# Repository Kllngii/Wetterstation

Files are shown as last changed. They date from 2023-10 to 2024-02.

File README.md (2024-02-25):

# Wetterstation

Mit einem WiFi-fähigen Mikrocontroller sollen verschiedene Sensordaten erfasst- und aufbereitet werden. 

Für die WiFi-Anbindung wird ein Raspberry Pi Pico W verwendet, der mit zwei Kernen und einem WLAN/Bluetooth Modul genug Leistung
zur Verfügung stellen kann. 

Die erfassten Daten werden auf einem lokalen (Touch)-Display ausgegeben, durch die WLAN-Fähigkeit könnten die Daten zukünftig auch an eine lokale Datenbank übertragen werden (MySQL/Docker, graphische Aufbereitung mit Grafana o.ä.)

# Sensoren
Folgende Sensoren werden verwendet (das Projekt ist beliebig skalierbar):
## Interne Messgruppe
- BME280 (Temperatur, Luftfeuchtigkeit, Luftdruck)
- MH-Z19C (CO2)
## Externe Messgruppe
- BME280 (Tempertur, Luftfeuchtigkeit, Luftdruck)
- DCF77-Empfänger (Uhrzeit und Wettervorhersage)
    - Der DCF77-Empfänger empfängt das Signal eines Zeitzeichensenders, das neben aktuellen Zeitinformationen eine Wettervorhersage beinhaltet. Diese ist allerdings verschlüsselt. verfügbaren GPIO Pins und Rechenleistung wird die Entschlüsselung auf dem internen Modul vorgenommen. Mit der Nutzung des ESP8266 als Außenmodul ist das ganz sinnvoll, weil der nicht so viele GPIO Pins frei verfügbar hat, ein MSP430 sollte das aber ohne grö0eren Rechenaufwand schaffen. Für die Entschlüsselung der Daten wird ein HKW581 Modul benötigt. 
## Eventuelle Erweiterungen
- DHT22 (Temperatur, Luftfeuchtigkeit)
- PT100/PT1000 (Zwei- oder Vierleitermessung, dazu Konstantstromquelle + rel. hochauflösender ADC (min. 16 bit))
- CCS811 (CO2 und flüchtige organische Verbindungen (TVOC))
- Niederschlagsmessung
- Windgeschwindigkeit und Windrichtung

# Struktur des Repos
- **LaTeX** [Dokumentation des Projekts](#dokumentation)
- **wetterstation-arduinosensor** [Arduino als Sensormodul](#arduino-als-sensormodul)
- **wetterstation-ui/** [Desktop App](#desktop-app)
- **slint-pico/** [Raspberry Pico mit Touchscreen als Interface](#raspberry-pico-mit-touchscreen-als-interface)
- **pcbs/** Hier findet man Schaltpläne und PCBs der Module als [KiCad](https://www.kicad.org) Projekt

# Desktop App






*TODO* Hier müsste man erklären was die Desktop-App ist 

# Dokumentation

Das LaTeX Dokument in diesem Ordner ist die Dokumentation des Projekts.

# Arduino als Sensormodul



Ein kleiner Beispiel-Sketch, der einen Arduino (Uno) benutzt, um die I2C- und Onewire-Sensoren anzusteuern.

# Raspberry Pico mit Touchscreen als Interface 





*TODO* Hier müsste man erklären was die Raspberry-Pi-Pico-App ist

# Aktivität
Repobeats analytics image

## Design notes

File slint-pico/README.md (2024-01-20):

# Raspberry Pico Wetterstation-UI





Nutzt [Slint](https://slint-ui.com), um eine hübsche UI auf einem Touch-Display anzuzeigen.

## Usage

### Auf einem PC testen (Simulator)
```
cargo run --features simulator
```

### Auf einem [RaspberryPi Pico](https://www.raspberrypi.com/products/raspberry-pi-pico/) mit [2.8 inch Waveshare Touch Screen](https://www.waveshare.com/pico-restouch-lcd-2.8.htm) ausführen:

#### 1. Target RP2040 hinzufügen:
```
rustup self update
rustup update stable
rustup target add thumbv6m-none-eabi
```

#### 2. UF2-Images-Tool für den RP2040 installieren:
```
cargo install elf2uf2-rs --locked
``` 

#### 3. Korrekten Runner auswählen:
In der Datei `.cargo/config.toml` muss der richtige Runner ausgewählt werden,
indem alle anderen Runner auskommentiert werden.
- Wird der Pico im USB-Bootloader-Modus angeschlossen: `elf2uf2-rs` auswählen
- Der Pico wird über eine Debug Probe geflasht: `probe-run` wählen

#### 4. Auf RPico ausführen:
```
cargo run --target=thumbv6m-none-eabi --features=pico --release
```

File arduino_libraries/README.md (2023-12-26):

# arduino_libraries

Hier liegen alle Bibliotheken, die in der Arduino IDE verwendet werden und im lokalen libraries-Ordner enthalten sind. 

DCF77 und CO2 gehören nicht dazu, weil sie modifiziert werden mussten und ohnehin schon Teil von

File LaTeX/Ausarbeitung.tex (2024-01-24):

\documentclass[a4paper,11pt]{article}
\usepackage[utf8]{inputenc} % Sonderzeichen schreiben können
\usepackage[ngerman]{babel} % Deutsche Abbildungszeichen
\usepackage{graphicx}   % Graphiken einfügen
\usepackage{fancyhdr}   % Für Kopf- und Fusszeile
\usepackage{geometry}   % Seitenränder definieren
\usepackage{tikz}       % Zum Regler zeichnen
\usepackage{multirow}   % Multirow in Tabellen
\usepackage{float}      % Um Bilder genau an diesem Punkt einzufuegen [H]
\usepackage{fancyvrb}   % Box um Verbatim Code
\usepackage{microtype}  % Automatische Anpassung der Zeilenmaße, dass unschöne Umbrüche vermieden werden
\usepackage{mathtools}  % Für Text auf/unter Pfeilen
\usepackage{pgfplots}   % Plot zusammen mit tikzpicture
\usepackage{makecell}   % Umbruch in tabellen
\usepackage{enumitem}   % Einruecken bei itemize verhindern
\usepackage{titlesec}   % Elemente unter subsubsection erzeugen
\usepackage{trfsigns}   % Transformationssymbole
\usepackage{amsmath}    % Umbruch in Formeln
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
\definecolor{codepurple}{rgb}{0.58,0,0.82}
\definecolor{backcolour}{rgb}{0.95,0.95,0.92}

\lstdefinestyle{mystyle}{
    backgroundcolor=\color{backcolour},   
    commentstyle=\color{codegreen},
    keywordstyle=\color{magenta},
    numberstyle=\tiny\color{codegray},
    stringstyle=\color{codepurple},
    basicstyle=\ttfamily\footnotesize,
    breakatwhitespace=false,         
    breaklines=true,                 
    captionpos=b,                    
    keepspaces=true,                 
    numbers=left,                    
    numbersep=5pt,                  
    showspaces=false,                
    showstringspaces=false,
    showtabs=false,                  
    tabsize=2
}

\lstset{literate=
	{°}{{\textdegree}}1 {µ}{{\textmu}}1
	{á}{{\'a}}1 {é}{{\'e}}1 {í}{{\'i}}1 {ó}{{\'o}}1 {ú}{{\'u}}1
	{Á}{{\'A}}1 {É}{{\'E}}1 {Í}{{\'I}}1 {Ó}{{\'O}}1 {Ú}{{\'U}}1
	{à}{{\`a}}1 {è}{{\`e}}1 {ì}{{\`i}}1 {ò}{{\`o}}1 {ù}{{\`u}}1
	{À}{{\`A}}1 {È}{{\`E}}1 {Ì}{{\`I}}1 {Ò}{{\`O}}1 {Ù}{{\`U}}1
	{ä}{{\"a}}1 {ë}{{\"e}}1 {ï}{{\"i}}1 {ö}{{\"o}}1 {ü}{{\"u}}1
	{Ä}{{\"A}}1 {Ë}{{\"E}}1 {Ï}{{\"I}}1 {Ö}{{\"O}}1 {Ü}{{\"U}}1
	{â}{{\^a}}1 {ê}{{\^e}}1 {î}{{\^i}}1 {ô}{{\^o}}1 {û}{{\^u}}1
	{Â}{{\^A}}1 {Ê}{{\^E}}1 {Î}{{\^I}}1 {Ô}{{\^O}}1 {Û}{{\^U}}1
	{ã}{{\~a}}1 {ẽ}{{\~e}}1 {ĩ}{{\~i}}1 {õ}{{\~o}}1 {ũ}{{\~u}}1
	{Ã}{{\~A}}1 {Ẽ}{{\~E}}1 {Ĩ}{{\~I}}1 {Õ}{{\~O}}1 {Ũ}{{\~U}}1
	{œ}{{\oe}}1 {Œ}{{\OE}}1 {æ}{{\ae}}1 {Æ}{{\AE}}1 {ß}{{\ss}}1
	{ű}{{\H{u}}}1 {Ű}{{\H{U}}}1 {ő}{{\H{o}}}1 {Ő}{{\H{O}}}1
	{ç}{{\c c}}1 {Ç}{{\c C}}1 {ø}{{\o}}1 {Ø}{{\O}}1 {å}{{\r a}}1 {Å}{{\r A}}1
	{€}{{\euro}}1 {£}{{\pounds}}1 {«}{{\guillemotleft}}1
	{»}{{\guillemotright}}1 {ñ}{{\~n}}1 {Ñ}{{\~N}}1 {¿}{{?`}}1 {¡}{{!`}}1 
}

\lstdefinelanguage{slint}{
	morekeywords={export, component, global, struct, inherits},
	sensitive=true,
	morecomment=[l]{//}, % line comment
	morecomment=[s]{/*}{*/}, % start delimiter, end delimiter
	morestring=[b]", % string quotes
	morestring=[d]',
}

\lstdefinelanguage{rust}{
	morekeywords={export, global, struct, loop, for, while, do, if, else, let, match, const, continue, break, None, Some, Option},
	sensitive=false,
	morecomment=[l]{//}, % line comment
	morecomment=[n]{/*}{*/}, % start delimiter, end delimiter, nested
	morestring=[b]", % string quotes
	morestring=[d]',
}

\lstset{style=mystyle}

\titleclass{\subsubsubsection}{straight}[\subsection]

\newcounter{subsubsubsection}[subsubsection]
\renewcommand\thesubsubsubsection{\thesubsubsection.\arabic{subsubsubsection}}
\renewcommand\theparagraph{\thesubsubsubsection.\arabic{paragraph}} % optional; useful if paragraphs are to be numbered

\titleformat{\subsubsubsection}
  {\normalfont\normalsize\bfseries}{\thesubsubsubsection}{1em}{}
\titlespacing*{\subsubsubsection}
{0pt}{3.25ex plus 1ex minus .2ex}{1.5ex plus .2ex}

\makeatletter
\renewcommand\paragraph{\@startsection{paragraph}{5}{\z@}%
  {3.25ex \@plus1ex \@minus.2ex}%
  {-1em}%
  {\normalfont\normalsize\bfseries}}
\renewcommand\subparagraph{\@startsection{subparagraph}{6}{\parindent}%
  {3.25ex \@plus1ex \@minus .2ex}%
  {-1em}%
  {\normalfont\normalsize\bfseries}}
\def\toclevel@subsubsubsection{4}
\def\toclevel@paragraph{5}
\def\toclevel@paragraph{6}
\def\l@subsubsubsection{\@dottedtocline{4}{7em}{4em}}
\def\l@paragraph{\@dottedtocline{5}{10em}{5em}}
\def\l@subparagraph{\@dottedtocline{6}{14em}{6em}}
\makeatother

\setcounter{secnumdepth}{4}
\setcounter{tocdepth}{4}

\newenvironment{nospaceflalign*}
 {\setlength{\abovedisplayskip}{0pt}\setlength{\belowdisplayskip}{0pt}%
  \csname flalign*\endcsname}
 {\csname endflalign*\endcsname\ignorespacesafterend}

\pagestyle{fancy}
\fancyhf{}
\setlength{\headheight}{28.1pt} % Höhe der Kopfzeile
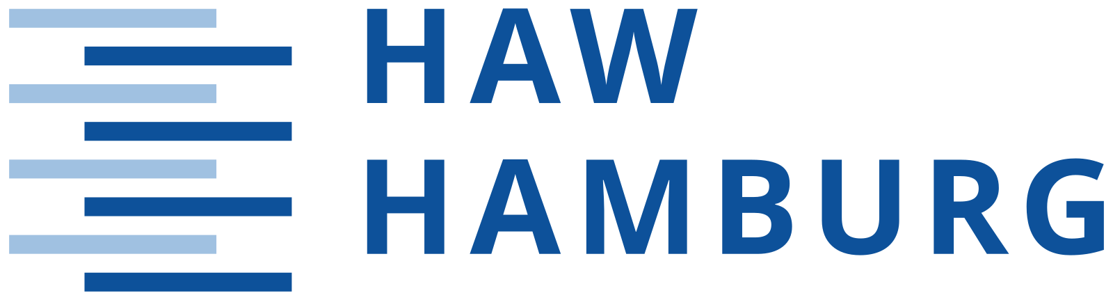
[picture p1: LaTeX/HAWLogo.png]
\rhead{}    % HAW Logo in Kopfzeile einfügen
\lhead{Bussysteme und Sensorik}  % Beschreibung in Kopfzeile

\renewcommand{\footrulewidth}{0.4pt}    % Linie in Fußzeile einfügen
\rfoot{\thepage}    % Seitenzahlen einfügen
\lfoot{Department Informations- und Elektrotechnik}   % Fusszeile linksbündig

\begin{document}
%Titelseite
\begin{titlepage}

  \begin{figure}
    \centering
    
  \end{figure}

  \vspace*{2cm}
  \centering
  {\scshape\Large Bussysteme und Sensorik \par}
  \vspace{1cm}
  {\scshape\LARGE Entwicklung eines Hubs zur Erfassung und graphischen Darstellung von Sensordaten \par}
  \vspace{0.5cm}
  {\scshape\large Wintersemester 2023/2024 \par}
  \vspace{5cm}

  \raggedright
  Ausarbeitung von:

  \vspace{0.5cm}
  Lasse Kelling \\
  2590639

  \vspace{0.2cm}
  Fabian Schmalenbach \\
  2514071

  \vspace{0.5cm}
  Abgabedatum: 24.01.2024

  \vspace{0.5cm}
  Prüfer: Prof. Dr. R. Fitz

\end{titlepage}

\newpage
\addtocontents{toc}{\protect\thispagestyle{empty}}
\tableofcontents
\thispagestyle{empty}
\newpage

\setcounter{page}{1}    % Seitenzähler sicherheitshalber zurücksetzen

\section{Projektbeschreibung}
\label{sub:projektbeschreibung}

Ziel des Projekts ist die Entwicklung eines Sensorhubs, der Sensordaten erfasst und auf einem Display darstellt.
Bei den Sensoren handelt es sich in erster Linie um Umweltdaten, die aktuelle Parameter der Umgebung erfassen.
Das Projekt kann daher grob mit einer Wetterstation verglichen werden. Zusätzlich zu den Sensordaten kann der Sensorhub
die aktuelle Zeit und eine Wettervorhersage über das DCF77-Signal empfangen. 

\subsection{Anforderungen}
\label{subsub:anforderungen}

Es wurden keine verpflichtenden Anforderungen gestellt, das Projekt soll thematisch aber zum Modul
"Bussysteme und Sensorik" passen. Daraus lassen sich für das spezifische Projekt Anforderungen stellen bzw. ableiten:

\begin{itemize}
  \item Verwendung eines oder mehrerer Bussysteme zur Kommunikation zwischen Mikrocontrollern
  \item Nutzung diverser Sensoren mit unterschiedlichen Anbindungen für Vielfältigkeit
  \item Analog zu herkömmlichen Wetterstationen, soll diese ebenfalls über einen Außensensor verfügen
  \item Die Wetterstation soll über eine Wettervorhersage verfügen
  \item Der Sensorhub soll skalier- und erweiterbar sein
\end{itemize}

\noindent
Aus diesen Anforderungen lassen sich direkt Vorgaben für das Projekt ableiten:
\begin{itemize}
  \item Nutzung mehrerer Mikrocontroller, die miteinander über ein Bussystem kommunizieren
  \item Verwendung digitaler Sensoren, die Standardprotokolle wie I2C, SPI oder UART unterstützen
  \item Entwicklung eines Außensensors, der drahtlos mit dem Sensorhub kommunizieren kann
  \item Anbindung des Sensorhubs ans Internet oder Empfang von Wettervorhersagen via Funk (DCF77)
  \item Nutzung ausreichend leistungsstarker Mikrocontroller, die genügend Leistungs- und Peripheriereserven haben, um weitere Geräte anzubinden
\end{itemize}

\subsection{Entwicklung}

Für die Entwicklung wurde ein Repository in GitHub angelegt, um die gemeinsame Arbeit am Projekt zu vereinfachen. Neben dem Quellcode sind dort auch Testprogramme
und die KiCad und Gerber Dateien für die Platinen abgelegt. 

\vspace{0.2cm}
\noindent
Das Repository ist unter folgendem Link erreichbar: \url{https://github.com/Kllngii/Wetterstation}.

\section{Systembeschreibung}
\label{sub:systembeschreibung}

\subsection{Systemaufbau}
\label{subsub:systemaufbau}

\begin{figure}[H]
  \centering
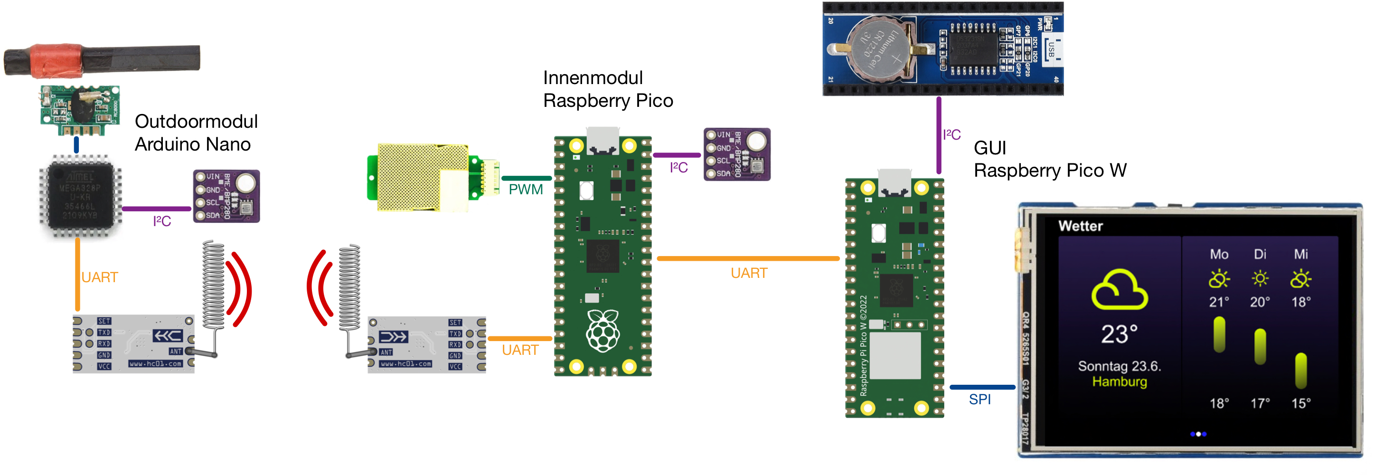
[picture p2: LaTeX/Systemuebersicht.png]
  
  \caption{Übersicht der Systemkomponenten}
  \label{fig:systemuebersicht}
\end{figure}

Die obige Abbildung \ref{fig:systemuebersicht} zeigt abstrakt alle Komponenten des Systems. Die jeweiligen Komponenten über dem Mikrocontroller Symbol
zeigen jeweils die angeschlossenen Sensoren bzw. Bildschirme. Ebenfalls ist grob die Kommunikation zwischen den Mikrocontrollern erkennbar. 

\vspace{0.2cm}
\noindent
Ganz links ist der Außensensor dargestellt, an den ein Sensor zur Messung von Temperatur, Luftfeuchtigkeit und Luftdruck angeschlossen ist. 
Außerdem verfügt dieser über eine Antenne, um das DCF77-Signal zu empfangen, welches die aktuelle Zeit und eine Wettervorhersage beinhaltet (siehe Abschnitt \ref{subsubsub:dcf77}).
Der Sensor sendet die empfangenen Daten zyklisch per 433 MHz Sender an den Sensorhub. 

\vspace{0.2cm}
\noindent
Der Sensorhub besteht aus zwei Mikrocontrollern, die über eine serielle Schnittstelle (UART) miteinander kommunizieren. Der in Abbildung \ref{fig:systemuebersicht} mittlere Mikrocontroller
empfängt die Daten des Außensensors und leitet diese weiter an den verbundenen Mikrocontroller. Da die Daten zur Wettervorhersage verschlüsselt sind und der Außensensor möglichst
wenig Energie verbrauchen soll, müssen die Daten vom Mikrocontroller entschlüsselt werden. Dazu werden die entsprechenden Datenpakete abgefangen, dekodiert und anschließend weitergesendet. 
Der Mikrocontroller verfügt außerdem wie der Außensensor über einen Sensor zur Messung von Temperatur, Luftfeuchtigkeit und Luftdruck (wobei der Luftdruck im Innenraum nicht gemessen wird). 
Zusätzlich ist ein CO2 Sensor verbaut, der die Konzentration im Raum misst. 

\vspace{0.2cm}
\noindent
In der Übersicht ganz rechts ist der Mikrocontroller, der alle Daten empfängt und auf einem Touchdisplay darstellt. Da der Sensor über ein WLAN-Modul verfügt, wäre theoretisch
zusätzlich die Übertragung der Daten per WLAN an einen Server o.ä. möglich, der alle Daten speichert und diese anderen Geräten zur Verfügung stellt. 

\subsection{Sensorik}
\label{subsub:sensorik}

Zur Erfassung der Umweltparameter werden aktuell zwei verschiedene Sensoren eingesetzt. Der BME280 erfasst Lufttemperatur, Luftfeuchtigkeit und Luftdruck. 
Der MHZ19C wird zur Erfassung der CO2 Konzentration im Raum eingesetzt. In den folgenden beiden Abschnitten werden die Sensoren beschrieben. 

\vspace{0.2cm}
\noindent
Das Außenmodul verfügt außerdem über eine 77,5 kHz Empfangsantenne, um das Zeitzeichensignal DCF77 zu empfangen. Daraus lässt sich die aktuelle Zeit ablesen,
außerdem wird eine Wettervorhersage mit übertragen, die ausgewertet wird. 

\subsubsection{BME280}
\label{subsubsub:bme280}

Beim BME280 handelt es sich um einen effizienten Sensor von Bosch, der zur Erfassung von Temperatur, Luftfeuchtigkeit und Luftdruck eingesetzt wird. 
Der Sensor verfügt über ein I2C und SPI Interface.
Beim zyklischen Auslesen aller Sensordaten mit 1 Hz liegt die Stromaufnahme laut Datenblatt bei 3,6 $\mu$A, weshalb sich der Sensor ideal für die Anwendung in Sensormodulen mit Batteriebetrieb eignet. 

\noindent
Der Sensor verfügt über die folgenden Messbereiche:
\begin{itemize}
  \item Temperatur: -40°C - +85°C ($\pm$ 0,5°C)
  \item Luftfeuchtigkeit: 0 - 100\% rel. Feuchtigkeit ($\pm$ 3\%)
  \item Druck: 250 - 1250 hPa ($\pm$ 1 hPa)
\end{itemize}

\noindent
Mit diesen Spezifikationen eignet sich der Sensor für die Anwendung im Innen- und Außenbereich. 

\noindent
Für das Projekt wird ein Sensorshield verwendet, welches nur den I2C Bus herausführt. Die Kommunikation mit dem Sensor erfolgt daher über I2C. 

\subsubsection{MHZ19C}
\label{subsubsub:mhz19c}

Der MHZ-19C ist ein Infrarot CO2-Sensor, der die CO2 Konzentration mittels nicht-dispersiver Infrarot-Spektroskopie misst. Dabei wird zyklisch mit einer Infrarotlampe
und einem Photosensor die CO2-Konzentration anhand der Reflexion des Lichts durch CO2 Partikel gemessen. 
Der Sensor verfügt über einen Messbereich von 400-5000 ppm, wobei die Genauigkeit $\pm$ 40ppm + 5\% des Messwerts beträgt. 
Da NDIR Sensoren zum Messwertdrift neigen, verfügt der Sensor über eine automatische Kalibrierung, die alle 24 Stunden erfolgt. Der Sensor ist daher für den Dauerbetrieb ausgelegt
und sollte dauerhaft aktiv sein. 
Die Aufheizzeit des Sensors beträgt eine Minute. 

\noindent
Der Sensor ist über eine UART-Schnittstelle konfigurier- und auslesbar, außerdem verfügt er über einen PWM Ausgang. 

\subsubsection{DCF77}
\label{subsubsub:dcf77}

Bei DCF77 handelt es sich um einen Zeitzeichensender in der Nähe von Frankfurt am Main, welcher mit einer Trägerfrequenz von 77,5 kHz ein Zeitsignal überträgt. 
Das Signal ist europaweit empfangbar und wird von den meisten Funkuhren als Referenzsignal verwendet.  

\noindent
Die Datenübertragung erfolgt durch einfache Amplitudenmodulation, indem die Amplitude für eine Dauer von 100 ms (Bit 0) oder 200 ms (Bit 1) auf 25\% der Ausgangsamplitude abgesenkt wird. 
Damit wird eine Bitrate von 1 Bit pro Sekunde erreicht. 

\begin{figure}[H]
  \centering
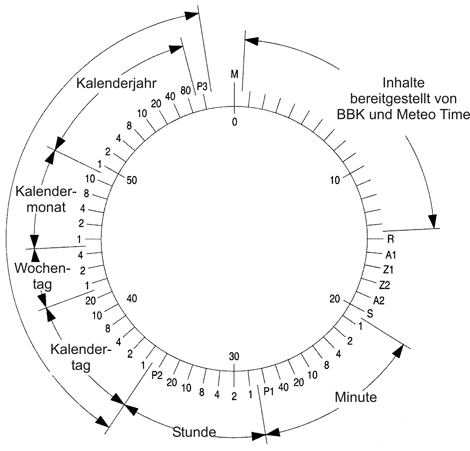
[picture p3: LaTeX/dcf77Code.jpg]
  
  \caption{Kodierungsschema der DCF77 Zeitinformationen \\
           \url{https://www.ptb.de/cms/ptb/fachabteilungen/abt4/fb-44/ag-442/verbreitung-der-gesetzlichen-zeit/dcf77/zeitcode.html}}
  \label{fig:dcf77Schema}
\end{figure}

\noindent
Abbildung \ref{fig:dcf77Schema} zeigt die Kodierung aller Datenbits innerhalb einer Minute. Daraus ist erkennbar, dass ein Datenpaket 59 Bits lang ist und
die Übertragung eine Minute dauert. Ein Paket beginnt zu jeder neuen Minute. In der letzten Sekunde einer Minute erfolgt keine Absenkung des Trägers, sodass anhand dessen
das Ende eines Pakets abgeleitet werden kann. 

\vspace{0.2cm}
\noindent
Die neue Minute beginnt mit dem nullten Bit, das immer den Wert null hat. Darauf folgen 14 Bits mit verschlüsselten Wetterinformationen der Firma MeteoTime.
Diese werden im nächsten Abschnitt weiter beschrieben. \\
Bit 15 (R) ist ein Rufbit, dass zur Alarmierung der PTB Mitarbeiter dient, wenn Unregelmäßigkeiten vorliegen. \\
Bit 16 (A1) zeigt an, dass am Ende der Stunde ein Wechsel von Sommer- zu Winterzeit stattfindet. \\
Bit 17 (Z1) ist eine Flag für die Sommerzeit. \\
Bit 18 (Z2) ist eine Flag für die Winterzeit. \\
Bit 19 (A2) zeigt an, dass am Ende der Stunde eine Schaltsekunde eingefügt wird. \\
Bit 20 (S) markiert den Beginn der Zeitinformationen und hat den Wert eins. 

\vspace{0.2cm}
\noindent
Wie schon aus der Abbildung hervorgeht, werden in den restlichen Sekunden Informationen zu Zeit und Datum übertragen, Minute, Stunde und Datum haben jeweils ein
Paritätsbit eingefügt, um Fehler erkennen zu können. Eine Fehlerkorrektur ist damit allerdings nicht möglich. 

\subsubsubsection{MeteoTime}
\label{subsubsubsub:meteotime}

MeteoTime versendet pro Minute 14 Bits mit Wetterinformationen, die von lizenzierten Geräten entschlüsselt- und verwendet werden können. 
Ein Informationspaket besteht aus 42 Bits und benötigt für die Übertragung somit drei Minuten. Ein Tag ist in fünf Abschnitte unterteilt, in denen
unterschiedliche Informationen übertragen werden. Da die Wettervorhersage 90 Regionen abdeckt, wird jede Vorhersage nur täglich einmal übertragen. \\
Es gilt folgende Aufteilung (MEZ, bei MESZ eine Stunde später): \\
23:00 Uhr - 04:59 Uhr: Aktueller Tag \\
05:00 Uhr - 10:59 Uhr: Folgender Tag \\
11:00 Uhr - 16:59 Uhr: Darauffolgender Tag \\
17:00 Uhr - 19:59 Uhr: Darauffolgender Tag \\
20:00 Uhr - 22:59 Uhr: Zusatzregionen mit 2-Tages Prognose. 

\vspace{0.2cm}
\noindent
Von den 90 Regionen erhalten 60 die viertägige Vorhersage, die restlichen 30 Regionen erhalten nur eine 2-Tages Vorhersage. \\
Innerhalb eines sechsstündigen Übertragungszeitraums werden für jede Region nacheinander die Höchst- und Tiefstwerte übertragen.

\noindent
Die Wettervorhersagen decken große Regionen ab, weshalb diese etwas ungenau sind. \\
Für Hamburg ist beispielsweise die Region Bremerhaven zugeteilt, der Bereich deckt alles vom westlichen Schleswig-Holstein bis zum Nordwesten der Niederlande ab. \\
Um im Fall eines Lesefehlers trotzdem eine Wettervorhersage anzeigen zu können, werden Ausweichzonen genutzt, dessen Wetterdaten stattdessen angezeigt wird. Schlägt
der Empfang für die Region Bremerhaven fehl, wird ausweichend die Vorhersage für Hannover übernommen. Werden auch diese Daten nicht korrekt empfangen, wird die dritte
Ausweichregion Rostock genutzt. 

\vspace{0.3cm}
\noindent
Für die Entschlüsselung der Wetterinformationen ist ein Dekodier-IC notwendig, welches vermutlich aus rückgekoppelten Schieberegistern besteht, um die Daten zu dekodieren. \\
Beim IC handelt es sich um das Modell HKW581 der Firma HKW, die auch Betreiber des MeteoTime Dienstes ist. Der IC ist nur in einem MSOP8 Format erhältlich (SMD).

\begin{figure}[H]
  \centering
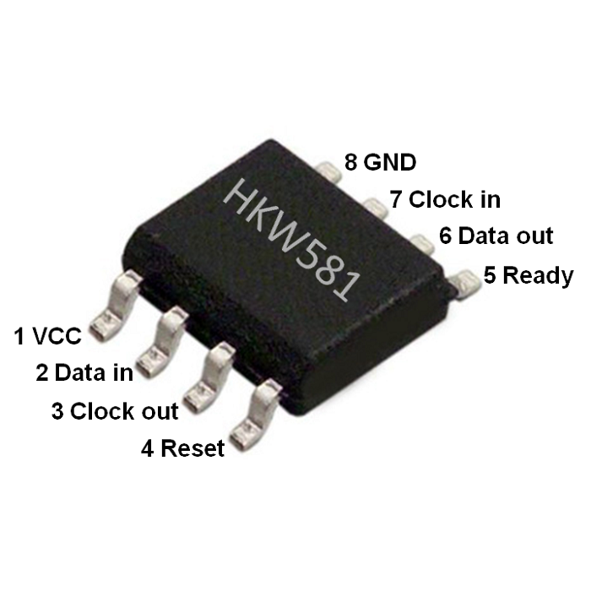
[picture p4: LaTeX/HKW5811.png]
  
  \caption{Dekodier-IC zum Entschlüsseln der Wettervorhersagen}
  \label{fig:hkw581}
\end{figure}

\noindent
Der IC verfügt über acht Pins, davon sind neben den Pins zur Spannungsversorgung und Daten Ein- und Ausgabe auch ein Clock IN und Clock OUT Pin vorhanden, damit die Bits
taktsynchron ein- bzw. ausgelesen werden. Beim Einlesen der Daten folgt das Clock OUT Signal dem Clock IN Signal, um anzuzeigen, dass die Erfassung des Bits erfolgreich war. 
Nachdem 82 Bits übertragen wurden, wird das Clock OUT Signal invertiert, bis alle Daten vom IC ausgelesen wurden. 
Neben einem Resetpin gibt es außerdem einen Ready-Pin, der anzeigt, dass der IC betriebsbereit ist. Anscheinend braucht der IC eine Aufwärmphase. 

\vspace{0.2cm}
\noindent
Als Eingabedaten benötigt der IC einen 82 Bit langen Datenstream, der sich wie folgt zusammensetzt:
\begin{itemize}
  \item Meteopaket 1 (14 Bit)
  \item Meteopaket 2 (14 Bit)
  \item Meteopaket 3 (14 Bit)
  \item Minute des ersten Pakets (aufgefüllt von 7 auf 8 Bit)
  \item Stunde des ersten Pakets (aufgefüllt von 6 auf 8 Bit)
  \item Kalendertag (aufgefüllt von 6 auf 8 Bit)
  \item Monat (5 Bit)
  \item Wochentag (3 Bit)
  \item Jahr (8 Bit)
\end{itemize}

\noindent
Als Ausgabe erhält man einen 22 Bit langen Datenstream mit den Wetterinformationen. Je nachdem, ob gerade ein Paket mit Höchst- oder Tiefstwerten gesendet wurde, 
ergeben sich unterschiedliche Informationen:

\vspace{0.2cm}
\noindent
Höchstwerte:
\begin{itemize}
  \item Wetter Tag (4 Bit)
  \item Wetter Nacht (4 Bit)
  \item Schweres Wetter (4 Bit)
  \item Niederschlagswahrscheinlichkeit(3 Bit)
  \item Wetteranomalie Tag (1 Bit)
  \item Temperatur Tag (6 Bit)
\end{itemize}

\vspace{0.2cm}
\noindent
Tiefstwerte:
\begin{itemize}
  \item Wetter Tag (4 Bit)
  \item Wetter Nacht (4 Bit)
  \item Windrichtung (4 Bit)
  \item Windstärke (3 Bit)
  \item Wetteranomalie Nacht (1 Bit)
  \item Temperatur Nacht (6 Bit)
\end{itemize}

\noindent
Die ausgegebenen Zahlenwerte sind wiederum einer Bezeichnung zugeordnet (z.B. Wetter Tag = 3 entspricht vorwiegend bewölkt).

\newpage
\subsection{Kommunikation}
\label{subsub:kommunikation}

Die Kommunikation zwischen den Mikrocontrollern erfolgt sowohl kabelgebunden, als auch drahtlos. Für die kabelgebundene Kommunikation wird UART mit einer Baudrate
von 115200 bd genutzt. Die Drahtloskommunikation erfolgt über einen 433 MHz Transmitter und Receiver, die jeweils im Halbduplexverfahren wie eine UART Schnittstelle
genutzt werden können. 

\subsubsection{Funkstrecke}
\label{subsubsub:funkstrecke}

Bei den Funkmodulen handelt es sich um "HC-12 Wireless RF communication module V2.4" Module. Diese versprechen eine Übertragungsdistanz von bis zu 1800 m
und eine einfache Ansteuerung über UART. \\
Die Module können jeweils sowohl Daten senden. 
Die Sendeleistung beträgt bis zu 100 mW und es können 100 verschiedene, einstellbare Kanäle genutzt werden (433,4 MHz bis 473 MHz). Die Baudrate ist zwischen 
1200 bps und 115200 bd wählbar. 

\vspace{0.2cm}
\noindent
Aktuell wird eine Baudrate von 9600 bd verwendet, um ein gutes Mittel zwischen Distanz und Geschwindigkeit zu erzielen. 

\vspace{0.5cm}
\noindent
Aufgrund der geltenden Bestimmungen in Deutschland darf nur mit maximal 10 mW gesendet werden, auch ist der wählbare Frequenzbereich teilweise nicht legal.
Es können nur die Kanäle 1 bis 4 genutzt werden. 

\subsubsection{Datenpakete}
\label{subsubsub:datenpakete}

Je nach übertragener Information werden unterschiedliche Datenpakete verwendet, die zur Identifikation jeweils mit einem 4-Byte langen Identifier ausgestattet sind. \\
Aktuell gibt es fünf verschiedene Identifier:
\begin{itemize}
  \item 'IBME' Internal BME
  \item 'EBME' External BME
  \item 'CO2.' Co2 Konzentration
  \item 'TIME' Aktuelle Zeit
  \item 'MTEO' Wettervorhersage
\end{itemize}

\noindent
Die Datenpakete haben unterschiedliche Längen und sind in Form von Structs in C definiert. Zum Senden der Daten werden diese dann in Char-Arrays umgewandelt. \\
Da die Structs unterschiedliche Datentypen beherbergen, fügt der Compiler normalerweise Padding Bytes ein, um gleichmäßige Adressabstände zu gewährleisten. 
Für die Verarbeitung und Übertragung der Datenpakete ist dies aber problematisch, weil beispielsweise die zu sendenden Datenpakete größer als nötig sind. 
Aus diesem Grund werden die Structs mit dem Attribut packed versehen, damit auf Padding Bytes verzichtet wird. 
Alle Datenpakete sind im folgenden dargestellt:

\newpage
\lstinputlisting[language=C, caption=Datenpakete]{dataTypes.h}

\noindent
Wie man im obigen Listing sieht, haben alle Datenpakete zusätzlich eine CRC-8 Prüfsumme, die bei der drahtlosen Datenübertragung 
zur Prüfung des Pakets verwendet wird. Bei der kabelgebundenen Datenübertragung zwischen beiden Mikrocontrollern
auf dem Innenmodul wird auf eine Prüfsumme verzichtet. 

\subsubsection{Übertragungsfehler}
\label{subsubsub:uebertragungsfehler}

Da die Meteotime Pakete jeweils nur einmal gesendet werden und ein Paketverlust bei der 433 MHz Datenübertragung problematisch wäre, wird, wie schon erwähnt, eine Prüfsumme
berechnet und übertragen und auf der Empfängerseite auf Richtigkeit überprüft. Ist die Prüfsumme fehlerhaft, sendet der Empfänger einen Retransmission-Befehl an den Sender.
Im folgenden ist die sowohl die fehlerfreie Übertragung von Paketen als auch die Übertragung mit mehrfacher Retransmission dargestellt. 

\begin{figure}[H]
  \centering
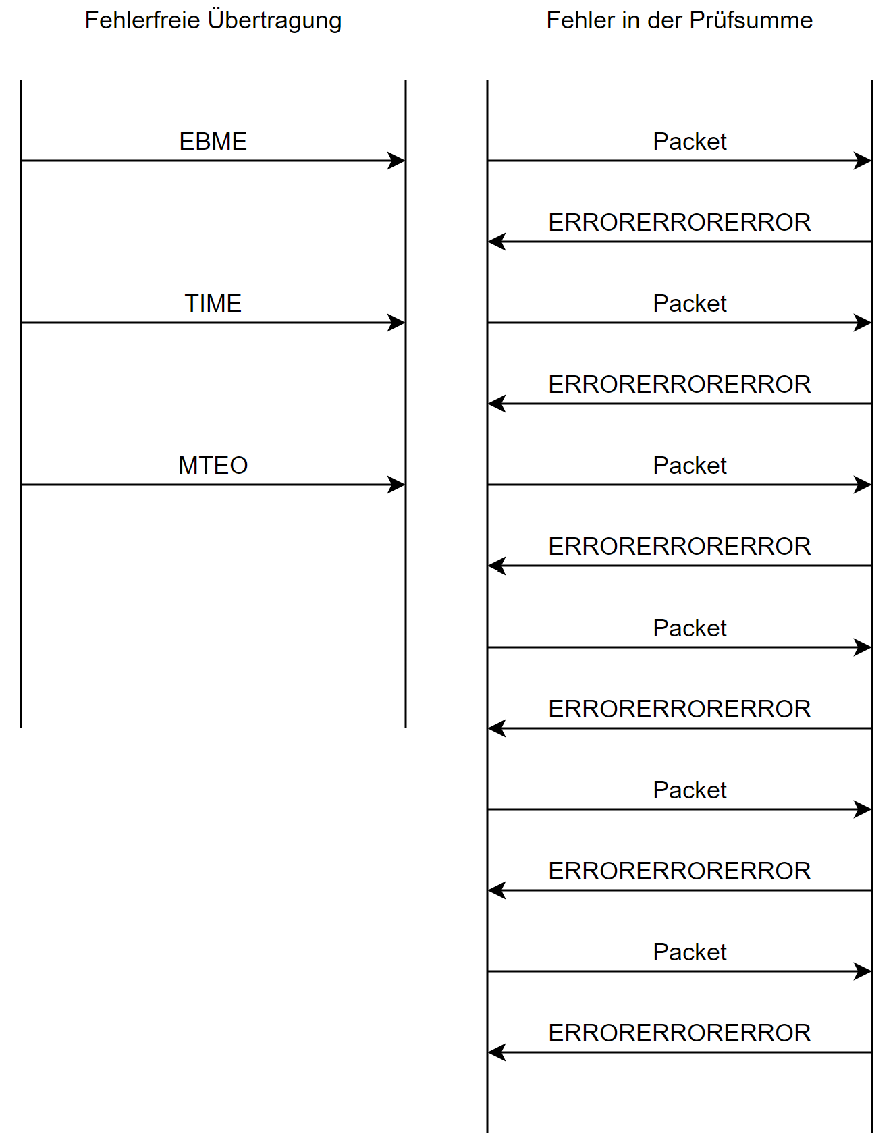
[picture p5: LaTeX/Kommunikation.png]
  
  \caption{Kommunikationsablauf zwischen Innen- und Außenmodul ohne und mit Übertragungsfehler}
  \label{fig:kommunikation}
\end{figure}

\noindent
Aus Abbildung \ref{fig:kommunikation} geht hervor, dass das Innenmodul den String ``ERRORERRORERROR'' an das Außenmodul sendet, wenn die Prüfsumme vom vorher gesendeten Paket
fehlerhaft ist. Der String wurde so gewählt, damit eventuell zufällig empfangene einzelne Bits anderer Quellen ignoriert werden und bei schlechtem Empfang zumindest ein paar Bytes
empfangen werden. Das Außenmodul reagiert mit einer Retransmission, wenn es fünf Bytes empfangen hat. \\
Die Zahl der Retransmissions ist auf fünf begrenzt, danach verwirft das Außenmodul das Paket. \\
Ein Retransmission Paket muss vom Innenmodul innerhalb von drei Sekunden an das Außenmodul gesendet werden, andernfalls nimmt das Außenmodul an, dass die Übertragung
erfolgreich war. 

\section{Modulbeschreibung}
\label{sub:modulbeschreibung}

\subsection{Sensormodul extern}
\label{subsub:sensorModul_ext}

Das externe Sensormodul soll im Außenbereich angebracht werden und möglichst effizient per Batterie betrieben werden können. \\
Wie schon aus den vorherigen Abschnitten hervorgeht, verfügt das Modul über einen BME280 für Temperatur, Luftfeuchtigkeit und Luftdruck
und eine Antenne zum Empfang des DCF77 Signals. Die empfangenen Daten werden dann zyklisch via 433 MHz an den Sensorhub gesendet. Die DCF77 Antenne
ist im Außenmodul untergebracht, weil das Signal sehr anfällig für Störungen durch elektrische Geräte oder Abschirmung durch Metalle ist, 
die vor allem im Innenbereich vorkommen. Im Außenbereich ist der Empfang besser. 

\vspace{0.2cm}
\noindent
Für den DCF77 Empfang wird ein Shield verwendet, das eine auf 77,5 kHz abgestimmte Antenne hat und das Signal filtert und in saubere TTL Pegel umwandelt.
Im Mikrocontroller wird eine Bibliothek verwendet, die einen Interrupt mit Trigger auf steigende- und fallende Taktflanke verwendet, um die Dauer der Absenkung
des Trägersignals zu messen. In der letzten Sekunde einer Minute findet keine Absenkung statt, anhand dessen wird das Ende eines Datenpakets ermittelt.
Da in der letzten Sekunde einer Minute keine Absenkung stattfindet, kann anhand dessen das Ende eines Datenpakets ermittelt werden. 
Zum Ende jeder Minute wird das Paket auf Gültigkeit überprüft. Dazu werden zum einen die Paritätsbits auf den richtigen Wert überprüft, außerdem
wird geprüft, ob die Flag für die Sommerzeit den gegenteiligen Wert der Flag für die Winterzeit hat. 
Ist die Überprüfung in Ordnung, wird das Datenpaket für die Zeit aus dem erhaltenen Zeitstempel zusammengesetzt und versendet. \\
Alle drei Minuten ist außerdem ein Meteotime Paket fertig und kann durch den Dechiffrier-IC entschlüsselt werden. 

\vspace{0.2cm}
\noindent
Ein Ablaufdiagramm zur Beschreibung der Software ist im Anhang in \hyperref[pdf:ablaufExtern]{Abbildung \ref{pdf:ablaufExtern}} zu finden. Es wird zyklisch geprüft, ob ein Zeit, Meteo oder Sensorpaket
versendet werden kann und ob die Übertragung fehlerfrei abgelaufen ist. Die Dekodierung der Wetterdaten erfolgt in der Klasse Meteo, im Dekodierprozess nacheinander
jedes Bit des Pakets in den Decoder geschrieben und anschließend der Bitstream aus dem IC gelesen. War die Entschlüsselung der Daten fehlerhaft, gibt der Decoder den String
``100000000000000000000100'' aus. 

\vspace{0.2cm}
\noindent
Als Mikrocontroller wurde in ersten Tests zunächst ein ESP8266 verwendet. Da dieser einen relativ hohen Energieverbrauch von ca. 20 mA hat und zudem für
den Anwendungszweck leistungstechnisch überdimensioniert ist, wurde als Alternative ein energiesparender MSP430G2553 gewählt, der bei 1 MHz Takt nur
230 $\mu$A verbrauchen soll und sowohl einen UART, als auch I2C Bus hat. Damit wäre ein langfristiger Betrieb mit Batterie möglich gewesen. 
Aus Zeitgründen und wegen der fehlenden Portierungsmöglichkeit des ESP8266 Codes auf den MSP430 wurde stattdessen ein Arduino Nano gewählt, der einen ATmega328p
Mikrocontroller als Basis verwendet. Modifiziert man einige Teile am Board, lässt sich der Stromverbrauch laut einiger Quellen auf ca. 5 mA drosseln. 

\subsubsection{Platinenentwurf}
\label{subsubsub:platinenentwurfExtern}

Für beide Module wird eine Platine angefertigt, um das Projekt auch in der Realität anwendbar zu machen. Das Außenmodul ist für den Batteriebetrieb konzipiert
und daher mit einigen Aktivbauteilen ausgestattet. Die Bauteile wurden zusammen mit der Platine bei JLCPCB bestellt und dort bestückt. 

\subsubsubsection{Schaltplan}
\label{subsubsubsub:schaltplanExtern}

Der Schaltplan ist im Anhang in \hyperref[pdf:schaltplanExtern]{Abbildung \ref{pdf:schaltplanExtern}} dargestellt. Zentraler Bestandteil ist dabei der Mikrocontroller. 
Für die Spannungsregulierung werden zwei Schaltregler verwendet, die 5 V und 3,3 V aus der Batteriespannung generieren. Beide Schaltregler arbeiten bis zu einer Minimalspannung
von ca. 0,7 V, die angeschlossene Batterie kann also fast vollständig genutzt werden. Beide Schaltregler vertragen maximal 5,5 V am Eingang, weshalb als Spannungsquelle
drei Alkaline Batterien in Serie dienen sollen, die eine Spannung von ca. 4,5 V bereitstellen. 
Die Anschlusskabel des Batteriefachs werden an die Platine gelötet, dafür wurden je 4x4 mm große Pads gewählt. 
Als Batterien werden aktuell Mono D Zellen verwendet, die das Modul aufgrund ihrer Größe und des Gewichts klobig erscheinen lassen, durch die hohe Ladungsmenge von bis zu
21 Ah eine lange Laufzeit versprechen. Geht man von einem Stromfluss von 10 mA aus, kann das Modul damit über drei Monate betrieben werden. Im Vergleich zu kommerziellen
Wetterstationen liegt die Laufzeit damit trotzdem weit unterhalb des Durchschnitts.  

\vspace{0.2cm}
\noindent
An den Mikrocontroller sind wie vorher beschrieben der HKW581 IC, ein BME280, die 433 MHz- und die DCF77-Antenne angeschlossen. Zu Entwicklungszwecken sind einige 
Zusatzanschlüsse vorhanden, um Modifikationen möglich zu machen. \\
Der HKW581 ist im MSOP8 Format und damit relativ klein. Um den IC schon bei vorherigen Testaufbauten auf dem Steckbrett nutzen zu können, wurde dieser auf einen Adapter
gelötet, der die Anschlusspins auf einfache THT Pins adaptiert. Um den IC zu schonen, wird der Adapter auf der Platine verbaut. Zusätzlich besteht aber die Möglichkeit, 
später darauf zu verzichten und das Bauteil direkt auf der Platine fest zulöten. Diese Lösung findet sich ebenso auf dem später beschriebenen Innenmodul wieder, falls
auf das Außenmodul verzichtet werden soll. \\
Als BME280 soll in erster Linie ein fertiges Shield zum Aufstecken verwendet werden, da der private Bestand davon wesentlich höher ist. Zusätzlich kann manuell aber auch
direkt ein BME280 auf die Platine gelötet werden. Die entsprechenden Bauteile sind nicht platziert. \\
Es können zwei verschiedene Arten von DCF77 Antennen an den Mikrocontroller angeschlossen werden. Dabei wird unterschieden zwischen Shields mit drei- und vier Anschlüssen. 
Die Shields mit vier Anschlüssen verfügen zusätzlich über einen PON (Power On) Pin, über den das Modul an- und ausgeschaltet werden kann. Der Pin ist normalerweise Low-aktiv und wird daher auf Masse gelegt. 

\subsubsubsection{Platine}
\label{subsubsubsub:platineExtern}

Die Platine ist im Anhang in \hyperref[pdf:platineExtern]{Abbildung \ref{pdf:platineExtern}} und \hyperref[fig:platineExtern3D]{Abbildung \ref{fig:platineExtern3D}} dargestellt. Es handelt sich um eine einfache 2-Layer Platine mit Ground Plane
auf der Unterseite. An der Oberseite sind Befestigungsmöglichkeiten für die DCF77 Antenne vorgesehen (dort ist auch keine Ground Plane mehr, um Abschirmungen zu vermeiden). 
Im Test hat sich allerdings herausgestellt, dass die Antenne nichts empfängt, wenn sie auf der Platine angebracht ist. 

\newpage
\subsection{Modul intern}
\label{subsub:modulInt}

\subsubsection{Sensormodul}
\label{subsubsub:sensormodulInt}

Das interne Sensormodul darf im Gegensatz zum externen Modul mehr Energie verbrauchen, da es mehr Daten verarbeiten muss und über einen Netzanschluss verfügt. 
Das Modul empfängt die über 433 MHz gesendeten Daten und liest zusätzlich zyklisch den BME280 und CO2 Sensor aus.

\vspace{0.3cm}
\noindent
Als Mikrocontroller wird ein Raspberry Pi Pico verwendet, der mit zwei Kernen Multiprocessing erlaubt und damit die Reaktionszeiten beschleunigt. Der Mikrocontroller
verfügt über zwei UART Busse und zwei I2C Busse. Die beiden UART Busse werden für die Kommunikation mit dem Grafikmodul und dem 433 MHz Modul verwendet.

\noindent
Der verwendete CO2 Sensor verfügt zwar auch über eine UART-Schnittstelle, die zur Verfügung stehenden UART Emulatoren für den Mikrocontroller lieferten allerdings
falsche Daten. Aus diesem Grund wird der Duty Cycle des zur Verfügung stehenden PWM Pins genutzt. 
Eine Bibliothek für den Sensor liest den PWM Pins automatisch aus und konvertiert den Duty Cycle in eine CO2 Konzentration. Da das Auslesen des PWM Signals insbesondere bei hohen
Konzentrationen recht lang dauern kann, erfolgt dies ausschließlich über den zweiten Kern, der neue Werte global zur Verfügung stellt und dies über eine Flag signalisiert. 

\subsubsection{Grafikmodul}
\label{subsubsub:grafikmodulInt}

Das Grafikmodul wird beim Endprodukt zusammen mit dem \hyperref[subsubsub:sensormodulInt]{internen Sensormodul} als eine Baugruppe ausgeführt sein.
Hauptziel ist die grafische Aufarbeitung der über UART vom \hyperref[subsubsub:sensormodulInt]{internen Sensormodul} empfangenen Daten.
Hierfür wird ebenfalls ein Raspberry Pi Pico in der W-Variante eingesetzt.
Diese ist zusätzlich zu den Schnittstellen des Picos W-LAN (IEEE 802.11 b/g/n) und Bluetooth (5.2 LE) fähig, somit kann das Grafikmodul zukünftig ebenfalls die Rolle eines mqtt-Brokers übernehmen und die aufbereiteten Daten online abrufbar machen.
Für diese Aufgaben verfügt das Modul über einen externen RTC-Chip und ein 2,8 Zoll Touchdisplay.

\vspace{0.3cm}
\noindent
Anders als bei den Sensoren wird beim Grafikmodul kein C-Code verwendet sondern ausschließlich in Rust programmiert.
Embedded-Rust folgt dem Motto \textquoteleft safe, fast, concurrent – pick three\textquoteright.
Rust etabliert viele Konzepte, um die typischen Probleme, die mit vergessenen Sonderfällen einhergehen (dangling pointer, use after free, dead-locks, integer-overflow, uvm.) durch ein gutes Typsystem und einen modernen Compiler bereits zur Kompilierzeit auszuschließen.
Ein Embedded-Rust-Projekt, welches erfolgreich kompiliert, wird in der Praxis auf dem Mikrocontroller nie unerwartetes Verhalten aufweisen.
Trotzdem wird noch eine von C-Programmen gewohnte Performance erreicht.

\vspace{0.3cm}
\noindent
Durch die Verwendung von Rust kann ebenfalls die sehr moderne Bibliothek Slint für die graphische Darstellung verwendet werden. Diese kompiliert Slint-Strukturen zu Rust-Quelltext und stellt Schnittstellen bereit, um fertige Pixelbuffer zu erhalten.

\vspace{0.3cm}
\noindent
Slint-Strukturen gliedern sich in components, globals und structs.
Ein Component ist ein auf dem Display anzeigbarer Baustein.
Globals stellen einen Adapter zum Rust-Quelltext dar, da man die Daten dieser sowohl aus dem Slint-Skript, als auch aus dem Rust-Programm verändern kann.
Structs in Slint definieren wie Structs in C oder Rust eigene zusammengesetzte Datentypen.

\lstinputlisting[language=slint, caption=Beispiel eines components globals und structs]{gui.slint}

\vspace{0.3cm}
\noindent
Während Slint das Zeichnen der Grafikbausteine übernimmt, muss sich der selbstgeschriebene Code um folgende Funktionen kümmern:
\begin{itemize}
	\item Initialisierung der Peripherie und Anbindung von Slint
	\item Ansteuerung des RTC Moduls (per I2C)
	\item Übertragung der Pixel an das Display (per DMA SPI)
	\item Übertragung des Touchinputs an den Pico (per DMA SPI)
	\item Übertragung der Sensordaten (per UART)
\end{itemize}

\vspace{0.3cm}
\noindent
Um Rechenleistung einzusparen, ist der Großteil des Programms mithilfe der wfe und sev Anweisungen des Picos (\textbf{W}ait\textbf{F}or\textbf{E}vent und \textbf{S}et/\textbf{S}ignal\textbf{EV}ent) Event-basiert implementiert.
Ein entsprechendes Interrupt wird ausgelöst, wenn
\begin{enumerate}
	\item ein UART-Package vom \hyperref[subsubsub:sensormodulInt]{internen Sensormodul} empfangen wurde
	\item Bildinhalte sich verändert haben (beispielsweise die Uhrzeit jede volle Sekunde)
	\item der Touchscreen berührt wird
\end{enumerate}

\lstinputlisting[language=rust, caption=Eventloop mit wfe]{eventloop.rs}

\begin{figure}[H]
	\centering
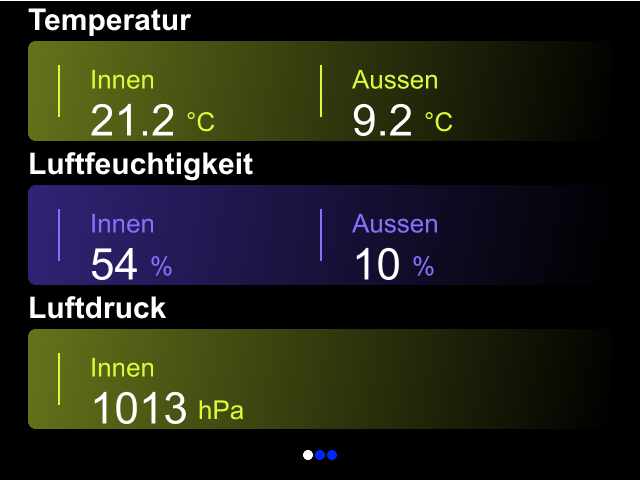
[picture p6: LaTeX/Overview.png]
	
	\caption{Übersichts-Seite des GUI}
	\label{fig:gui-overview}
\end{figure}

\begin{figure}[H]
	\centering
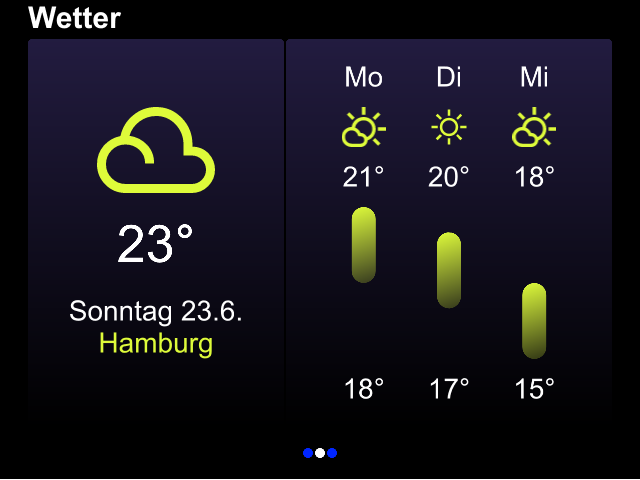
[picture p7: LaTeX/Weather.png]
	
	\caption{Wetter-Seite des GUI}
	\label{fig:gui-overview}
\end{figure}

\subsubsection{Platinenentwurf}
\label{subsubsub:platinenentwurfExtern} 

\subsubsubsection{Schaltplan}
\label{subsubsubsub:schaltplanExtern}

Der Schaltplan ist im Anhang in \hyperref[pdf:schaltplanIntern]{Abbildung \ref{pdf:schaltplanIntern}} dargestellt. Zentraler Bestandteil sind die beiden Mikrocontroller, 
die über eine UART Verbindung miteinander kommunizieren. Der Raspberry Pi Pico W, der das Grafikmodul beherbergt, steuert das aufsteckbare Touchdisplay. Zusätzlich wird
ein RTC Shield auf den Mikrocontroller gesteckt, um die aktuelle Zeit speichern zu können und Jitter zu minimieren. 
An den Raspberry Pi Pico, der die Sensoren ausliest, sind ein BME280, der CO2 Sensor und die 433 MHz Antenne angebunden. Zusätzlich kann hier ein HKW581 Modul integriert werden, 
dieses befindet sich im aktuellen Aufbau aber auf dem Außenmodul. Wie schon im externen Modul sind Möglichkeiten für das Shield und den Adapter vorbehalten. 
Der HKW581 auf dem internen Modul ist nur sinnvoll, falls auf das Außenmodul verzichtet werden soll (nicht geplant).

\subsubsubsection{Platine}
\label{subsubsubsub:platineExtern}

Die Platine ist im Anhang in \hyperref[pdf:platineIntern]{Abbildung \ref{pdf:platineIntern}} und \hyperref[fig:platineIntern3D]{Abbildung \ref{fig:platineIntern3D}} dargestellt. Es handelt sich um eine einfache 2-Layer Platine mit Ground Plane
auf der Unterseite. Hervorzuheben sind die Befestigungsmöglichkeiten des Displays sowie Bohrlöcher an den Außenseiten zur Befestigung im Gehäuse, o.ä..
Auf der Platine sind zwei Anschlüsse zur Spannungsversorgung der Platine eingeplant, einer führt das Kabel seitlich nach links, der andere nach unten. 
Der Anschluss nach unten kann praktisch sein, wenn die Platine aufgehängt werden sollte. Wird diese hingegen aufgestellt, ist eine seitlich Führung des Kabels nötig. 

\section{Funktionstest}
\label{sub:funktionstest}

Der Funktionstest ist wegen der graphischen Oberfläche auf dem Display nicht ganz einfach zu dokumentieren. 

\subsection{Test der Sensorik}
\label{subsub:test-sensorik}
Da der Raspberry Pi Pico im Gegensatz zu herkömmlichen Arduinos zusätzlich zu den UART Bussen serielle Daten über die USB Schnittstelle übertragen kann, 
sind einfache Print Ausgaben der empfangenen und weitergeleiteten Daten die einfachste Möglichkeit. 

\begin{figure}[H]
  \centering
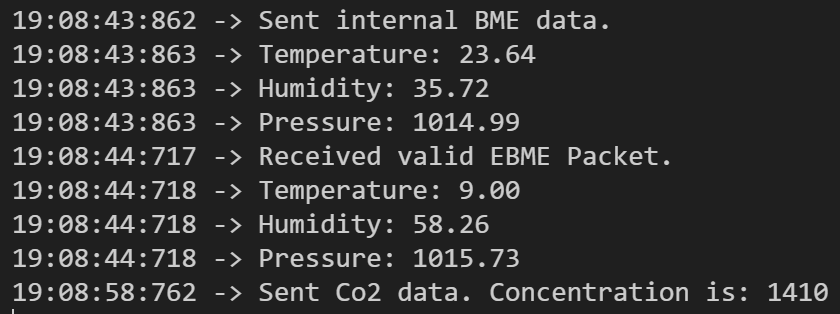
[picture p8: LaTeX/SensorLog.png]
  
  \caption{Logausgabe von internen und externen Sensordaten und CO2 Konzentration}
  \label{fig:sensorlog}
\end{figure}

\noindent
Abbildung \ref{fig:sensorlog} zeigt die Logausgabe von BME Daten des externen und internen Sensors und die aktuell gemessene CO2 Konzentration. 
``Received valid EBME Packet'' zeigt an, dass die übertragene Prüfsumme korrekt ist und keine Übertragungsfehler detektiert wurden. 
Die drei Pakete werden anschließend über die UART-Schnittstelle an das Grafikmodul weitergeleitet. 

\vspace{0.2cm}
\noindent
Ebenso werden die übertragenen Zeit- und Meteotimepakete in der Konsole ausgegeben:

\begin{figure}[H]
  \centering
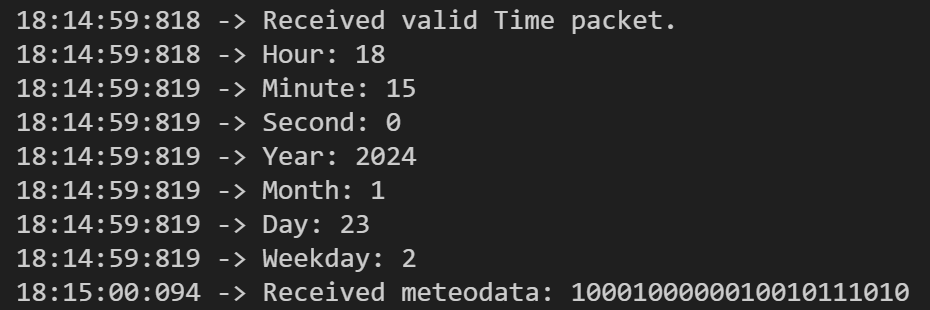
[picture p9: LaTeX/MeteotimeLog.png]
  
  \caption{Logausgabe eines Zeit- und Meteotimepakets}
  \label{fig:meteolog}
\end{figure}

\noindent
Ein Meteotime Paket wird nur übertragen, wenn es relevant für die Wetterstation ist (relevante Zone) und, wenn die Ausgabe des Dekodier-ICs fehlerfrei ist. 
Beim hier angezeigten Meteotime Paket handelt es sich um die Höchstwerte für den Tag + 3 für die Region Rostock. Das Paket ist 24 bit lang (die beiden führenden Nullen
werden hier nicht mit angezeigt). 

\vspace{0.2cm}
\noindent
Aus dem Paket lassen sich folgende Informationen ermitteln:

\begin{table}[H]
  \centering
  \begin{tabular}{|l|l|l|l|}
  \hline
  \textbf{Binärwert} & \textbf{Lage}                   & \textbf{Dezimalwert} & \textbf{Beschreibung} \\ \hline
  0010               & Tag                             & 4                    & bedeckt               \\ \hline
  0010               & Nacht                           & 4                    & bedeckt               \\ \hline
  0000               & Wetterextrema                   & 0                    & keine                 \\ \hline
  010                & Niederschlagswahrscheinlichkeit & 2                    & 30\%                  \\ \hline
  0                  & Wetteranomalie                  & 0                    & Nein                  \\ \hline
  101110             & Temperatur                      & 29                   & 7°C                   \\ \hline
  10                 & Dekoderstatus                   & -                    & OK                    \\ \hline
  \end{tabular}
  \caption{Informationen aus dem Meteotime Paket}
  \label{tab:meteopacket}
  \end{table}

\subsection{Test des Grafikmoduls}
Das Grafikmodul muss auf zweierlei Arten betrachtet werden, einerseits muss das Userinterface einfach bedienbar und übersichtlich sein, andererseits müssen auch die Rohdaten der Sensoren korrekt empfangen und verarbeitet werden. Das Erste lässt sich durch simples "durchklicken" der Menüs erledigen.

\vspace{0.2cm}
\noindent
Um die ankommenden Daten zu verifizieren müssen die Debugausgaben des versendenden Raspberry Picos (siehe \ref{subsub:test-sensorik}) als auch die des empfangenen und anzeigenden Raspberry Picos überwacht und abgeglichen werden.
Da der UI-Pico durch das Anzeigen der GUI ziemlich stark ausgelastet ist, kommt die Raspberry Pi Debug Probe zum Einsatz, welche einen seriellen Port (SerialWireDebug) über das CMSIS-DAP Protokoll öffnen kann, und die CPU des Picos nicht zusätzlich belastet.

\begin{figure}[H]
	\centering
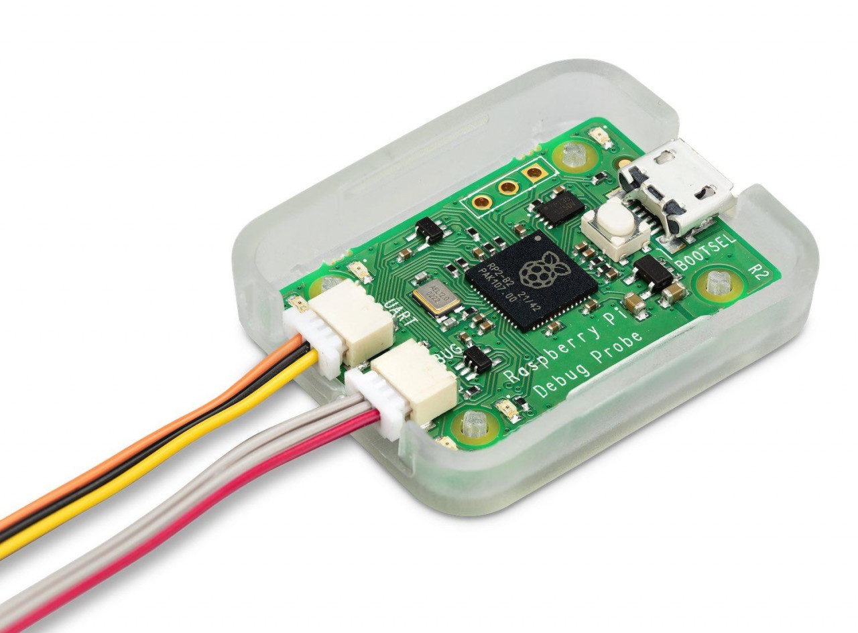
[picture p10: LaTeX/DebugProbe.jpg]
	
	\caption{Raspberry Pico Debug Probe Bildquelle: \href{https://www.berrybase.de/media/image/c2/87/07/ID_207742_orig_1280x1280.jpg}{berrybase.de}}
	\label{fig:debugprobe}
\end{figure}

\noindent
Nun kann im laufenden Betrieb oder mit einem Testprogramm validiert werden, dass die Daten korrekt übertragen und verarbeitet werden.

\begin{figure}[H]
	\centering
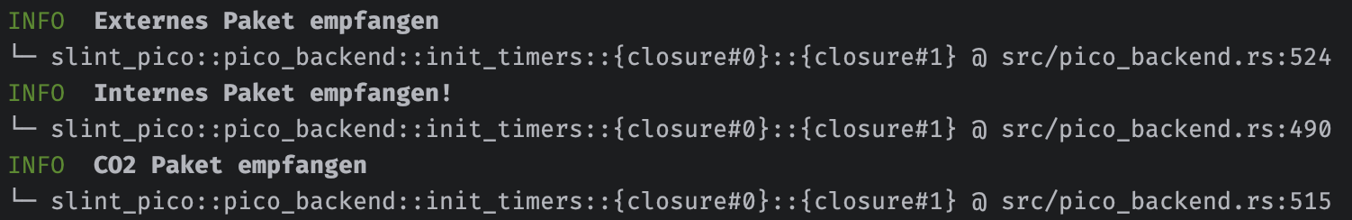
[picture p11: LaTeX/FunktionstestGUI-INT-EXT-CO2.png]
	
	\caption{Funktionstest für BME280-Sensoren und CO2-Sensor}
	\label{fig:funktionstest-dcf-meteo}
\end{figure}

\section{Fazit}
\label{sub:fazit}

Zum Ende des Projekts ist eine vollständige Wetterstation mit funktionierendem Außenmodul entwickelt und funktionstüchtig. Mit geeigneten Gehäusen sind beide
Module theoretisch für den Langzeitgebrauch geeignet und in einer realen Umgebung einsetzbar. Das Projekt kann damit als Erfolg gewertet werden, 
weil die zu Beginn aufgestellten Anforderungen erfüllt wurden. 
Im Entwicklungsprozess hat sich insbesondere gezeigt, dass das DCF Signal sehr anfällig für Störungen ist und auf die korrekte Ausrichtung der Antenne und einen
geeigneten Aufstellort geachtet werden muss (Antenne sollte in waagerechter Position sein und quer in Richtung Frankfurt a.M. ausgerichtet werden). Damit
erklärt sich auch, warum herkömmliche Funkuhren häufig kein Signal in Innenräumen empfangen. 

\vspace{0.2cm}
\noindent
Sollte das Projekt weiterverfolgt werden, kann im nächsten Iterationsschritt ein effizienterer Mikrocontroller in das Außenmodul eingesetzt werden (MSP430 o.ä.)
und weitestgehend auf Shields verzichtet werden, um die Abmessungen der Platinen zu reduzieren. Damit ließe sich die Professionalität weiter steigern. 

\clearpage
\appendix

\section{Ablaufdiagramm externes Modul}
\label{subapp:ablaufExt}

\begin{figure}[H]
  \centering
  
\end{figure}

\begin{figure}[H]
  \centering
  
\end{figure}

\begin{figure}[H]
  \centering
  
  \caption{Abstraktes Ablaufdiagramm zur Beschreibung des Codes auf dem externen Sensormodul}
  \label{pdf:ablaufExtern}
\end{figure}

\clearpage
\section{Schaltplan externes Modul}

\begin{figure}[H]
  \centering
  
  \caption{Schaltplan des externen Moduls}
  \label{pdf:schaltplanExtern}
\end{figure}

\clearpage
\section{Platine externes Modul}
\subsection{2D Ansicht}

\begin{figure}[H]
  \centering
  
  \caption{2D Ansicht des Platinenentwurfs}
  \label{pdf:platineExtern}
\end{figure}

\clearpage
\subsection{3D Ansicht}

\begin{figure}[H]
  \centering
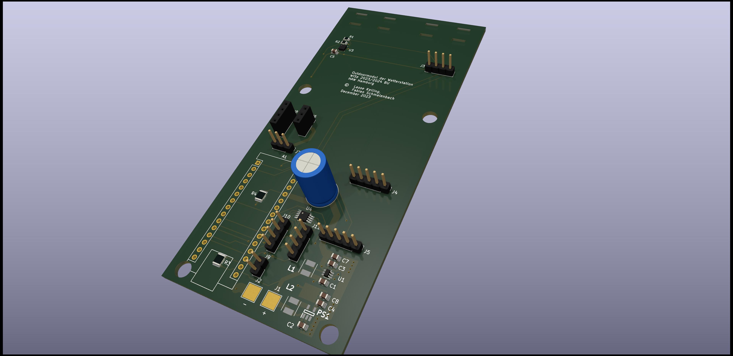
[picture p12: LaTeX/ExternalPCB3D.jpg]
  
  \caption{3D Ansicht des Platinenentwurfs}
  \label{fig:platineExtern3D}
\end{figure}

\clearpage
\section{Ablaufdiagramm internes Sensormodul}

\begin{figure}[H]
  \centering
  
\end{figure}

\begin{figure}[H]
  \centering
  
  \caption{Abstraktes Ablaufdiagramm zur Beschreibung des Codes auf dem internen Sensormodul (Core 0)}
  \label{pdf:ablaufIntern}
\end{figure}

\clearpage
\begin{figure}[H]
  \centering
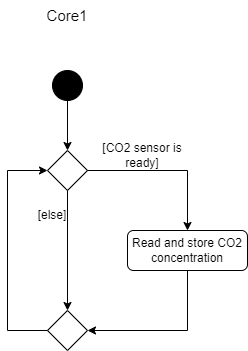
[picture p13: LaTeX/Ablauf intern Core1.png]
  
  \caption{Abstraktes Ablaufdiagramm zur Beschreibung des Codes auf dem internen Sensormodul (Core 1)}
  \label{pdf:ablaufInternCore1}
\end{figure}

\clearpage
\section{Schaltplan internes Modul}

\begin{figure}[H]
  \centering
  
  \caption{Schaltplan des internen Moduls}
  \label{pdf:schaltplanIntern}
\end{figure}

\clearpage
\section{Platine internes Modul}

\subsection{2D Ansicht}

\begin{figure}[H]
  \centering
  
  \caption{2D Ansicht des Platinenentwurfs}
  \label{pdf:platineIntern}
\end{figure}

\clearpage
\subsection{3D Ansicht}

\begin{figure}[H]
  \centering
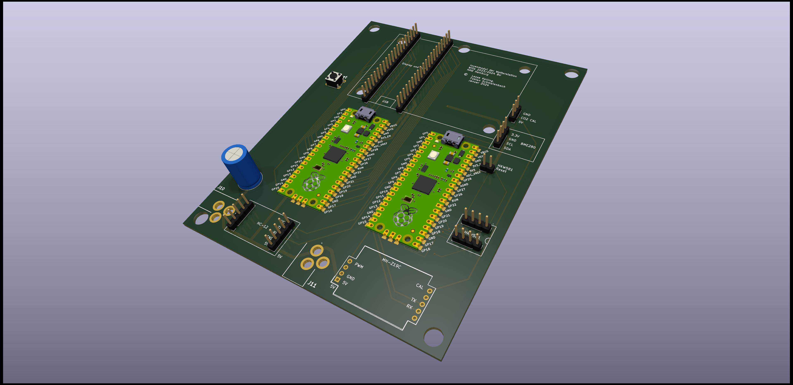
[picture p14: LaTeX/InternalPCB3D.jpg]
  
  \caption{3D Ansicht des Platinenentwurfs}
  \label{fig:platineIntern3D}
\end{figure}

\end{document}

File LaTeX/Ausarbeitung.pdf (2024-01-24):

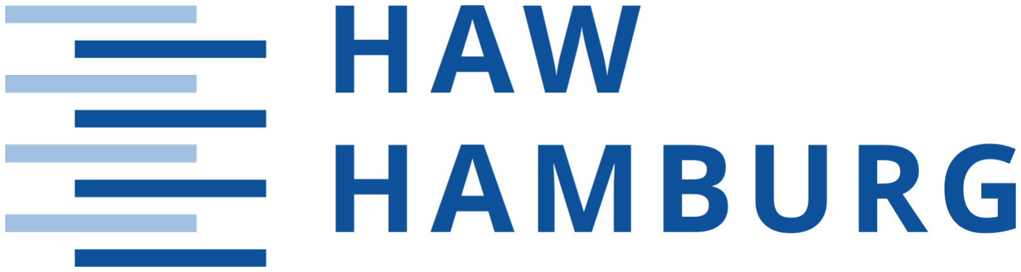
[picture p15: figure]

Bussysteme und Sensorik

Entwicklung eines Hubs zur Erfassung und

graphischen Darstellung von Sensordaten

Wintersemester 2023/2024

Ausarbeitung von:

Lasse Kelling
2590639

Fabian Schmalenbach
2514071

Abgabedatum: 24.01.2024

Prufer: Prof. Dr. R. Fitz ¨

## Inhaltsverzeichnis

1 Projektbeschreibung | 1
2 Systembeschreibung | 2
3 Modulbeschreibung | 10
4 Funktionstest | 17
5 Fazit | 19
A Ablaufdiagramm externes Modul | 21
B Schaltplan externes Modul | 24
C Platine externes Modul | 25
D Ablaufdiagramm internes Sensormodul | 28
E Schaltplan internes Modul | 31

Bussysteme und Sensorik

F Platine internes Modul | 32
Department Informations- und Elektrotechnik | 2

## 1 Projektbeschreibung

Ziel des Projekts ist die Entwicklung eines Sensorhubs, der Sensordaten erfasst und auf einem Display darstellt. Bei den Sensoren handelt es sich in erster Linie um Umweltdaten, die aktuelle Parameter der Umgebung erfassen. Das Projekt kann daher grob mit einer Wetterstation verglichen werden. Zusätzlich zu den Sensordaten kann der Sensorhub die aktuelle Zeit und eine Wettervorhersage uber das DCF77-Signal empfangen. ¨

### 1.1 Anforderungen

Es wurden keine verpflichtenden Anforderungen gestellt, das Projekt soll thematisch aber zum Modul ”Bussysteme und Sensorik”passen. Daraus lassen sich fur das spezifische Projekt ¨ Anforderungen stellen bzw. ableiten:

Verwendung eines oder mehrerer Bussysteme zur Kommunikation zwischen Mikrocontrollern

Nutzung diverser Sensoren mit unterschiedlichen Anbindungen fur Vielf ¨ | ältigkeit

Analog zu herkömmlichen Wetterstationen, soll diese ebenfalls uber einen Außensensor ¨ verfugen ¨

Die Wetterstation soll uber eine Wettervorhersage verf ¨ | ugen ¨

Der Sensorhub soll skalier- und erweiterbar sein

Aus diesen Anforderungen lassen sich direkt Vorgaben fur das Projekt ableiten: ¨

Nutzung mehrerer Mikrocontroller, die miteinander uber ein Bussystem kommunizieren ¨

Verwendung digitaler Sensoren, die Standardprotokolle wie I2C, SPI oder UART un-terstutzen ¨

Entwicklung eines Außensensors, der drahtlos mit dem Sensorhub kommunizieren kann

Anbindung des Sensorhubs ans Internet oder Empfang von Wettervorhersagen via Funk (DCF77)

Nutzung ausreichend leistungsstarker Mikrocontroller, die genugend Leistungs- und Peri- ¨ pheriereserven haben, um weitere Geräte anzubinden

### 1.2 Entwicklung

Fur die Entwicklung wurde ein Repository in GitHub angelegt, um die gemeinsame Arbeit am ¨ Projekt zu vereinfachen. Neben dem Quellcode sind dort auch Testprogramme und die KiCad und Gerber Dateien fur die Platinen abgelegt. ¨

Das Repository ist unter folgendem Link erreichbar: https://github.com/Kllngii/Wetterstation.

## 2 Systembeschreibung

### 2.1 Systemaufbau


Abbildung 1: Ubersicht der Systemkomponenten ¨

Die obige Abbildung 1 zeigt abstrakt alle Komponenten des Systems. Die jeweiligen Komponenten uber dem Mikrocontroller Symbol zeigen jeweils die angeschlossenen Sensoren bzw. Bildschirme. ¨ Ebenfalls ist grob die Kommunikation zwischen den Mikrocontrollern erkennbar.

Ganz links ist der Außensensor dargestellt, an den ein Sensor zur Messung von Temperatur,
Luftfeuchtigkeit und Luftdruck angeschlossen ist. Außerdem verfugt dieser ¨ | | uber eine Antenne, um ¨
das DCF77-Signal zu empfangen, welches die aktuelle Zeit und eine Wettervorhersage beinhaltet (siehe Abschnitt 2.2.3). Der Sensor sendet die empfangenen Daten zyklisch per 433 MHz Sender an den Sensorhub.

Der Sensorhub besteht aus zwei Mikrocontrollern, die uber eine serielle Schnittstelle (UART) ¨ miteinander kommunizieren. Der in Abbildung 1 mittlere Mikrocontroller empfängt die Daten des Außensensors und leitet diese weiter an den verbundenen Mikrocontroller. Da die Daten zur
Wettervorhersage verschlusselt sind und der Außensensor m ¨ | öglichst wenig Energie verbrauchen
soll, mussen die Daten vom Mikrocontroller entschl ¨ | usselt werden. Dazu werden die entsprechenden ¨
Datenpakete abgefangen, dekodiert und anschließend weitergesendet. Der Mikrocontroller verfugt ¨ außerdem wie der Außensensor uber einen Sensor zur Messung von Temperatur, Luftfeuchtigkeit ¨ und Luftdruck (wobei der Luftdruck im Innenraum nicht gemessen wird). Zusätzlich ist ein CO2 Sensor verbaut, der die Konzentration im Raum misst.
In der Ubersicht ganz rechts ist der Mikrocontroller, der alle Daten empf ¨ | | ängt und auf einem
Touchdisplay darstellt. Da der Sensor uber ein WLAN-Modul verf ¨ | ugt, w ¨ | äre theoretisch zusätzlich
die Ubertragung der Daten per WLAN an einen Server o. ¨ | ä. möglich, der alle Daten speichert
und diese anderen Geräten zur Verfugung stellt. ¨

### 2.2 Sensorik

Zur Erfassung der Umweltparameter werden aktuell zwei verschiedene Sensoren eingesetzt. Der BME280 erfasst Lufttemperatur, Luftfeuchtigkeit und Luftdruck. Der MHZ19C wird zur Erfassung der CO2 Konzentration im Raum eingesetzt. In den folgenden beiden Abschnitten werden die Sensoren beschrieben.

Das Außenmodul verfugt außerdem ¨ | uber eine 77,5 kHz Empfangsantenne, um das Zeitzeichen- ¨
signal DCF77 zu empfangen. Daraus lässt sich die aktuelle Zeit ablesen, außerdem wird eine

Wettervorhersage mit ubertragen, die ausgewertet wird. ¨

### 2.2.1 BME280

Beim BME280 handelt es sich um einen effizienten Sensor von Bosch, der zur Erfassung von Temperatur, Luftfeuchtigkeit und Luftdruck eingesetzt wird. Der Sensor verfugt ¨ uber ein I2C ¨ und SPI Interface. Beim zyklischen Auslesen aller Sensordaten mit 1 Hz liegt die Stromaufnahme laut Datenblatt bei 3,6 µA, weshalb sich der Sensor ideal fur die Anwendung in Sensormodulen ¨ mit Batteriebetrieb eignet.
Der Sensor verfugt ¨ uber die folgenden Messbereiche: ¨

Temperatur: -40°C - +85°C (± 0,5°C)

Luftfeuchtigkeit: 0 - 100% rel. Feuchtigkeit (± 3%)

Druck: 250 - 1250 hPa (± 1 hPa)

Mit diesen Spezifikationen eignet sich der Sensor fur die Anwendung im Innen- und Außenbereich. ¨
Fur das Projekt wird ein Sensorshield verwendet, welches nur den I2C Bus herausf ¨ | | uhrt. Die ¨
Kommunikation mit dem Sensor erfolgt daher uber I2C. ¨

### 2.2.2 MHZ19C

Der MHZ-19C ist ein Infrarot CO2-Sensor, der die CO2 Konzentration mittels nicht-dispersiver Infrarot-Spektroskopie misst. Dabei wird zyklisch mit einer Infrarotlampe und einem Photosensor die CO2-Konzentration anhand der Reflexion des Lichts durch CO2 Partikel gemessen. Der
Sensor verfugt ¨ | uber einen Messbereich von 400-5000 ppm, wobei die Genauigkeit ¨ | ± 40ppm +
5% des Messwerts beträgt. Da NDIR Sensoren zum Messwertdrift neigen, verfugt der Sensor ¨
uber eine automatische Kalibrierung, die alle 24 Stunden erfolgt. Der Sensor ist daher f ¨ | | ur den ¨
Dauerbetrieb ausgelegt und sollte dauerhaft aktiv sein. Die Aufheizzeit des Sensors beträgt eine Minute.
Der Sensor ist uber eine UART-Schnittstelle konfigurier- und auslesbar, außerdem verf ¨ | ugt er ¨
uber einen PWM Ausgang. ¨

### 2.2.3 DCF77

Bei DCF77 handelt es sich um einen Zeitzeichensender in der Nähe von Frankfurt am Main, welcher mit einer Trägerfrequenz von 77,5 kHz ein Zeitsignal ubertr ¨ ägt. Das Signal ist europaweit empfangbar und wird von den meisten Funkuhren als Referenzsignal verwendet.
Die Datenubertragung erfolgt durch einfache Amplitudenmodulation, indem die Amplitude f ¨ | | ur ¨
eine Dauer von 100 ms (Bit 0) oder 200 ms (Bit 1) auf 25% der Ausgangsamplitude abgesenkt wird. Damit wird eine Bitrate von 1 Bit pro Sekunde erreicht.


Abbildung 2: Kodierungsschema der DCF77 Zeitinformationen https://www.ptb.de/cms/ptb/fachabteilungen/abt4/fb-44/ag-442/verbreitung-der-gesetzlichen-zeit/dcf77/zeitcode.html (https://www.ptb.de/cms/ptb/fachabteilungen/abt4/fb-44/ag-442/verbreitung-der-gesetzlichen-zeit/dcf77/zeitcode.html)

Abbildung 2 zeigt die Kodierung aller Datenbits innerhalb einer Minute. Daraus ist erkennbar, dass ein Datenpaket 59 Bits lang ist und die Ubertragung eine Minute dauert. Ein Paket beginnt ¨ zu jeder neuen Minute. In der letzten Sekunde einer Minute erfolgt keine Absenkung des Trägers, sodass anhand dessen das Ende eines Pakets abgeleitet werden kann.

Die neue Minute beginnt mit dem nullten Bit, das immer den Wert null hat. Darauf folgen 14
Bits mit verschlusselten Wetterinformationen der Firma MeteoTime. Diese werden im n ¨ | ächsten
Abschnitt weiter beschrieben.
Bit 15 (R) ist ein Rufbit, dass zur Alarmierung der PTB Mitarbeiter dient, wenn Unre-gelmäßigkeiten vorliegen.
Bit 16 (A1) zeigt an, dass am Ende der Stunde ein Wechsel von Sommer- zu Winterzeit stattfindet. Bit 17 (Z1) ist eine Flag fur die Sommerzeit. ¨
Bit 18 (Z2) ist eine Flag fur die Winterzeit. ¨
Bit 19 (A2) zeigt an, dass am Ende der Stunde eine Schaltsekunde eingefugt wird. ¨
Bit 20 (S) markiert den Beginn der Zeitinformationen und hat den Wert eins.

Wie schon aus der Abbildung hervorgeht, werden in den restlichen Sekunden Informationen zu
Zeit und Datum ubertragen, Minute, Stunde und Datum haben jeweils ein Parit ¨ | ätsbit eingefugt, ¨
um Fehler erkennen zu können. Eine Fehlerkorrektur ist damit allerdings nicht möglich.

### 2.2.3.1 MeteoTime

MeteoTime versendet pro Minute 14 Bits mit Wetterinformationen, die von lizenzierten Geräten
entschlusselt- und verwendet werden k ¨ | önnen. Ein Informationspaket besteht aus 42 Bits und

benötigt fur die ¨ | Ubertragung somit drei Minuten. Ein Tag ist in f ¨ | unf Abschnitte unterteilt, in ¨
denen unterschiedliche Informationen ubertragen werden. Da die Wettervorhersage 90 Regionen ¨ abdeckt, wird jede Vorhersage nur täglich einmal ubertragen. ¨
Es gilt folgende Aufteilung (MEZ, bei MESZ eine Stunde später):
23:00 Uhr - 04:59 Uhr: Aktueller Tag
05:00 Uhr - 10:59 Uhr: Folgender Tag
11:00 Uhr - 16:59 Uhr: Darauffolgender Tag
17:00 Uhr - 19:59 Uhr: Darauffolgender Tag
20:00 Uhr - 22:59 Uhr: Zusatzregionen mit 2-Tages Prognose.

Von den 90 Regionen erhalten 60 die viertägige Vorhersage, die restlichen 30 Regionen erhalten nur eine 2-Tages Vorhersage.
Innerhalb eines sechsstundigen ¨ | Ubertragungszeitraums werden f ¨ | ur jede Region nacheinander die ¨
Höchst- und Tiefstwerte ubertragen. ¨
Die Wettervorhersagen decken große Regionen ab, weshalb diese etwas ungenau sind.
Fur Hamburg ist beispielsweise die Region Bremerhaven zugeteilt, der Bereich deckt alles vom ¨ westlichen Schleswig-Holstein bis zum Nordwesten der Niederlande ab.
Um im Fall eines Lesefehlers trotzdem eine Wettervorhersage anzeigen zu können, werden Ausweichzonen genutzt, dessen Wetterdaten stattdessen angezeigt wird. Schlägt der Empfang
fur die Region Bremerhaven fehl, wird ausweichend die Vorhersage f ¨ | ur Hannover ¨ | ubernommen. ¨
Werden auch diese Daten nicht korrekt empfangen, wird die dritte Ausweichregion Rostock genutzt.
Fur die Entschl ¨ | usselung der Wetterinformationen ist ein Dekodier-IC notwendig, welches vermut- ¨
lich aus ruckgekoppelten Schieberegistern besteht, um die Daten zu dekodieren. ¨
Beim IC handelt es sich um das Modell HKW581 der Firma HKW, die auch Betreiber des MeteoTime Dienstes ist. Der IC ist nur in einem MSOP8 Format erhältlich (SMD).


Abbildung 3: Dekodier-IC zum Entschlusseln der Wettervorhersagen ¨

Der IC verfugt ¨ uber acht Pins, davon sind neben den Pins zur Spannungsversorgung und Daten ¨ Ein- und Ausgabe auch ein Clock IN und Clock OUT Pin vorhanden, damit die Bits taktsynchron ein- bzw. ausgelesen werden. Beim Einlesen der Daten folgt das Clock OUT Signal dem Clock IN Signal, um anzuzeigen, dass die Erfassung des Bits erfolgreich war. Nachdem 82 Bits ubertragen ¨ wurden, wird das Clock OUT Signal invertiert, bis alle Daten vom IC ausgelesen wurden. Neben einem Resetpin gibt es außerdem einen Ready-Pin, der anzeigt, dass der IC betriebsbereit ist. Anscheinend braucht der IC eine Aufwärmphase.

Als Eingabedaten benötigt der IC einen 82 Bit langen Datenstream, der sich wie folgt zusam-mensetzt:

Meteopaket 1 (14 Bit)

Meteopaket 2 (14 Bit)

Meteopaket 3 (14 Bit)

Minute des ersten Pakets (aufgefullt von 7 auf 8 Bit) ¨

Stunde des ersten Pakets (aufgefullt von 6 auf 8 Bit) ¨

Kalendertag (aufgefullt von 6 auf 8 Bit) ¨

Monat (5 Bit)

Wochentag (3 Bit)

Jahr (8 Bit)

Als Ausgabe erhält man einen 22 Bit langen Datenstream mit den Wetterinformationen. Je nachdem, ob gerade ein Paket mit Höchst- oder Tiefstwerten gesendet wurde, ergeben sich unterschiedliche Informationen:

Höchstwerte:

Wetter Tag (4 Bit)

Wetter Nacht (4 Bit)

Schweres Wetter (4 Bit)

Niederschlagswahrscheinlichkeit(3 Bit)

Wetteranomalie Tag (1 Bit)

Temperatur Tag (6 Bit)

Tiefstwerte:

Wetter Tag (4 Bit)

Wetter Nacht (4 Bit)

Windrichtung (4 Bit)

Windstärke (3 Bit)

Wetteranomalie Nacht (1 Bit)

Temperatur Nacht (6 Bit)

Die ausgegebenen Zahlenwerte sind wiederum einer Bezeichnung zugeordnet (z.B. Wetter Tag = 3 entspricht vorwiegend bewölkt).

### 2.3 Kommunikation

Die Kommunikation zwischen den Mikrocontrollern erfolgt sowohl kabelgebunden, als auch drahtlos. Fur die kabelgebundene Kommunikation wird UART mit einer Baudrate von 115200 ¨ bd genutzt. Die Drahtloskommunikation erfolgt uber einen 433 MHz Transmitter und Receiver, ¨ die jeweils im Halbduplexverfahren wie eine UART Schnittstelle genutzt werden können.

### 2.3.1 Funkstrecke

Bei den Funkmodulen handelt es sich um ”HC-12 Wireless RF communication module V2.4”Module. Diese versprechen eine Ubertragungsdistanz von bis zu 1800 m und eine einfache Ansteuerung ¨ uber UART. ¨
Die Module können jeweils sowohl Daten senden. Die Sendeleistung beträgt bis zu 100 mW und es können 100 verschiedene, einstellbare Kanäle genutzt werden (433,4 MHz bis 473 MHz). Die Baudrate ist zwischen 1200 bps und 115200 bd wählbar.

Aktuell wird eine Baudrate von 9600 bd verwendet, um ein gutes Mittel zwischen Distanz und Geschwindigkeit zu erzielen.

Aufgrund der geltenden Bestimmungen in Deutschland darf nur mit maximal 10 mW gesendet werden, auch ist der wählbare Frequenzbereich teilweise nicht legal. Es können nur die Kanäle 1 bis 4 genutzt werden.

### 2.3.2 Datenpakete

Je nach ubertragener Information werden unterschiedliche Datenpakete verwendet, die zur ¨ Identifikation jeweils mit einem 4-Byte langen Identifier ausgestattet sind.
Aktuell gibt es funf verschiedene Identifier: ¨

’IBME’ Internal BME

’EBME’ External BME

’CO2.’ Co2 Konzentration

’TIME’ Aktuelle Zeit

’MTEO’ Wettervorhersage

Die Datenpakete haben unterschiedliche Längen und sind in Form von Structs in C definiert. Zum Senden der Daten werden diese dann in Char-Arrays umgewandelt.
Da die Structs unterschiedliche Datentypen beherbergen, fugt der Compiler normalerweise ¨ Padding Bytes ein, um gleichmäßige Adressabstände zu gewährleisten. Fur die Verarbeitung und ¨ Ubertragung der Datenpakete ist dies aber problematisch, weil beispielsweise die zu sendenden ¨ Datenpakete größer als nötig sind. Aus diesem Grund werden die Structs mit dem Attribut packed versehen, damit auf Padding Bytes verzichtet wird. Alle Datenpakete sind im folgenden dargestellt:

1 | // Aktuelle Zeit
2 | typedef struct __attribute__ (( __packed__ ) ) {
3 | const char dataType [4];
4 | uint8_t hour ;
5 | uint8_t minute ;
6 | uint8_t second ;
7 | uint8_t year ;
8 | uint8_t month ;
9 | uint8_t day ;
10 | uint8_t weekDay ;
11 | uint8_t checksum ;
12 | } TimeStruct ;

13
14 | typedef union {
15 | char buf [ sizeof ( TimeStruct ) ];
16 | TimeStruct data ;
17 | } TimeSendBuf ;

18
19 | // Dekodierte Wetterdaten
20 | typedef struct __attribute__ (( __packed__ ) ) {
21 | const char dataType [4];
22 | uint32_t meteoData ;
23 | uint8_t checksum ;
24 | } MeteoDecodedStruct ;

25
26 | typedef union {
27 | char buf [ sizeof ( MeteoDecodedStruct ) ];
28 | MeteoDecodedStruct data ;
29 | } MeteoDecodedSendBuf ;

30
31 | // Sensordaten vom BME280
32 | typedef struct __attribute__ (( __packed__ ) ) {
33 | const char dataType [4];
34 | float temperature ;
35 | float humidity ;
36 | float pressure ;
37 | uint8_t checksum ;
38 | } BMEStruct ;

39
40 | typedef union {
41 | char buf [ sizeof ( BMEStruct ) ];
42 | BMEStruct data ;
43 | } BMESendBuf ;

44
45 | // CO2 Konzentration
46 | typedef struct __attribute__ (( __packed__ ) ) {
47 | const char dataType [4];
48 | int concentration ;
49 | } CO2Struct ;

50
51 | typedef union {
52 | char buf [ sizeof ( CO2Struct ) ];
53 | CO2Struct data ;
54 | } CO2SendBuf ;

Listing 1: Datenpakete

Wie man im obigen Listing sieht, haben alle Datenpakete zusätzlich eine CRC-8 Prufsumme, ¨
die bei der drahtlosen Datenubertragung zur Pr ¨ | ufung des Pakets verwendet wird. Bei der ¨
kabelgebundenen Datenubertragung zwischen beiden Mikrocontrollern auf dem Innenmodul wird ¨ auf eine Prufsumme verzichtet. ¨

### 2.3.3 Ubertragungsfehler ¨

Da die Meteotime Pakete jeweils nur einmal gesendet werden und ein Paketverlust bei der 433 MHz
Datenubertragung problematisch w ¨ | äre, wird, wie schon erwähnt, eine Prufsumme berechnet und ¨
ubertragen und auf der Empf ¨ | ängerseite auf Richtigkeit uberpr ¨ | uft. Ist die Pr ¨ | ufsumme fehlerhaft, ¨
sendet der Empfänger einen Retransmission-Befehl an den Sender. Im folgenden ist die sowohl die
fehlerfreie Ubertragung von Paketen als auch die ¨ | Ubertragung mit mehrfacher Retransmission ¨
dargestellt.

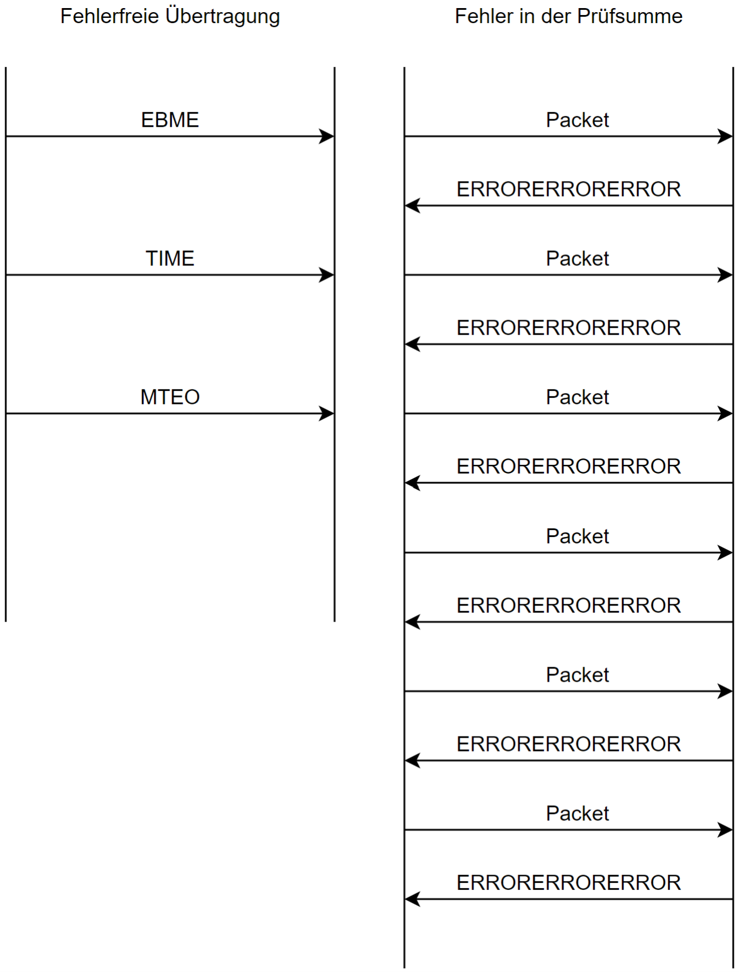
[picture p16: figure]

Abbildung 4: Kommunikationsablauf zwischen Innen- und Außenmodul ohne und mit Ubertragungsfehler ¨

Aus Abbildung 4 geht hervor, dass das Innenmodul den String “ERRORERRORERROR” an das Außenmodul sendet, wenn die Prufsumme vom vorher gesendeten Paket fehlerhaft ist. Der ¨ String wurde so gewählt, damit eventuell zufällig empfangene einzelne Bits anderer Quellen ignoriert werden und bei schlechtem Empfang zumindest ein paar Bytes empfangen werden. Das Außenmodul reagiert mit einer Retransmission, wenn es funf Bytes empfangen hat. ¨
Die Zahl der Retransmissions ist auf funf begrenzt, danach verwirft das Außenmodul das Paket. ¨ Ein Retransmission Paket muss vom Innenmodul innerhalb von drei Sekunden an das Außenmodul gesendet werden, andernfalls nimmt das Außenmodul an, dass die Ubertragung erfolgreich war. ¨

## 3 Modulbeschreibung

### 3.1 Sensormodul extern

Das externe Sensormodul soll im Außenbereich angebracht werden und möglichst effizient per Batterie betrieben werden können.
Wie schon aus den vorherigen Abschnitten hervorgeht, verfugt das Modul ¨ | uber einen BME280 f ¨ | ur ¨
Temperatur, Luftfeuchtigkeit und Luftdruck und eine Antenne zum Empfang des DCF77 Signals. Die empfangenen Daten werden dann zyklisch via 433 MHz an den Sensorhub gesendet. Die DCF77 Antenne ist im Außenmodul untergebracht, weil das Signal sehr anfällig fur St ¨ örungen durch elektrische Geräte oder Abschirmung durch Metalle ist, die vor allem im Innenbereich vorkommen. Im Außenbereich ist der Empfang besser.

Fur den DCF77 Empfang wird ein Shield verwendet, das eine auf 77,5 kHz abgestimmte Antenne ¨ hat und das Signal filtert und in saubere TTL Pegel umwandelt. Im Mikrocontroller wird eine Bibliothek verwendet, die einen Interrupt mit Trigger auf steigende- und fallende Taktflanke verwendet, um die Dauer der Absenkung des Trägersignals zu messen. In der letzten Sekunde einer Minute findet keine Absenkung statt, anhand dessen wird das Ende eines Datenpakets ermittelt. Da in der letzten Sekunde einer Minute keine Absenkung stattfindet, kann anhand dessen das Ende eines Datenpakets ermittelt werden. Zum Ende jeder Minute wird das Paket auf
Gultigkeit ¨ | uberpr ¨ | uft. Dazu werden zum einen die Parit ¨ | ätsbits auf den richtigen Wert uberpr ¨ | uft, ¨
außerdem wird gepruft, ob die Flag f ¨ | ur die Sommerzeit den gegenteiligen Wert der Flag f ¨ | ur ¨
die Winterzeit hat. Ist die Uberpr ¨ | ufung in Ordnung, wird das Datenpaket f ¨ | ur die Zeit aus dem ¨
erhaltenen Zeitstempel zusammengesetzt und versendet.
Alle drei Minuten ist außerdem ein Meteotime Paket fertig und kann durch den Dechiffrier-IC entschlusselt werden. ¨

Ein Ablaufdiagramm zur Beschreibung der Software ist im Anhang in Abbildung 11 zu finden. Es wird zyklisch gepruft, ob ein Zeit, Meteo oder Sensorpaket versendet werden kann und ob die ¨ Ubertragung fehlerfrei abgelaufen ist. Die Dekodierung der Wetterdaten erfolgt in der Klasse ¨ Meteo, im Dekodierprozess nacheinander jedes Bit des Pakets in den Decoder geschrieben und anschließend der Bitstream aus dem IC gelesen. War die Entschlusselung der Daten fehlerhaft, ¨ gibt der Decoder den String “100000000000000000000100” aus.

Als Mikrocontroller wurde in ersten Tests zunächst ein ESP8266 verwendet. Da dieser einen relativ hohen Energieverbrauch von ca. 20 mA hat und zudem fur den Anwendungszweck leistungstech- ¨
nisch uberdimensioniert ist, wurde als Alternative ein energiesparender MSP430G2553 gew ¨ | | | | ählt,
der bei 1 MHz Takt nur 230 µA verbrauchen soll und sowohl einen UART, als auch I2C Bus hat. Damit wäre ein langfristiger Betrieb mit Batterie möglich gewesen. Aus Zeitgrunden und wegen ¨ der fehlenden Portierungsmöglichkeit des ESP8266 Codes auf den MSP430 wurde stattdessen ein Arduino Nano gewählt, der einen ATmega328p Mikrocontroller als Basis verwendet. Modifiziert man einige Teile am Board, lässt sich der Stromverbrauch laut einiger Quellen auf ca. 5 mA drosseln.

### 3.1.1 Platinenentwurf

Fur beide Module wird eine Platine angefertigt, um das Projekt auch in der Realit ¨ | ät anwendbar
zu machen. Das Außenmodul ist fur den Batteriebetrieb konzipiert und daher mit einigen ¨ Aktivbauteilen ausgestattet. Die Bauteile wurden zusammen mit der Platine bei JLCPCB bestellt und dort bestuckt. ¨

### 3.1.1.1 Schaltplan

Der Schaltplan ist im Anhang in Abbildung 12 dargestellt. Zentraler Bestandteil ist dabei der Mikrocontroller. Fur die Spannungsregulierung werden zwei Schaltregler verwendet, die ¨ 5 V und 3,3 V aus der Batteriespannung generieren. Beide Schaltregler arbeiten bis zu einer Minimalspannung von ca. 0,7 V, die angeschlossene Batterie kann also fast vollständig genutzt werden. Beide Schaltregler vertragen maximal 5,5 V am Eingang, weshalb als Spannungsquelle drei Alkaline Batterien in Serie dienen sollen, die eine Spannung von ca. 4,5 V bereitstellen. Die Anschlusskabel des Batteriefachs werden an die Platine gelötet, dafur wurden je 4x4 mm ¨ große Pads gewählt. Als Batterien werden aktuell Mono D Zellen verwendet, die das Modul aufgrund ihrer Größe und des Gewichts klobig erscheinen lassen, durch die hohe Ladungsmenge von bis zu 21 Ah eine lange Laufzeit versprechen. Geht man von einem Stromfluss von 10 mA aus, kann das Modul damit uber drei Monate betrieben werden. Im Vergleich zu kommerziellen ¨ Wetterstationen liegt die Laufzeit damit trotzdem weit unterhalb des Durchschnitts.

An den Mikrocontroller sind wie vorher beschrieben der HKW581 IC, ein BME280, die 433 MHz-und die DCF77-Antenne angeschlossen. Zu Entwicklungszwecken sind einige Zusatzanschlusse ¨ vorhanden, um Modifikationen möglich zu machen.
Der HKW581 ist im MSOP8 Format und damit relativ klein. Um den IC schon bei vorherigen Testaufbauten auf dem Steckbrett nutzen zu können, wurde dieser auf einen Adapter gelötet, der die Anschlusspins auf einfache THT Pins adaptiert. Um den IC zu schonen, wird der Adapter auf der Platine verbaut. Zusätzlich besteht aber die Möglichkeit, später darauf zu verzichten und das Bauteil direkt auf der Platine fest zulöten. Diese Lösung findet sich ebenso auf dem später beschriebenen Innenmodul wieder, falls auf das Außenmodul verzichtet werden soll.
Als BME280 soll in erster Linie ein fertiges Shield zum Aufstecken verwendet werden, da der private Bestand davon wesentlich höher ist. Zusätzlich kann manuell aber auch direkt ein BME280 auf die Platine gelötet werden. Die entsprechenden Bauteile sind nicht platziert.
Es können zwei verschiedene Arten von DCF77 Antennen an den Mikrocontroller angeschlossen werden. Dabei wird unterschieden zwischen Shields mit drei- und vier Anschlussen. Die Shields ¨
mit vier Anschlussen verf ¨ | ugen zus ¨ | ätzlich uber einen PON (Power On) Pin, ¨ | uber den das Modul ¨
an- und ausgeschaltet werden kann. Der Pin ist normalerweise Low-aktiv und wird daher auf Masse gelegt.

### 3.1.1.2 Platine

Die Platine ist im Anhang in Abbildung 13 und Abbildung 14 dargestellt. Es handelt sich um eine einfache 2-Layer Platine mit Ground Plane auf der Unterseite. An der Oberseite sind Befestigungsmöglichkeiten fur die DCF77 Antenne vorgesehen (dort ist auch keine Ground Plane ¨ mehr, um Abschirmungen zu vermeiden). Im Test hat sich allerdings herausgestellt, dass die Antenne nichts empfängt, wenn sie auf der Platine angebracht ist.

### 3.2 Modul intern

### 3.2.1 Sensormodul

Das interne Sensormodul darf im Gegensatz zum externen Modul mehr Energie verbrauchen, da
es mehr Daten verarbeiten muss und uber einen Netzanschluss verf ¨ | ugt. Das Modul empf ¨ | ängt die
uber 433 MHz gesendeten Daten und liest zus ¨ | ätzlich zyklisch den BME280 und CO2 Sensor aus.

Als Mikrocontroller wird ein Raspberry Pi Pico verwendet, der mit zwei Kernen Multiprocessing erlaubt und damit die Reaktionszeiten beschleunigt. Der Mikrocontroller verfugt ¨ uber zwei UART ¨ Busse und zwei I2C Busse. Die beiden UART Busse werden fur die Kommunikation mit dem ¨ Grafikmodul und dem 433 MHz Modul verwendet.
Der verwendete CO2 Sensor verfugt zwar auch ¨ | uber eine UART-Schnittstelle, die zur Verf ¨ | ugung ¨
stehenden UART Emulatoren fur den Mikrocontroller lieferten allerdings falsche Daten. Aus ¨ diesem Grund wird der Duty Cycle des zur Verfugung stehenden PWM Pins genutzt. Eine ¨ Bibliothek fur den Sensor liest den PWM Pins automatisch aus und konvertiert den Duty ¨ Cycle in eine CO2 Konzentration. Da das Auslesen des PWM Signals insbesondere bei hohen Konzentrationen recht lang dauern kann, erfolgt dies ausschließlich uber den zweiten Kern, der ¨
neue Werte global zur Verfugung stellt und dies ¨ | uber eine Flag signalisiert. ¨

### 3.2.2 Grafikmodul

Das Grafikmodul wird beim Endprodukt zusammen mit dem internen Sensormodul als eine
Baugruppe ausgefuhrt sein. Hauptziel ist die grafische Aufarbeitung der ¨ | uber UART vom ¨ | internen
Sensormodul empfangenen Daten. Hierfur wird ebenfalls ein Raspberry Pi Pico in der W-Variante ¨ eingesetzt. Diese ist zusätzlich zu den Schnittstellen des Picos W-LAN (IEEE 802.11 b/g/n) und Bluetooth (5.2 LE) fähig, somit kann das Grafikmodul zukunftig ebenfalls die Rolle eines mqtt- ¨
Brokers ubernehmen und die aufbereiteten Daten online abrufbar machen. F ¨ | ur diese Aufgaben ¨
verfugt das Modul ¨ | uber einen externen RTC-Chip und ein 2,8 Zoll Touchdisplay. ¨

Anders als bei den Sensoren wird beim Grafikmodul kein C-Code verwendet sondern ausschließlich in Rust programmiert. Embedded-Rust folgt dem Motto ‘safe, fast, concurrent – pick three’. Rust etabliert viele Konzepte, um die typischen Probleme, die mit vergessenen Sonderfällen einhergehen (dangling pointer, use after free, dead-locks, integer-overflow, uvm.) durch ein gutes Typsystem und einen modernen Compiler bereits zur Kompilierzeit auszuschließen. Ein Embedded-Rust-Projekt, welches erfolgreich kompiliert, wird in der Praxis auf dem Mikrocontroller nie unerwartetes Verhalten aufweisen. Trotzdem wird noch eine von C-Programmen gewohnte Performance erreicht.

Durch die Verwendung von Rust kann ebenfalls die sehr moderne Bibliothek Slint fur die ¨ graphische Darstellung verwendet werden. Diese kompiliert Slint-Strukturen zu Rust-Quelltext und stellt Schnittstellen bereit, um fertige Pixelbuffer zu erhalten.

Slint-Strukturen gliedern sich in components, globals und structs. Ein Component ist ein auf dem Display anzeigbarer Baustein. Globals stellen einen Adapter zum Rust-Quelltext dar, da man die Daten dieser sowohl aus dem Slint-Skript, als auch aus dem Rust-Programm verändern kann. Structs in Slint definieren wie Structs in C oder Rust eigene zusammengesetzte Datentypen.

1 | export component AppWindow inherits Window {
2 | title : " Wetterstation ";
3 | min - width : 320 px ;
4 | min - height : 240 px ;
5 | background : Theme . palette . pure - black ;

6

7 | SmallMain {
8 | preferred - width : 100%;
9 | preferred - height : 100%;
10 | }
11 | }

12
13 | export global WeatherAdapter {
14 | in property < string > title : " Wetter ";
15 | in property < string > current - day : " Sonntag 23.6. ";
16 | in property <[ BarTileModel ] > week - model : [
17 | {
18 | title : "Mo",
19 | icon : Images . cloudy ,
20 | max : 21 ,
21 | min : 18 ,
22 | absolute - max : 21 ,
23 | absolute - min : 15 ,
24 | unit : "°C"
25 | } ,
26 | {
27 | title : "Di",
28 | icon : Images . sunny ,
29 | max : 20 ,
30 | min : 17 ,
31 | absolute - max : 21 ,
32 | absolute - min : 15 ,
33 | unit : "°C"
34 | } ,
35 | {
36 | title : "Mi",
37 | icon : Images . cloudy ,
38 | max : 18 ,
39 | min : 15 ,
40 | absolute - max : 21 ,
41 | absolute - min : 15 ,
42 | unit : "°C"
43 | }
44 | ];
45 | }

46
47 | export struct BarTileModel {
48 | title : string ,
49 | icon : image ,
50 | max : int ,
51 | min : int ,
52 | absolute - min : int ,
53 | absolute - max : int ,
54 | unit : string ,
55 | }
| Listing 2: Beispiel eines components globals und structs

Während Slint das Zeichnen der Grafikbausteine ubernimmt, muss sich der selbstgeschriebene ¨ Code um folgende Funktionen kummern: ¨

Initialisierung der Peripherie und Anbindung von Slint

Ansteuerung des RTC Moduls (per I2C)

Ubertragung der Pixel an das Display (per DMA SPI) ¨

Ubertragung des Touchinputs an den Pico (per DMA SPI) ¨

Ubertragung der Sensordaten (per UART) ¨

Um Rechenleistung einzusparen, ist der Großteil des Programms mithilfe der wfe und sev Anweisungen des Picos (WaitForEvent und Set/SignalEVent) Event-basiert implementiert. Ein entsprechendes Interrupt wird ausgelöst, wenn

1. ein UART-Package vom internen Sensormodul empfangen wurde
2. Bildinhalte sich verändert haben (beispielsweise die Uhrzeit jede volle Sekunde)
3. der Touchscreen beruhrt wird ¨
1 | loop {
2 | slint :: platform :: update_timers_and_animations () ;

3
4 | if let Some ( window ) = self . window . borrow () . clone () {
5 | window . draw_if_needed (| renderer | {
6 | let mut buffer_provider = self . buffer_provider . borrow_mut () ;
7 | renderer . render_by_line (& mut * buffer_provider ) ;
8 | buffer_provider . flush_frame () ;
9 | }) ;

10
11 | // handle touch event
12 | let button = PointerEventButton :: Left ;
13 | if let Some ( event ) = self
14 | . touch
15 | . borrow_mut ()
16 | . read ()
17 | . map_err (| _ | () )
18 | . unwrap ()
19 | . map (| point | {
20 | let position = slint :: PhysicalPosition :: new (
21 | ( point . x * DISPLAY_SIZE . width as f32 ) as _ ,
22 | ( point . y * DISPLAY_SIZE . height as f32 ) as _ ,
23 | )
24 | . to_logical ( window . scale_factor () ) ;
25 | match last_touch . replace ( position ) {
26 | Some ( _ ) = > WindowEvent :: PointerMoved { position } ,
27 | None = > WindowEvent :: PointerPressed { position , button } ,
28 | }
29 | })
30 | . or_else (|| {
31 | last_touch
32 | . take ()
33 | . map (| position | WindowEvent :: PointerReleased { position ,
| button })
34 | })
35 | {
36 | let is_pointer_release_event =
37 | matches !( event , WindowEvent :: PointerReleased { .. }) ;

38
39 | window . dispatch_event ( event ) ;

40
41 | // Eventuellen Hover - State ü ber Widgets zurü cknehmen
42 | if is_pointer_release_event {
43 | window . dispatch_event ( WindowEvent :: PointerExited ) ;
44 | }

45 | // Nach Touch - Input keinen Sleep ausl ö sen
46 | continue ;
47 | }

48
49 | if window . has_active_animations () {
50 | // Bei laufenden Animationen keinen Sleep ausl ö sen
51 | continue ;
52 | }
53 | }

54
55 | // voraussichtliche wfe - Zeit berechnen
56 | let sleep_duration = match slint :: platform :: duration_until_next_timer_update
| () {
57 | None = > None ,
58 | Some ( d ) = > {
59 | let micros = d . as_micros () as u32 ;
60 | if micros < 10 {
61 | // Wenn man weniger als 10µs schlafen will , merk es dir mit einem
| REIM , NEIN !
62 | continue ;
63 | } else {
64 | Some ( fugit :: MicrosDurationU32 :: micros ( micros ) )
65 | }
66 | }
67 | };

68
69 | // Sleep bis zum nä chsten Event ausl ö sen
70 | cortex_m :: interrupt :: free (| cs | {
71 | if let Some ( duration ) = sleep_duration {
72 | ALARM0 . borrow ( cs ) . borrow_mut () . as_mut () . unwrap () . schedule ( duration ) .
| unwrap () ;
73 | }

74
75 | IRQ_PIN
76 | . borrow ( cs )
77 | . borrow ()
78 | . as_ref ()
79 | . unwrap ()
80 | . set_interrupt_enabled ( GpioInterrupt :: LevelLow , true ) ;
81 | }) ;
82 | cortex_m :: asm :: wfe () ;
83 | }
| Listing 3: Eventloop mit wfe

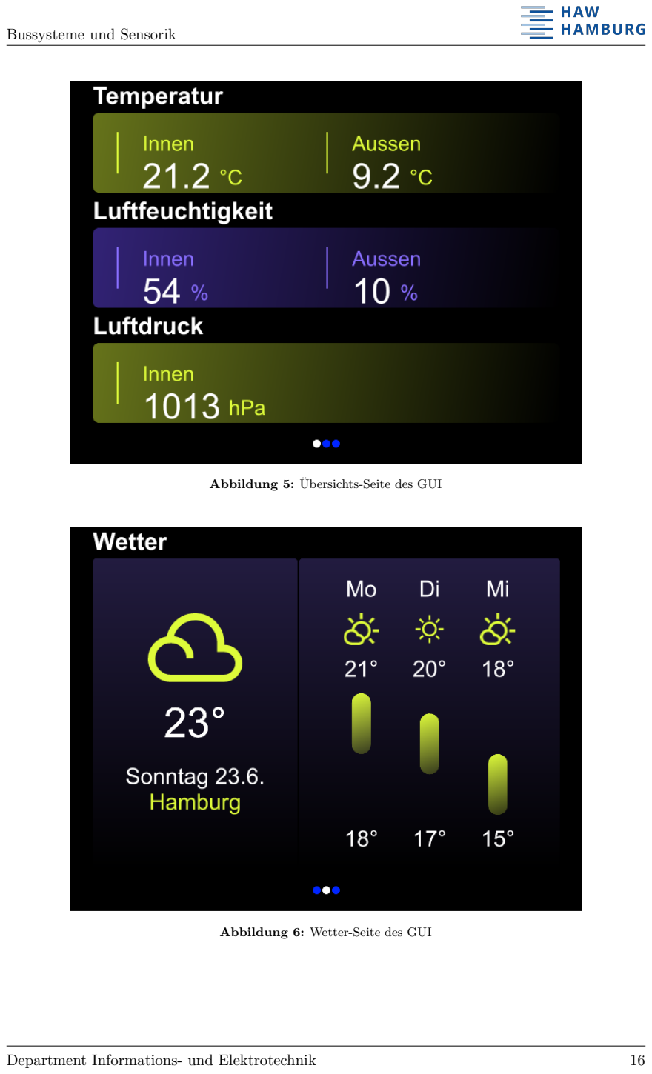
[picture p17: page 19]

Abbildung 5: Ubersichts-Seite des GUI ¨

Abbildung 6: Wetter-Seite des GUI

### 3.2.3 Platinenentwurf

### 3.2.3.1 Schaltplan

Der Schaltplan ist im Anhang in Abbildung 17 dargestellt. Zentraler Bestandteil sind die beiden Mikrocontroller, die uber eine UART Verbindung miteinander kommunizieren. Der Raspberry Pi ¨ Pico W, der das Grafikmodul beherbergt, steuert das aufsteckbare Touchdisplay. Zusätzlich wird ein RTC Shield auf den Mikrocontroller gesteckt, um die aktuelle Zeit speichern zu können und Jitter zu minimieren. An den Raspberry Pi Pico, der die Sensoren ausliest, sind ein BME280, der CO2 Sensor und die 433 MHz Antenne angebunden. Zusätzlich kann hier ein HKW581 Modul integriert werden, dieses befindet sich im aktuellen Aufbau aber auf dem Außenmodul. Wie schon im externen Modul sind Möglichkeiten fur das Shield und den Adapter vorbehalten. Der ¨ HKW581 auf dem internen Modul ist nur sinnvoll, falls auf das Außenmodul verzichtet werden soll (nicht geplant).

### 3.2.3.2 Platine

Die Platine ist im Anhang in Abbildung 18 und Abbildung 19 dargestellt. Es handelt sich um eine einfache 2-Layer Platine mit Ground Plane auf der Unterseite. Hervorzuheben sind die Befestigungsmöglichkeiten des Displays sowie Bohrlöcher an den Außenseiten zur Befestigung im Gehäuse, o.ä.. Auf der Platine sind zwei Anschlusse zur Spannungsversorgung der Platine ¨ eingeplant, einer fuhrt das Kabel seitlich nach links, der andere nach unten. Der Anschluss ¨ nach unten kann praktisch sein, wenn die Platine aufgehängt werden sollte. Wird diese hingegen
aufgestellt, ist eine seitlich Fuhrung des Kabels n ¨ | ötig.

## 4 Funktionstest

Der Funktionstest ist wegen der graphischen Oberfläche auf dem Display nicht ganz einfach zu dokumentieren.

### 4.1 Test der Sensorik

Da der Raspberry Pi Pico im Gegensatz zu herkömmlichen Arduinos zusätzlich zu den UART
Bussen serielle Daten uber die USB Schnittstelle ¨ | ubertragen kann, sind einfache Print Ausgaben ¨
der empfangenen und weitergeleiteten Daten die einfachste Möglichkeit.

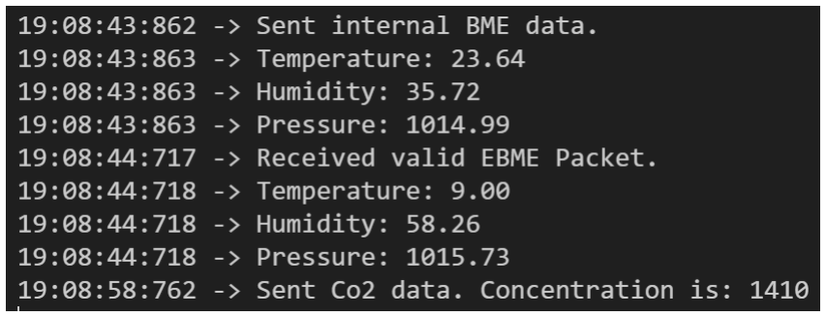
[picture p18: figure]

Abbildung 7: Logausgabe von internen und externen Sensordaten und CO2 Konzentration

Abbildung 7 zeigt die Logausgabe von BME Daten des externen und internen Sensors und die aktuell gemessene CO2 Konzentration. “Received valid EBME Packet” zeigt an, dass die

ubertragene Pr ¨ | ufsumme korrekt ist und keine ¨ | Ubertragungsfehler detektiert wurden. Die drei ¨
Pakete werden anschließend uber die UART-Schnittstelle an das Grafikmodul weitergeleitet. ¨

Ebenso werden die ubertragenen Zeit- und Meteotimepakete in der Konsole ausgegeben: ¨

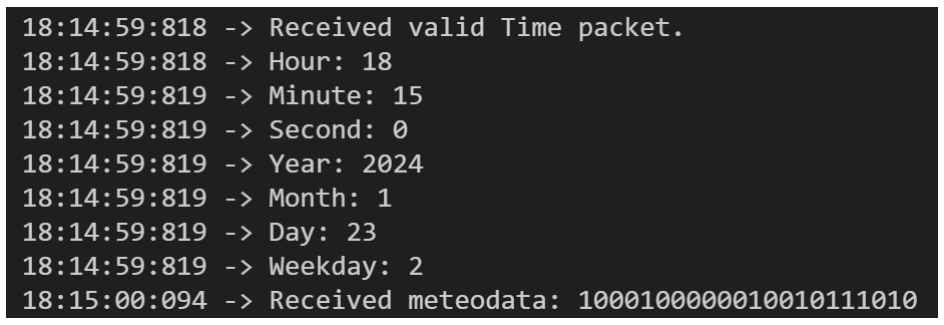
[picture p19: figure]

Abbildung 8: Logausgabe eines Zeit- und Meteotimepakets

Ein Meteotime Paket wird nur ubertragen, wenn es relevant f ¨ | ur die Wetterstation ist (relevante ¨
Zone) und, wenn die Ausgabe des Dekodier-ICs fehlerfrei ist. Beim hier angezeigten Meteotime
Paket handelt es sich um die Höchstwerte fur den Tag + 3 f ¨ | ur die Region Rostock. Das Paket ist ¨
24 bit lang (die beiden fuhrenden Nullen werden hier nicht mit angezeigt). ¨

Aus dem Paket lassen sich folgende Informationen ermitteln:

Binärwert | Lage | Dezimalwert | Beschreibung
0010 | Tag | 4 | bedeckt
0010 | Nacht | 4 | bedeckt
0000 | Wetterextrema | 0 | keine
010 | Niederschlagswahrscheinlichkeit | 2 | 30%
0 | Wetteranomalie | 0 | Nein
101110 | Temperatur | 29 | 7°C
10 | Dekoderstatus | - | OK

Tabelle 1: Informationen aus dem Meteotime Paket

### 4.2 Test des Grafikmoduls

Das Grafikmodul muss auf zweierlei Arten betrachtet werden, einerseits muss das Userinterface
einfach bedienbar und ubersichtlich sein, andererseits m ¨ | ussen auch die Rohdaten der Sensoren ¨
korrekt empfangen und verarbeitet werden. Das Erste lässt sich durch simples ”durchklicken”der Menus erledigen. ¨

Um die ankommenden Daten zu verifizieren mussen die Debugausgaben des versendenden ¨ Raspberry Picos (siehe 4.1) als auch die des empfangenen und anzeigenden Raspberry Picos uberwacht und abgeglichen werden. Da der UI-Pico durch das Anzeigen der GUI ziemlich stark ¨ ausgelastet ist, kommt die Raspberry Pi Debug Probe zum Einsatz, welche einen seriellen Port
(SerialWireDebug) uber das CMSIS-DAP Protokoll ¨ | öffnen kann, und die CPU des Picos nicht
zusätzlich belastet.


Abbildung 9: Raspberry Pico Debug Probe Bildquelle: berrybase.de (https://www.berrybase.de/media/image/c2/87/07/ID_207742_orig_1280x1280.jpg)

Nun kann im laufenden Betrieb oder mit einem Testprogramm validiert werden, dass die Daten korrekt ubertragen und verarbeitet werden. ¨

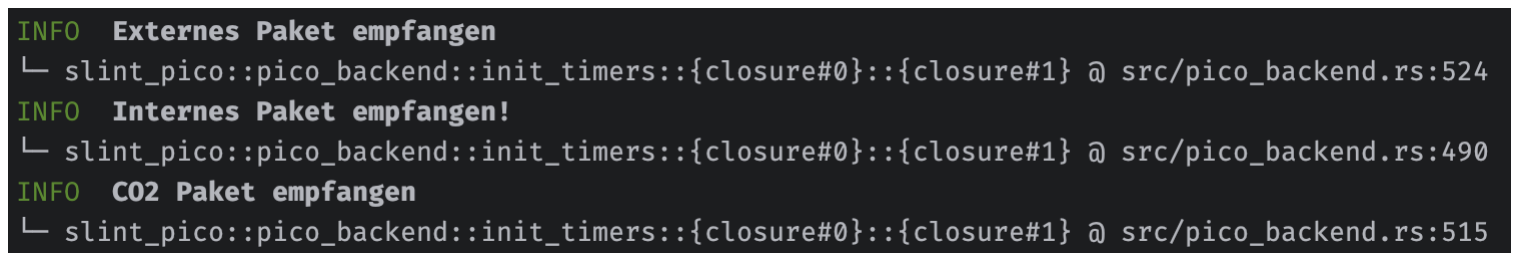
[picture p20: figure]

Abbildung 10: Funktionstest fur BME280-Sensoren und CO2-Sensor ¨

## 5 Fazit

Zum Ende des Projekts ist eine vollständige Wetterstation mit funktionierendem Außenmodul
entwickelt und funktionstuchtig. Mit geeigneten Geh ¨ | äusen sind beide Module theoretisch fur ¨
den Langzeitgebrauch geeignet und in einer realen Umgebung einsetzbar. Das Projekt kann damit als Erfolg gewertet werden, weil die zu Beginn aufgestellten Anforderungen erfullt wurden. ¨ Im Entwicklungsprozess hat sich insbesondere gezeigt, dass das DCF Signal sehr anfällig fur ¨ Störungen ist und auf die korrekte Ausrichtung der Antenne und einen geeigneten Aufstellort geachtet werden muss (Antenne sollte in waagerechter Position sein und quer in Richtung Frankfurt a.M. ausgerichtet werden). Damit erklärt sich auch, warum herkömmliche Funkuhren häufig kein Signal in Innenräumen empfangen.

Sollte das Projekt weiterverfolgt werden, kann im nächsten Iterationsschritt ein effizienterer Mikrocontroller in das Außenmodul eingesetzt werden (MSP430 o.ä.) und weitestgehend auf Shields verzichtet werden, um die Abmessungen der Platinen zu reduzieren. Damit ließe sich die Professionalität weiter steigern.

## A Ablaufdiagramm externes Modul

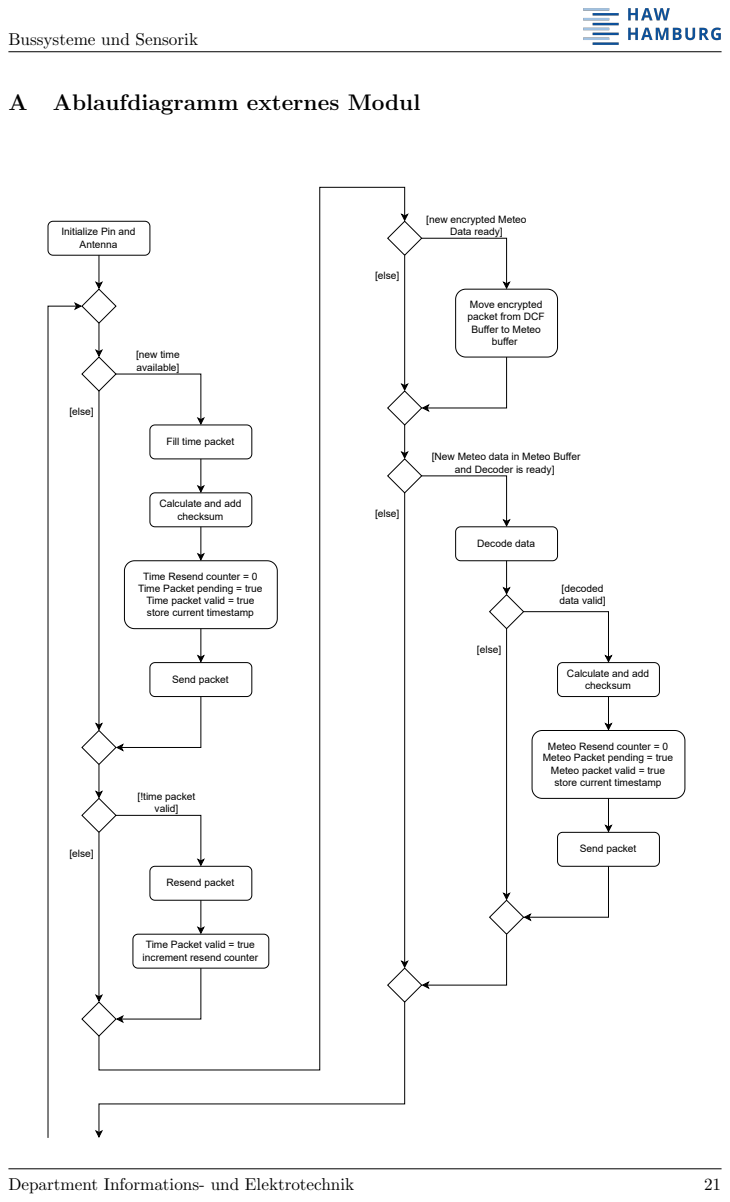
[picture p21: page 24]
[new time available]; [else]; Send packet; Resend packet; [!time packet valid]; Decode data; [decoded data valid]

[new encrypted Meteo
Data ready]

Initialize Pin and
Antenna

Move encrypted
packet from DCF
Buffer to Meteo
buffer

Fill time packet

[New Meteo data in Meteo Buffer
and Decoder is ready]

Calculate and add
checksum

Time Resend counter = 0
Time Packet pending = true
Time packet valid = true
store current timestamp

Meteo Resend counter = 0
Meteo Packet pending = true
Meteo packet valid = true

Time Packet valid = true
increment resend counter

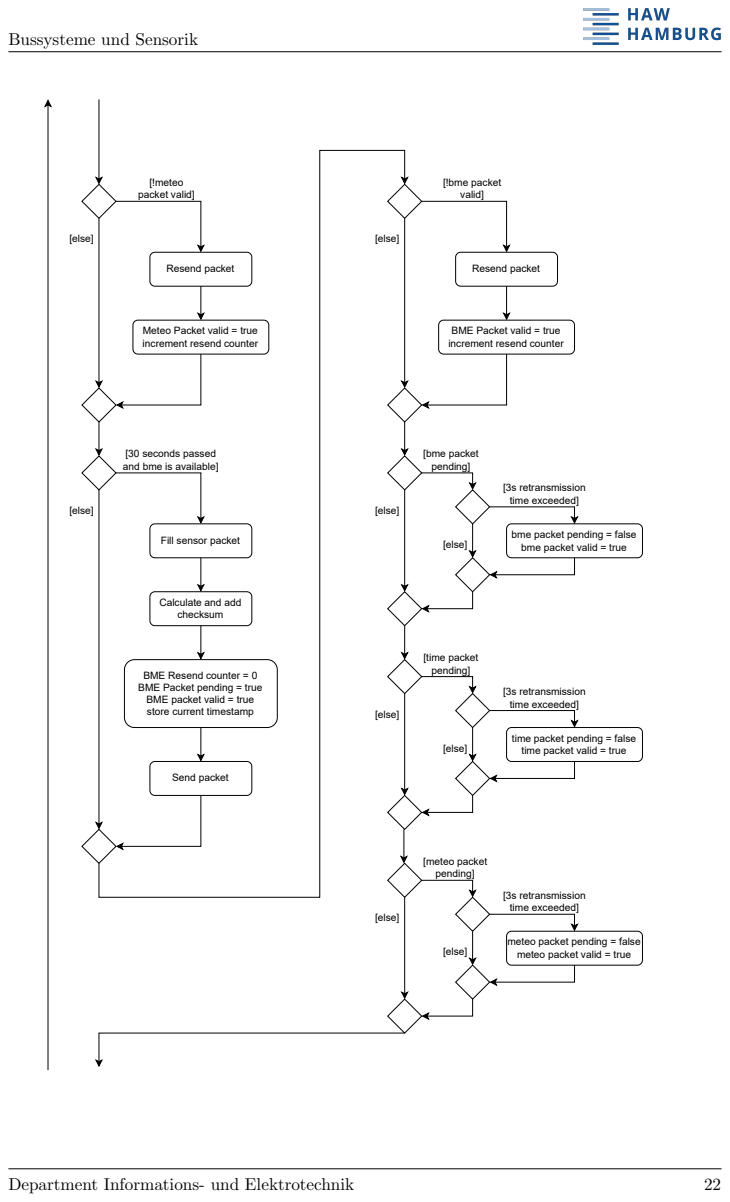
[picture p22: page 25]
Resend packet; [!meteo packet valid]; [else]; Send packet; [!bme packet valid]; [bme packet pending]; [3s retransmission time exceeded]; [time packet pending]; [meteo packet pending]

Meteo Packet valid = true
increment resend counter

BME Packet valid = true

[30 seconds passed
and bme is available]

Fill sensor packet

bme packet pending = false
bme packet valid = true

Calculate and add
checksum

BME Resend counter = 0
BME Packet pending = true
BME packet valid = true
store current timestamp

time packet pending = false
time packet valid = true

meteo packet pending = false
meteo packet valid = true

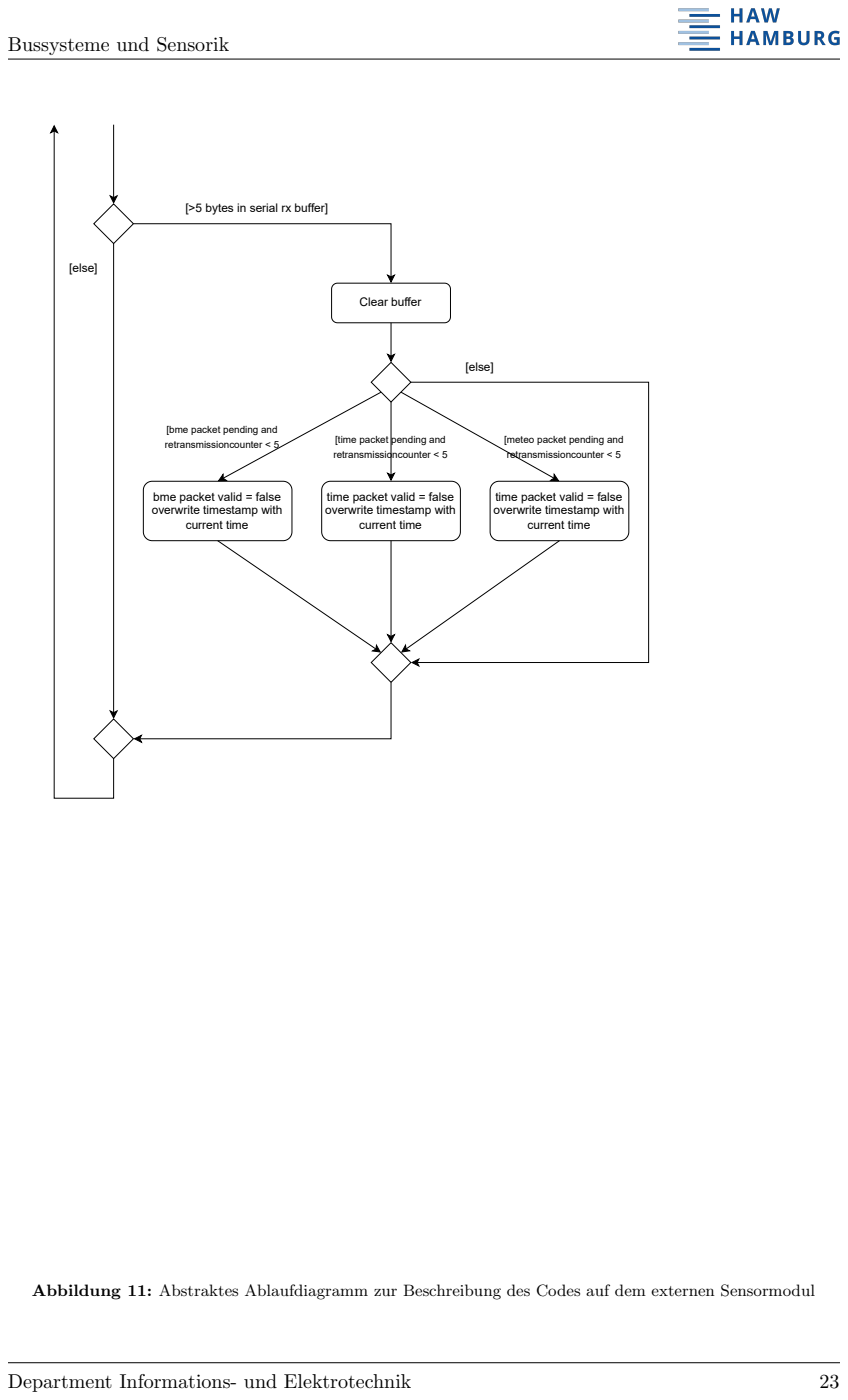
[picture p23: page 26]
Clear buffer; retransmissioncounter < 5; [time packet pending and; [else]

[>5 bytes in serial rx buffer]

[bme packet pending and

[meteo packet pending and
retransmissioncounter < 5

bme packet valid = false
overwrite timestamp with
current time

time packet valid = false

Abbildung 11: Abstraktes Ablaufdiagramm zur Beschreibung des Codes auf dem externen Sensormodul

## B Schaltplan externes Modul

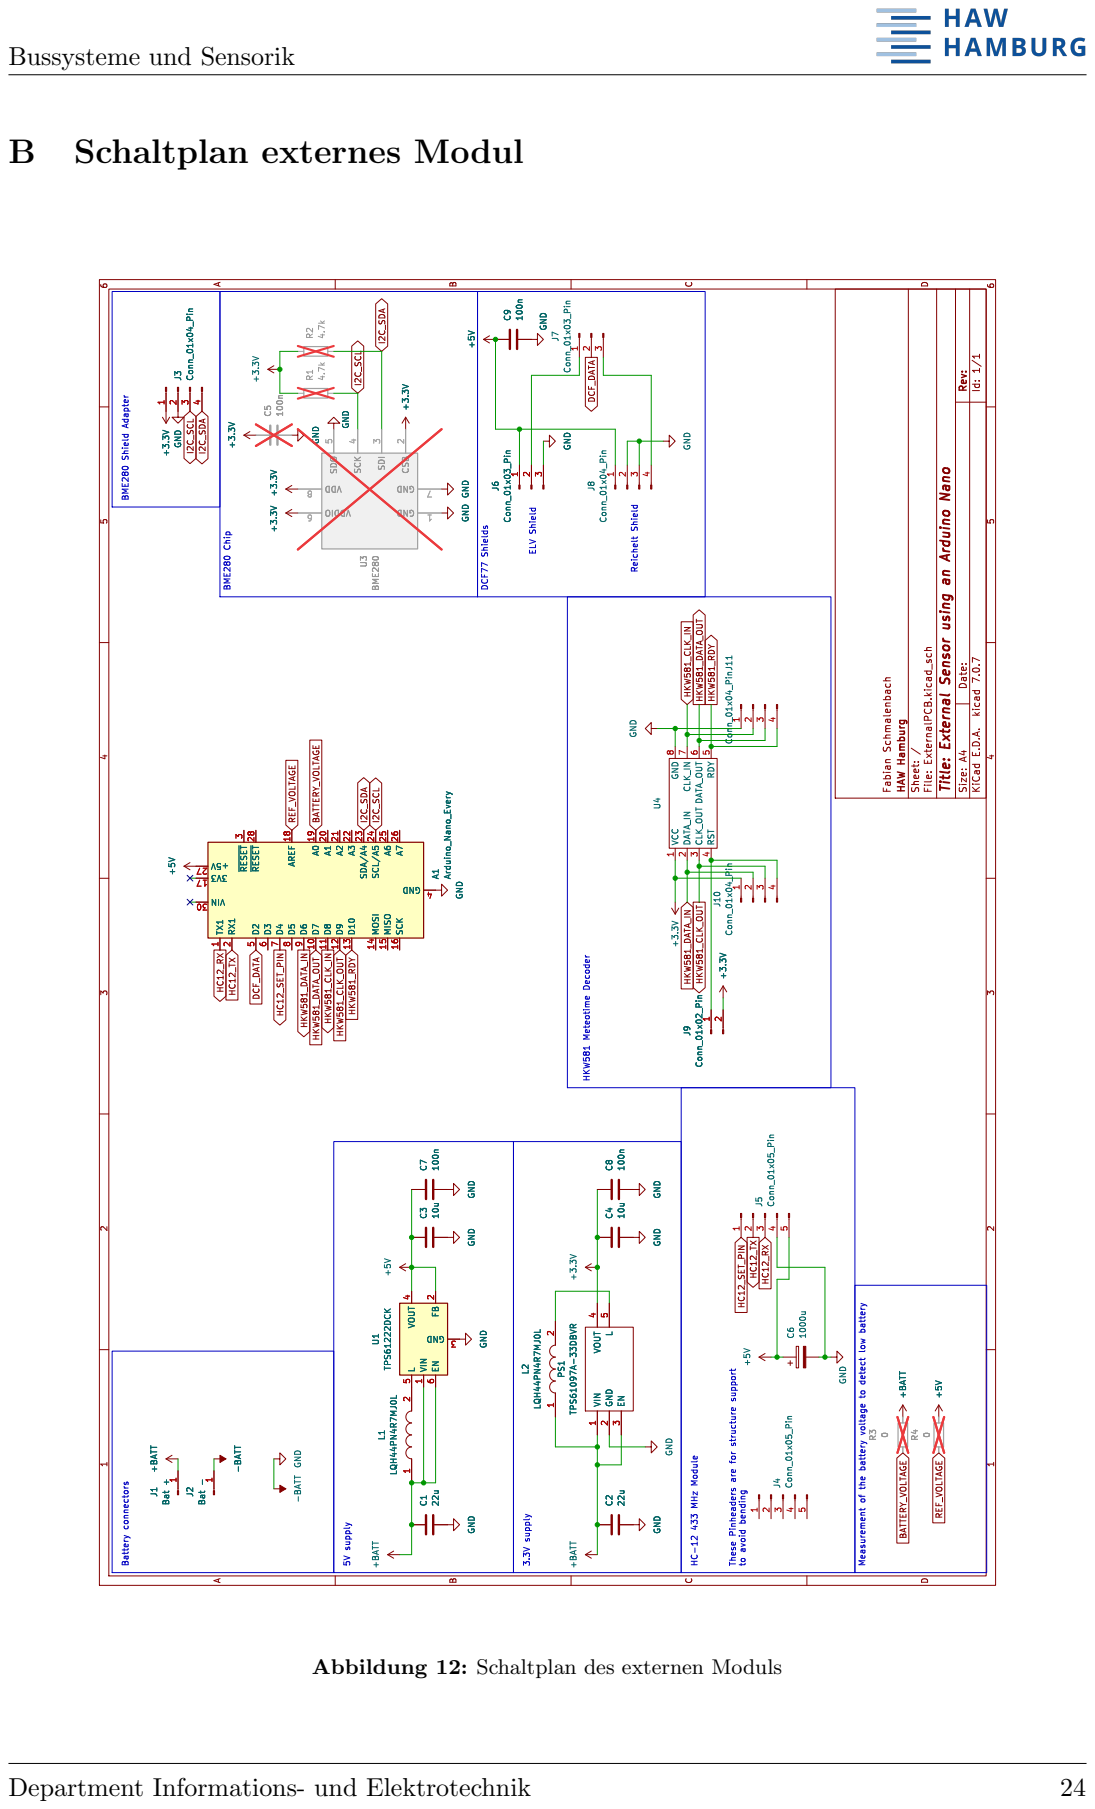
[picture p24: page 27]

D Date: KiCad E.D.A. kicad 7.0.7 Rev: Size: A4

Id: 1/1 Title: External Sensor using an Arduino Nano

5V supply ELV Shield Reichelt Shield DCF77 Shields BME280 Shield Adapter BME280 Chip

File: ExternalPCB.kicad_sch Sheet: / HAW Hamburg

VCC 1 DATA_IN 2 CLK_OUT 3 RST 4 RDY 5 DATA_OUT 6 CLK_IN 7 GND 8 U4 GND

A1Arduino_Nano_Every TX1 1 D7 10 D8 11 D9 12 D10 13 MOSI 14 MISO 15 SCK 16 3V3 17 AREF 18 A0 19 RX1 2 A1 20 A2 21 A3 22 SDA/A4 23 SCL/A5 24 A6 25 A7 26 +5V 27

TX1 1 D7 10 D8 11 D9 12 D10 13 MOSI 14 MISO 15 SCK 16 3V3 17 AREF 18 A0 19 RX1 2 A1 20 A2 21 A3 22 SDA/A4 23 SCL/A5 24 A6 25 A7 26 +5V 27

~{RESET} 28 ~{RESET}3 VIN 30 GND

3.3V supply Measurement of the battery voltage to detect low battery HKW581 Meteotime Decoder HC-12 433 MHz Module These Pinheaders are for structure support

-BATT VIN 1 GND 2 EN 3 VOUT 4

VIN 1 GND 2 EN 3 VOUT 4

Abbildung 12: Schaltplan des externen Moduls

## C Platine externes Modul

2D Ansicht

Abbildung 13: 2D Ansicht des Platinenentwurfs

C.2 3D Ansicht


Abbildung 14: 3D Ansicht des Platinenentwurfs

## D Ablaufdiagramm internes Sensormodul

Core 0; packet; Invalid message. Dump data.; [else]; [Packetheader is EBME]; [Packetheader is TIME]; [Packetheader is MTEO]

Initialize Pins and
Antenna

[data available in
UART rx buffer]

Read four bytes from
buffer that identify the

Set number of bytes
to be read to size of
bme packet

time packet

meteo packet

Read until packet is
full or timeout
occured

Add checksum; Send packet to graphic module; Initiate retransmission; [checksum == 0] [else]; [Packetheader is EBME]; [Packetheader is MTEO]; [Packetheader is TIME]; Send BME Data; Send CO2 data; [else]

Copy data to send
buffer

[30s elapsed and
bme is available]

[30s elapsed and CO2
sensor is ready]

Abbildung 15: Abstraktes Ablaufdiagramm zur Beschreibung des Codes auf dem internen Sensormodul (Core 0)


Abbildung 16: Abstraktes Ablaufdiagramm zur Beschreibung des Codes auf dem internen Sensormodul (Core 1)

## E Schaltplan internes Modul


F Date: 2024-01-05 KiCad E.D.A. kicad 7.0.7 Rev: Size: A3

Id: 1/1 Title: Schaltplan internes Sensormodul File: InternalPCB.kicad_sch Sheet: / HAW Hamburg

J2Conn_01x20 VCC 1 DATA_IN 2 CLK_OUT 3 RST 4 RDY 5 DATA_OUT 6 CLK_IN 7 GND 8 U4

3V3_EN 37 GND 38 VSYS 39 GPIO2 4 VBUS 40 SWCLK 41 GND 42 SWDIO 43 GPIO3 5 GPIO4 6 GPIO5 7 GND 8 GPIO6 9 U2 Pico +5V GND G+

PICO_RESET HKW581_DOUT Power connector These Pinheaders are for structure support

HKW581 Meteotime Decoder Display control MH-Z19C CO2 Sensor

+5V Raspberry Pi Pico GPIO0 1 GPIO7 10 GPIO8 11 GPIO9 12 GND 13 GPIO10 14 GPIO11 15 GPIO12 16 GPIO13 17 GND 18 GPIO14 19 GPIO1 2 GPIO15 20 GPIO16 21 GPIO17 22 GND 23 GPIO18 24 GPIO19 25 GPIO20 26 GPIO21 27 GND 28 GPIO22 29 GND 3 RUN 30 GPIO26_ADC0 31 GPIO27_ADC1 32 AGND 33 GPIO28_ADC2 34 ADC_VREF 35

Sensor control BME280 Shield Adapter HC-12 433 MHz Module Reset button for both Pis

Raspberry Pi Pico GPIO0 1 GPIO7 10 GPIO8 11 GPIO9 12 GND 13 GPIO10 14 GPIO11 15 GPIO12 16 GPIO13 17 GND 18 GPIO14 19 GPIO1 2 GPIO15 20 GPIO16 21 GPIO17 22 GND 23 GPIO18 24 GPIO19 25 GPIO20 26 GPIO21 27 GND 28 GPIO22 29 GND 3 RUN 30 GPIO26_ADC0 31 GPIO27_ADC1 32 AGND 33 GPIO28_ADC2 34 ADC_VREF 35

3V3_EN 37 GND 38 VSYS 39 GPIO2 4 VBUS 40 SWCLK 41 GND 42 SWDIO 43 GPIO3 5 GPIO4 6 GPIO5 7 GND 8 GPIO6 9 U1 Pico W

Abbildung 17: Schaltplan des internen Moduls

## F Platine internes Modul

2D Ansicht

Abbildung 18: 2D Ansicht des Platinenentwurfs

F.2 3D Ansicht


Abbildung 19: 3D Ansicht des Platinenentwurfs

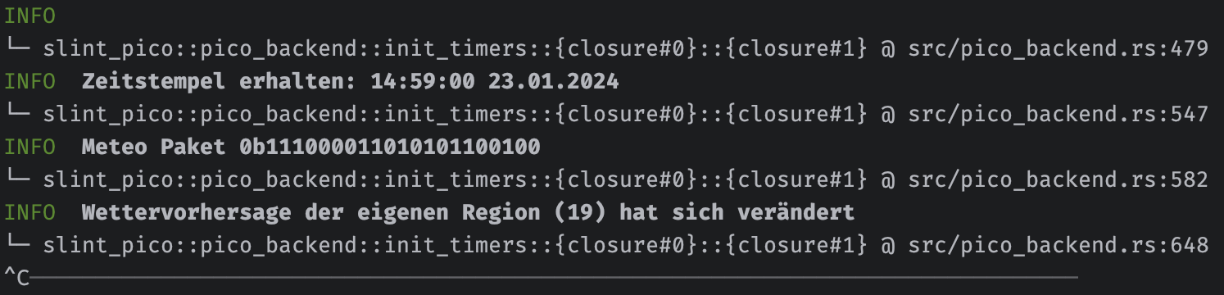
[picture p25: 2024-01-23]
LaTeX/FunktionstestGUI-DCF-METEO.png

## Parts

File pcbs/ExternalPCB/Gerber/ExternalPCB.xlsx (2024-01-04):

Comment | Designator | Footprint
22u | C1, C2 | Capacitor_SMD:C_0805_2012Metric
10u | C3, C4 | Capacitor_SMD:C_0805_2012Metric
100n | C7, C8, C9 | Capacitor_SMD:C_0805_2012Metric
LQH44PN4R7MJ0L | L1, L2 | LQH44PN4R7MJ0L:LQH44PN100MJ0L
TPS61097A-33DBVR | PS1 | TPS61097A:SOT95P280X145-5N
TPS61222DCK | U1 | Package_TO_SOT_SMD:Texas_R-PDSO-G6

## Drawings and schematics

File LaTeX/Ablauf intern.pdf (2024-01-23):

### Core 0

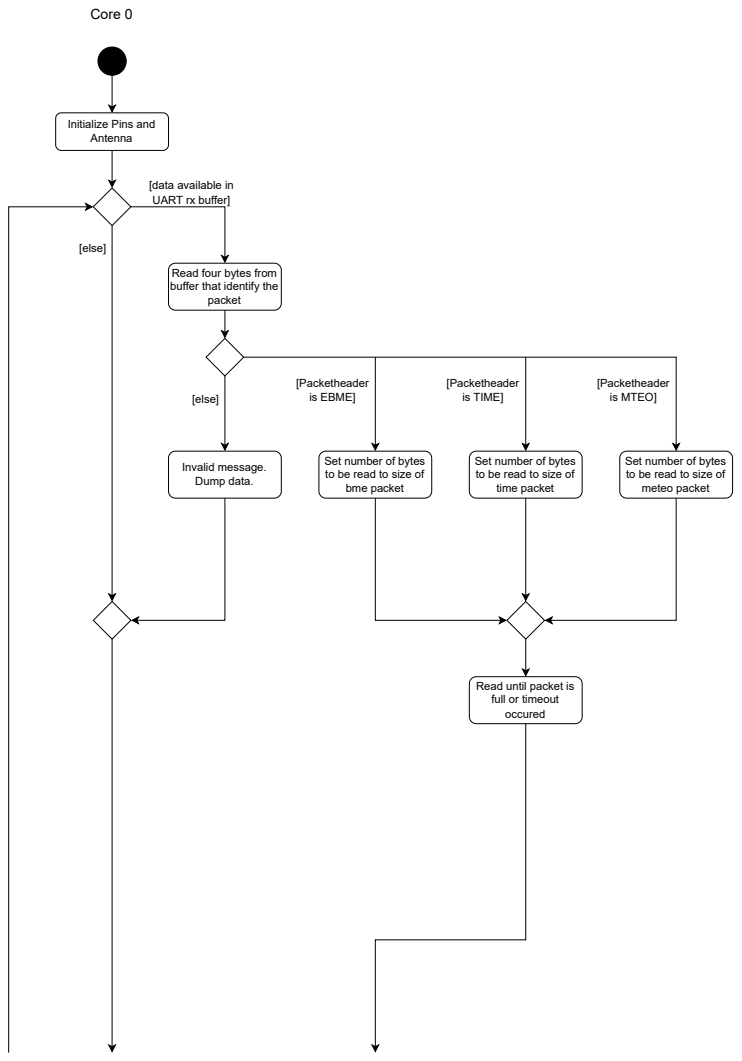
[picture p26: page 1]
packet; Invalid message. Dump data.; [else]; [Packetheader is EBME]; [Packetheader is TIME]; [Packetheader is MTEO]

Initialize Pins and
Antenna

[data available in
UART rx buffer]

Read four bytes from
buffer that identify the

Set number of bytes
to be read to size of
bme packet

time packet

meteo packet

Read until packet is
full or timeout
occured

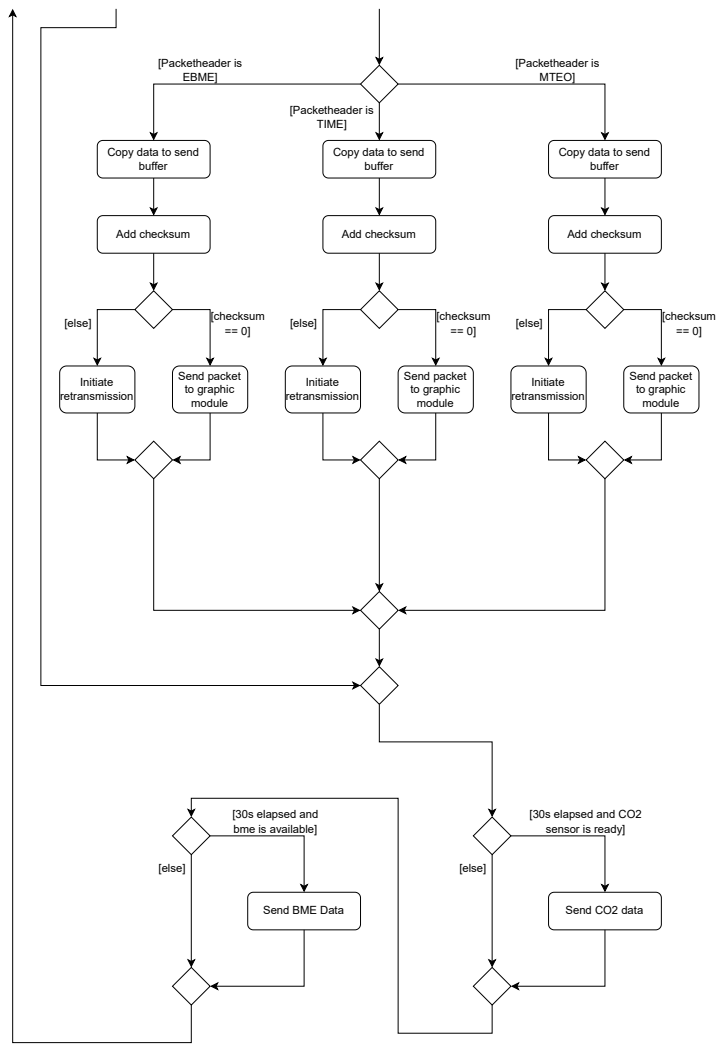
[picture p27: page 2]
Add checksum; Send packet to graphic module; Initiate retransmission; [checksum == 0] [else]; [Packetheader is MTEO]; [Packetheader is; Send BME Data; Send CO2 data; [else]

[Packetheader is EBME]

TIME]

Copy data to send
buffer

[30s elapsed and
bme is available]

[30s elapsed and CO2
sensor is ready]

### Core1

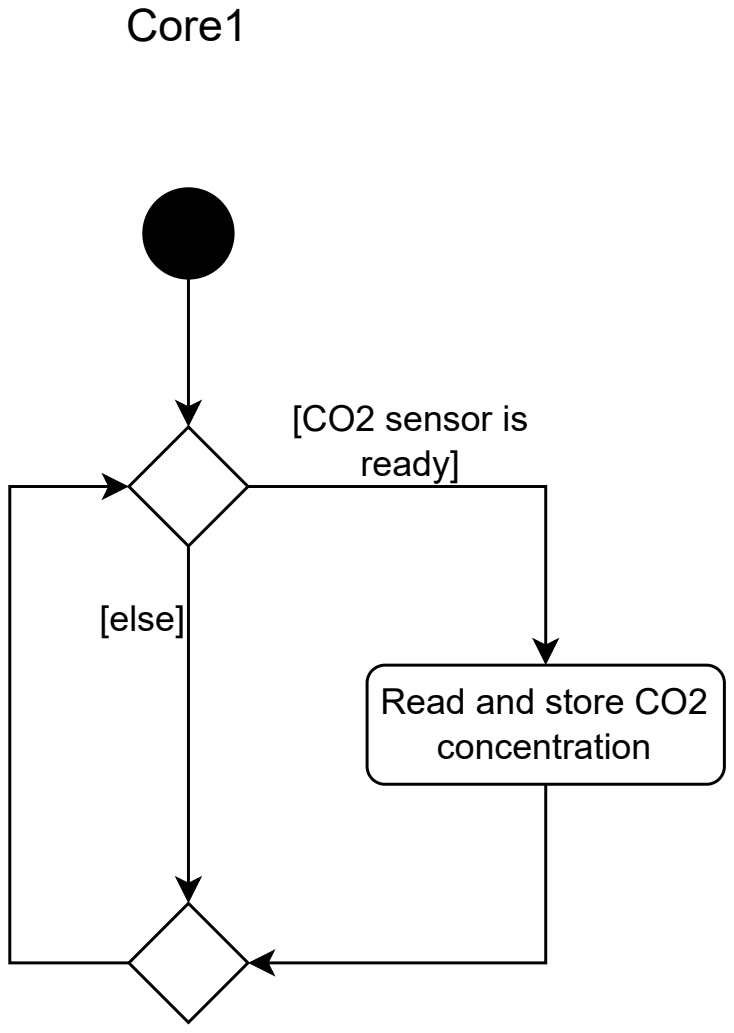
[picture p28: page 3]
[CO2 sensor is ready]; [else]

Read and store CO2
concentration

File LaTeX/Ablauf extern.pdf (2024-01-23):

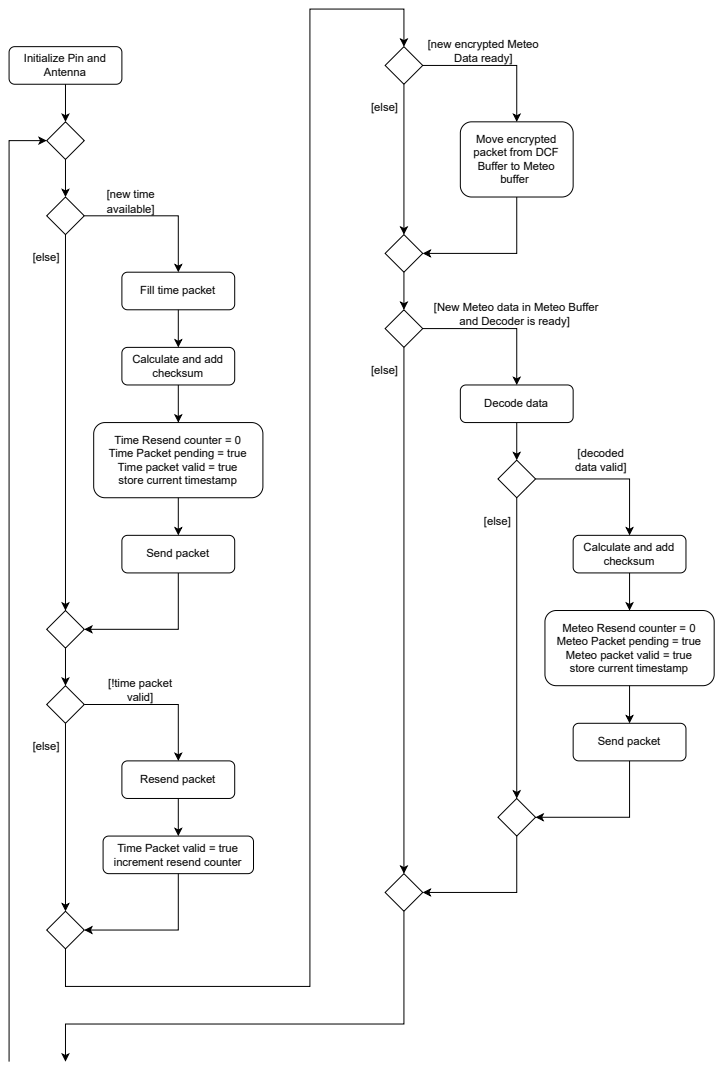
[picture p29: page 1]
[new time available]; [else]; Send packet; Resend packet; [!time packet valid]; Decode data; [decoded data valid]

[new encrypted Meteo
Data ready]

Initialize Pin and
Antenna

Move encrypted
packet from DCF
Buffer to Meteo
buffer

Fill time packet

[New Meteo data in Meteo Buffer
and Decoder is ready]

Calculate and add
checksum

Time Resend counter = 0
Time Packet pending = true
Time packet valid = true
store current timestamp

Meteo Resend counter = 0
Meteo Packet pending = true
Meteo packet valid = true

Time Packet valid = true
increment resend counter

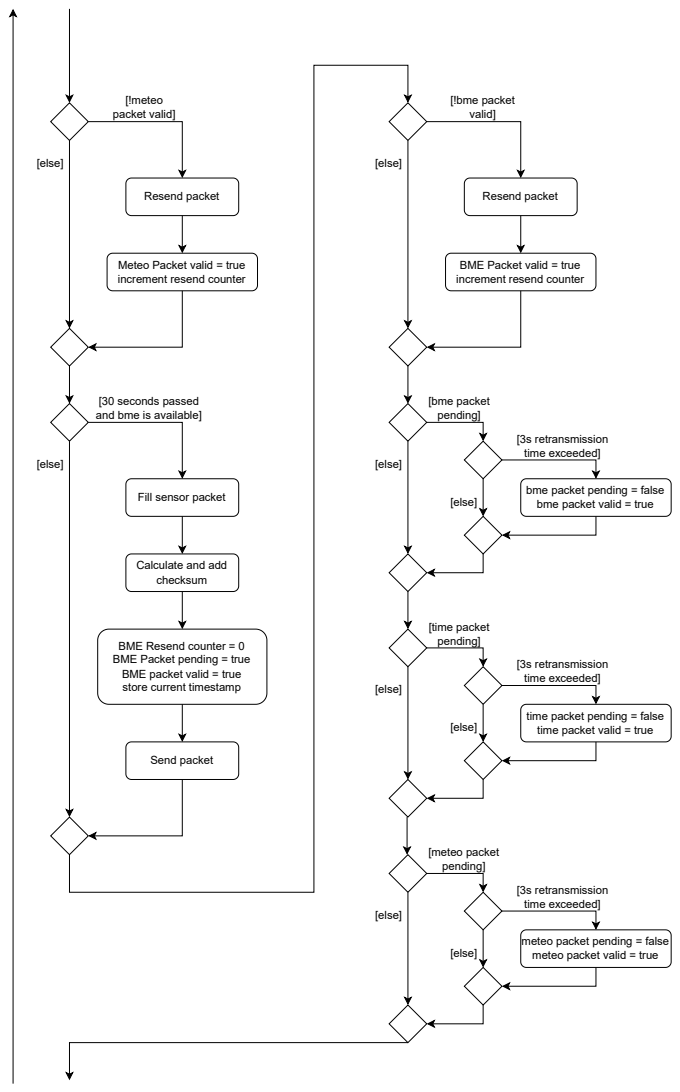
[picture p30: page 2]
Resend packet; [!meteo packet valid]; [else]; Send packet; [!bme packet valid]; [bme packet pending]; [3s retransmission time exceeded]; [time packet pending]; [meteo packet pending]

Meteo Packet valid = true
increment resend counter

BME Packet valid = true

[30 seconds passed
and bme is available]

bme packet pending = false
bme packet valid = true

Fill sensor packet

Calculate and add
checksum

BME Resend counter = 0
BME Packet pending = true
BME packet valid = true
store current timestamp

time packet pending = false
time packet valid = true

meteo packet pending = false
meteo packet valid = true

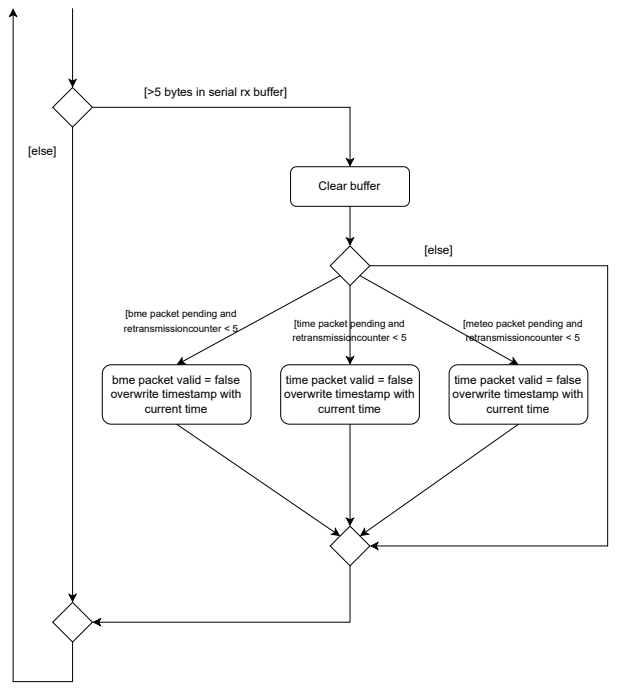
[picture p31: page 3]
Clear buffer; retransmissioncounter < 5; [time packet pending and; [else]

[>5 bytes in serial rx buffer]

[bme packet pending and

[meteo packet pending and
retransmissioncounter < 5

bme packet valid = false
overwrite timestamp with
current time

time packet valid = false

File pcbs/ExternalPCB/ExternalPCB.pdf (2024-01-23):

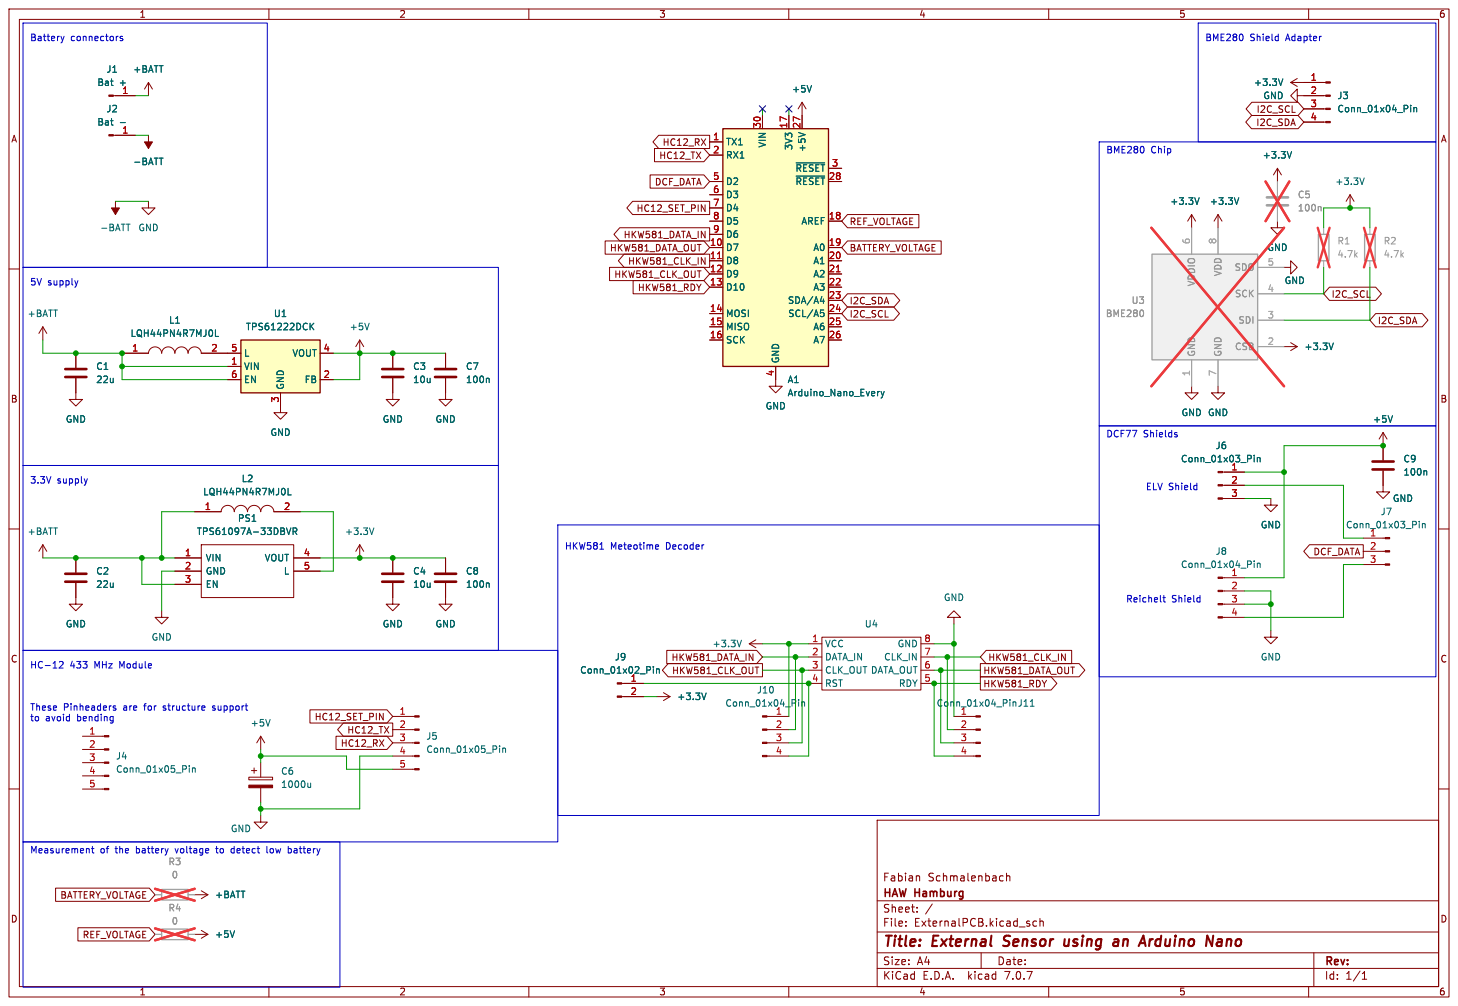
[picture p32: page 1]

1 CSB 2 SDI 3 SCK 4 SDO 5 VDDIO

Id: 1/1 Title: External Sensor using an Arduino Nano

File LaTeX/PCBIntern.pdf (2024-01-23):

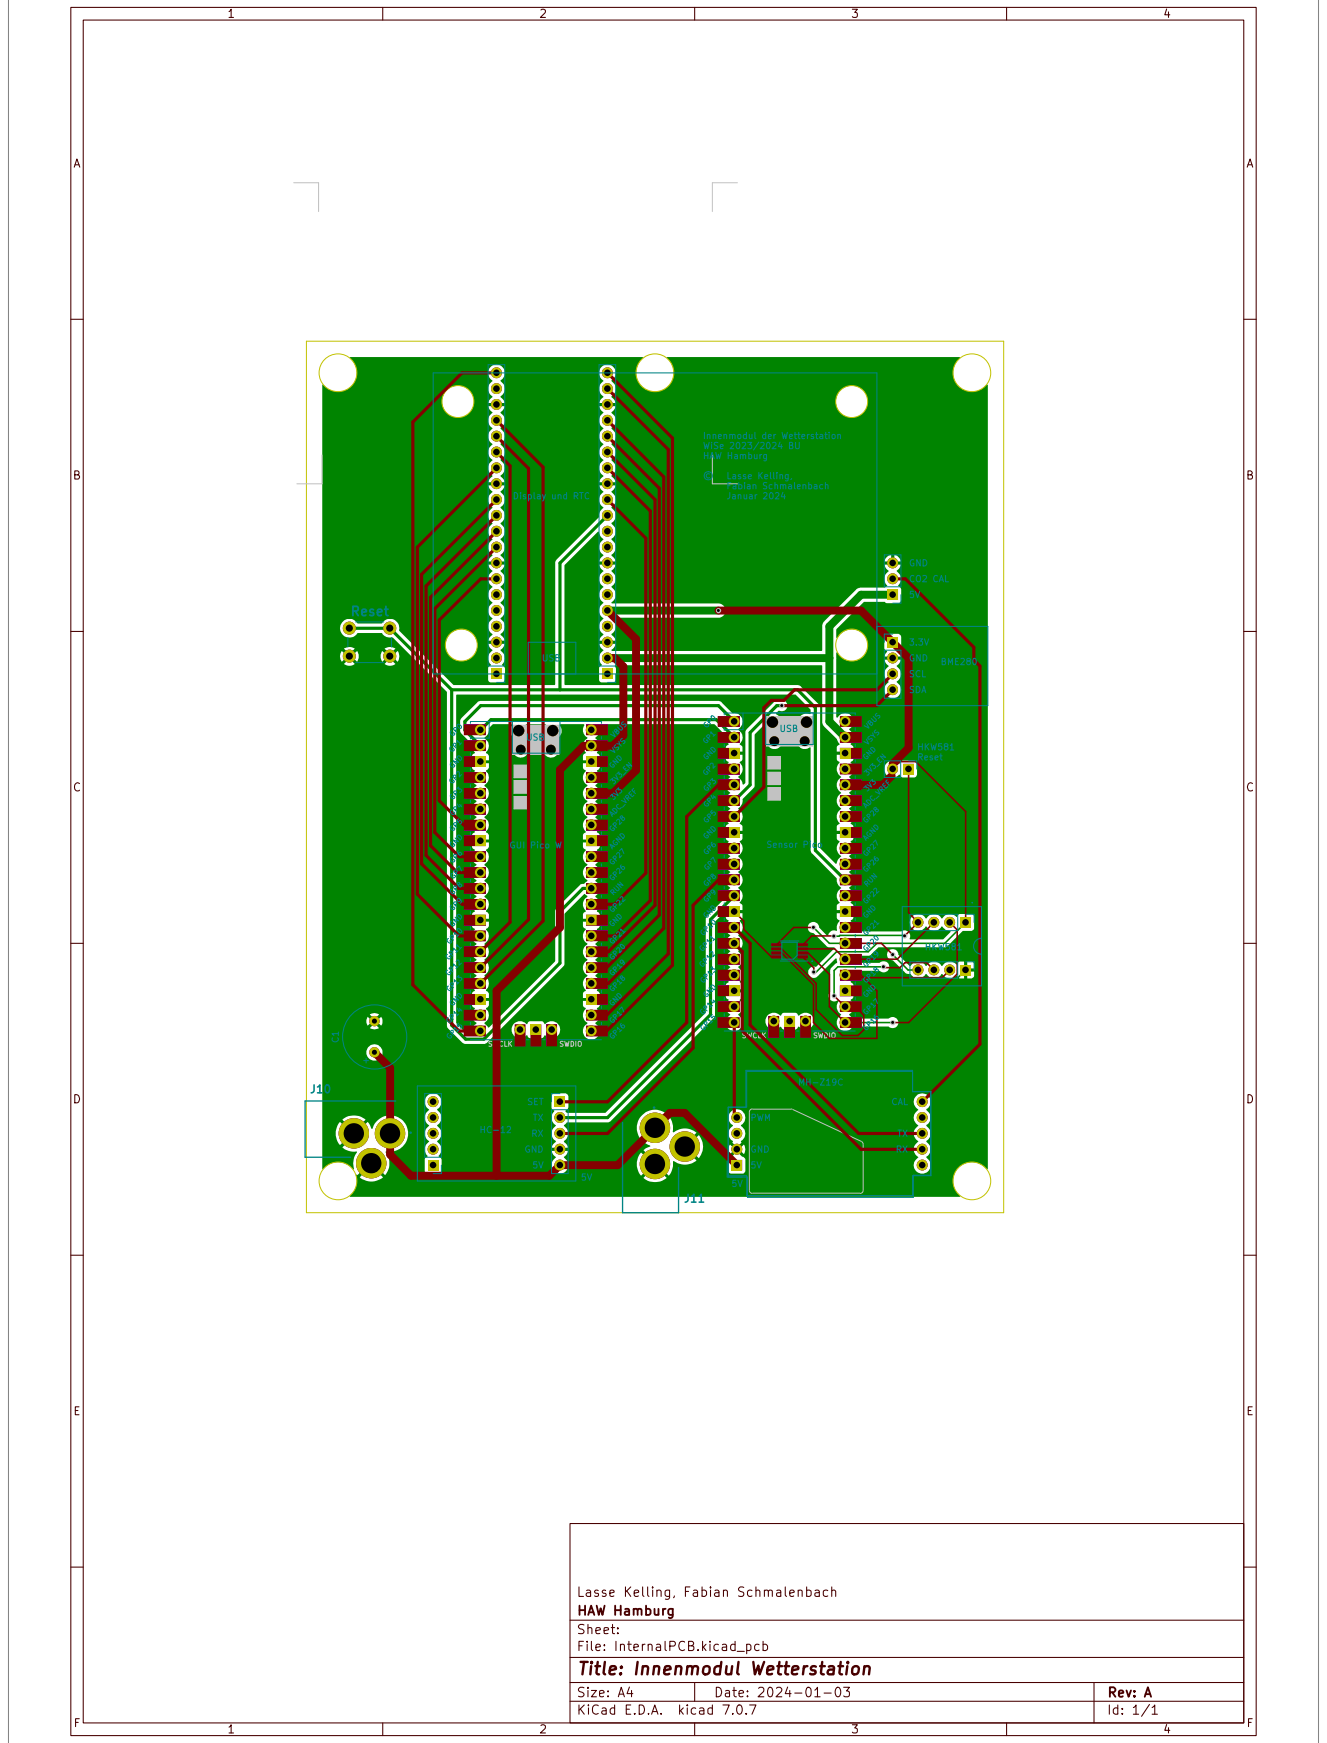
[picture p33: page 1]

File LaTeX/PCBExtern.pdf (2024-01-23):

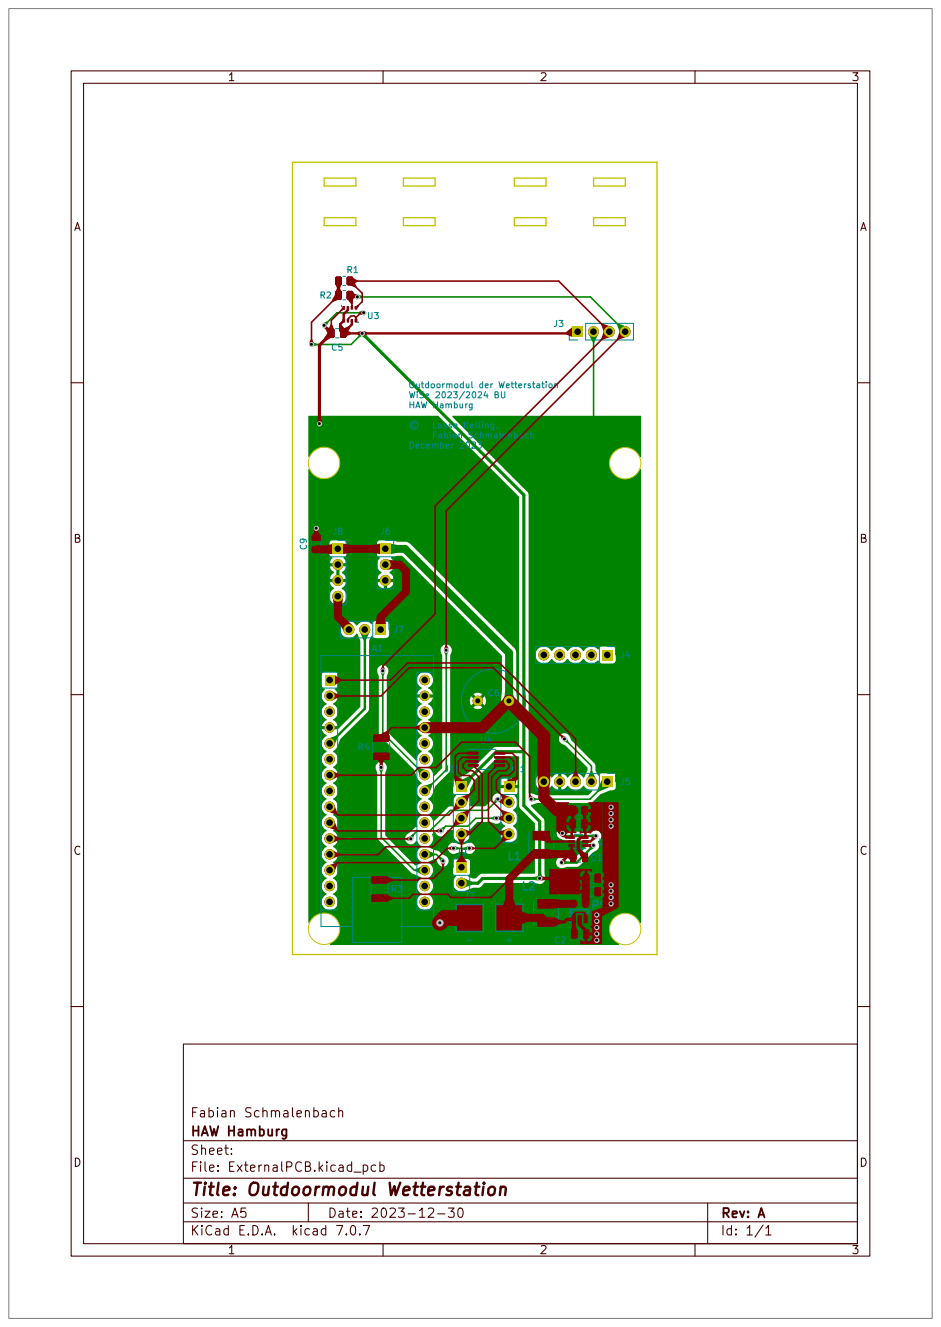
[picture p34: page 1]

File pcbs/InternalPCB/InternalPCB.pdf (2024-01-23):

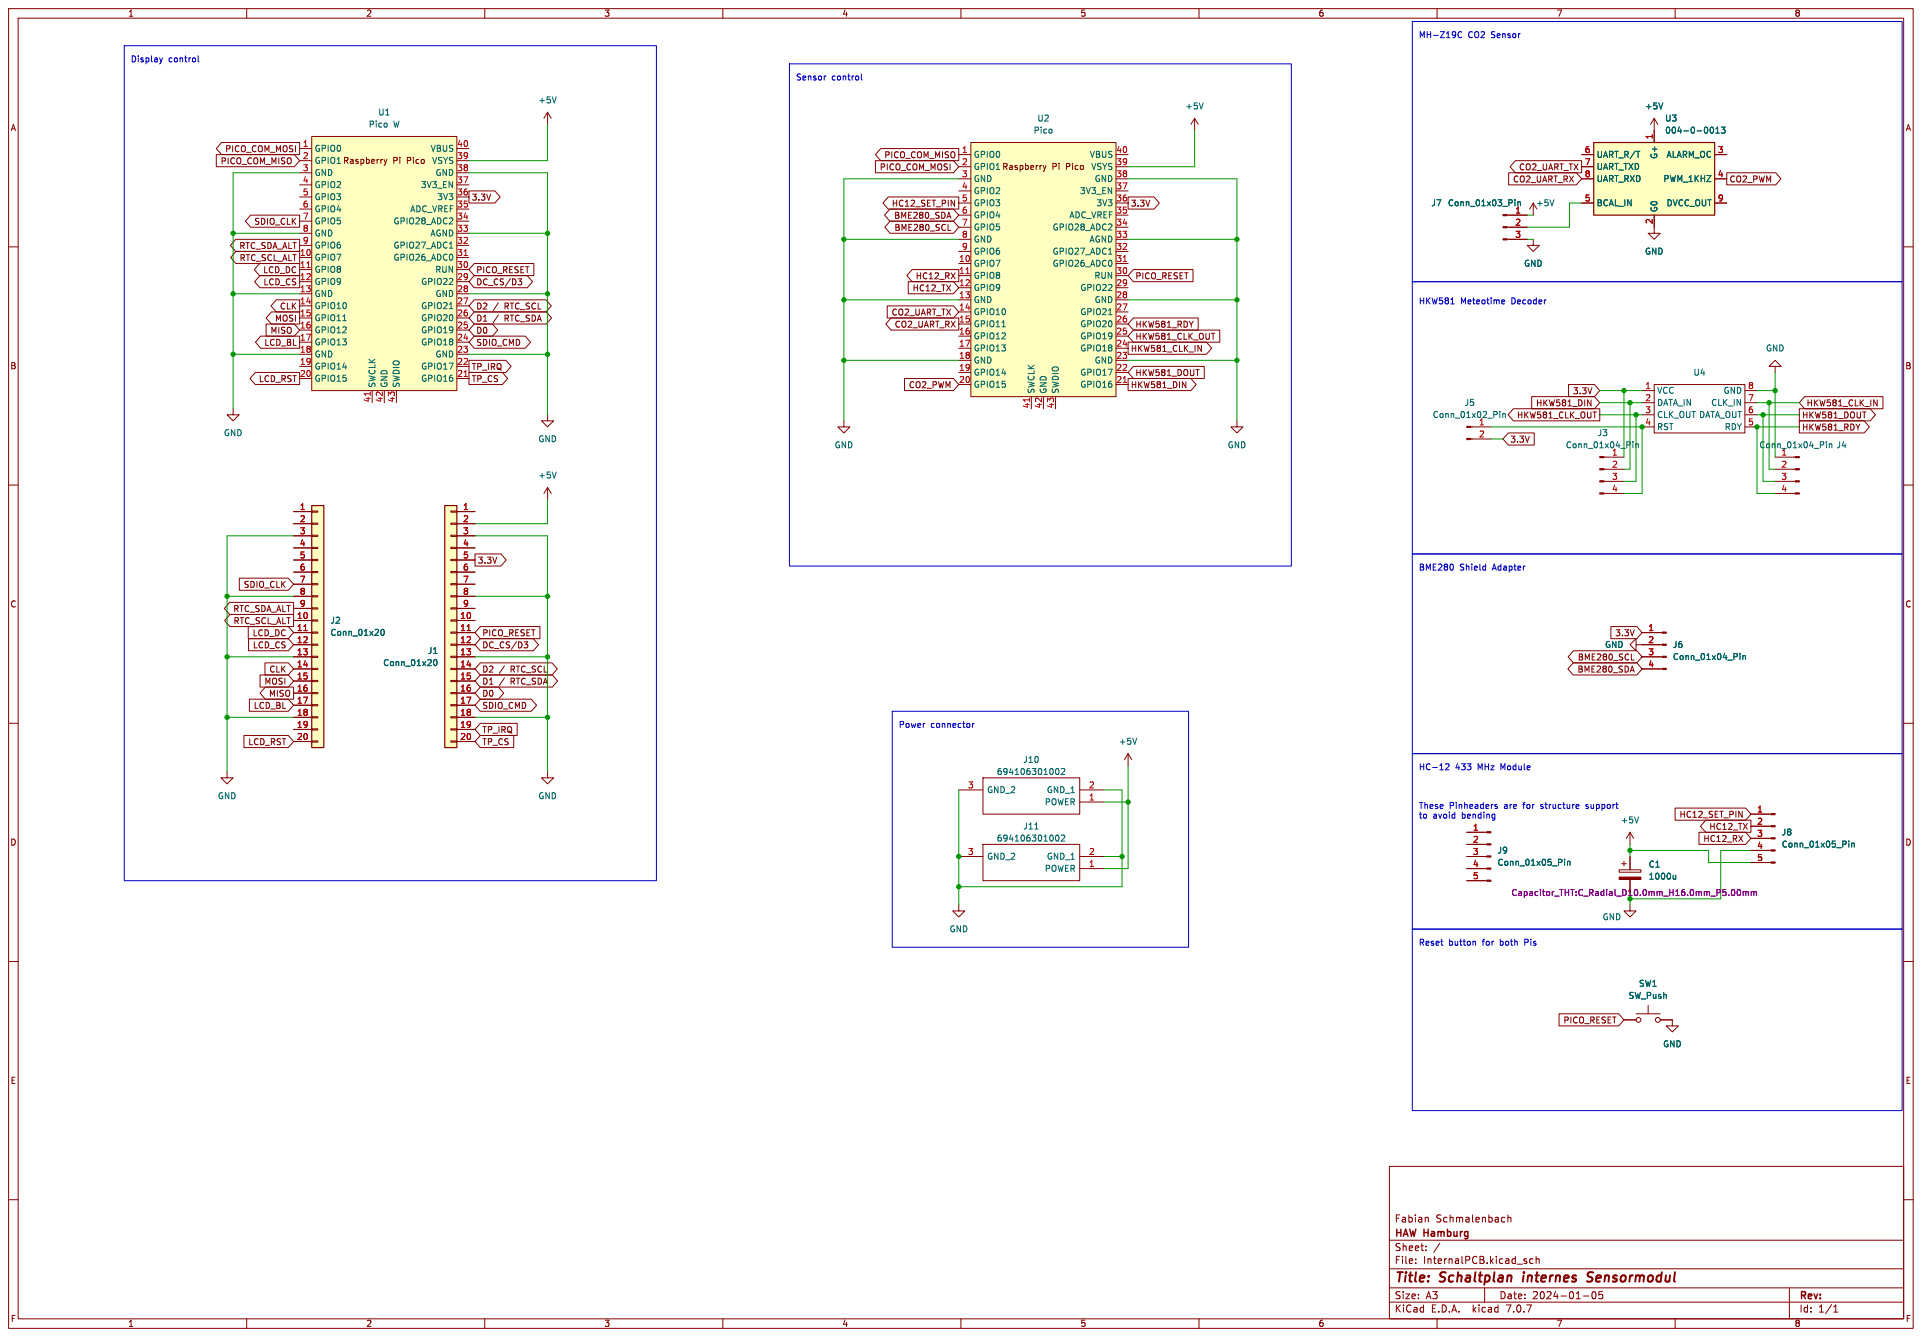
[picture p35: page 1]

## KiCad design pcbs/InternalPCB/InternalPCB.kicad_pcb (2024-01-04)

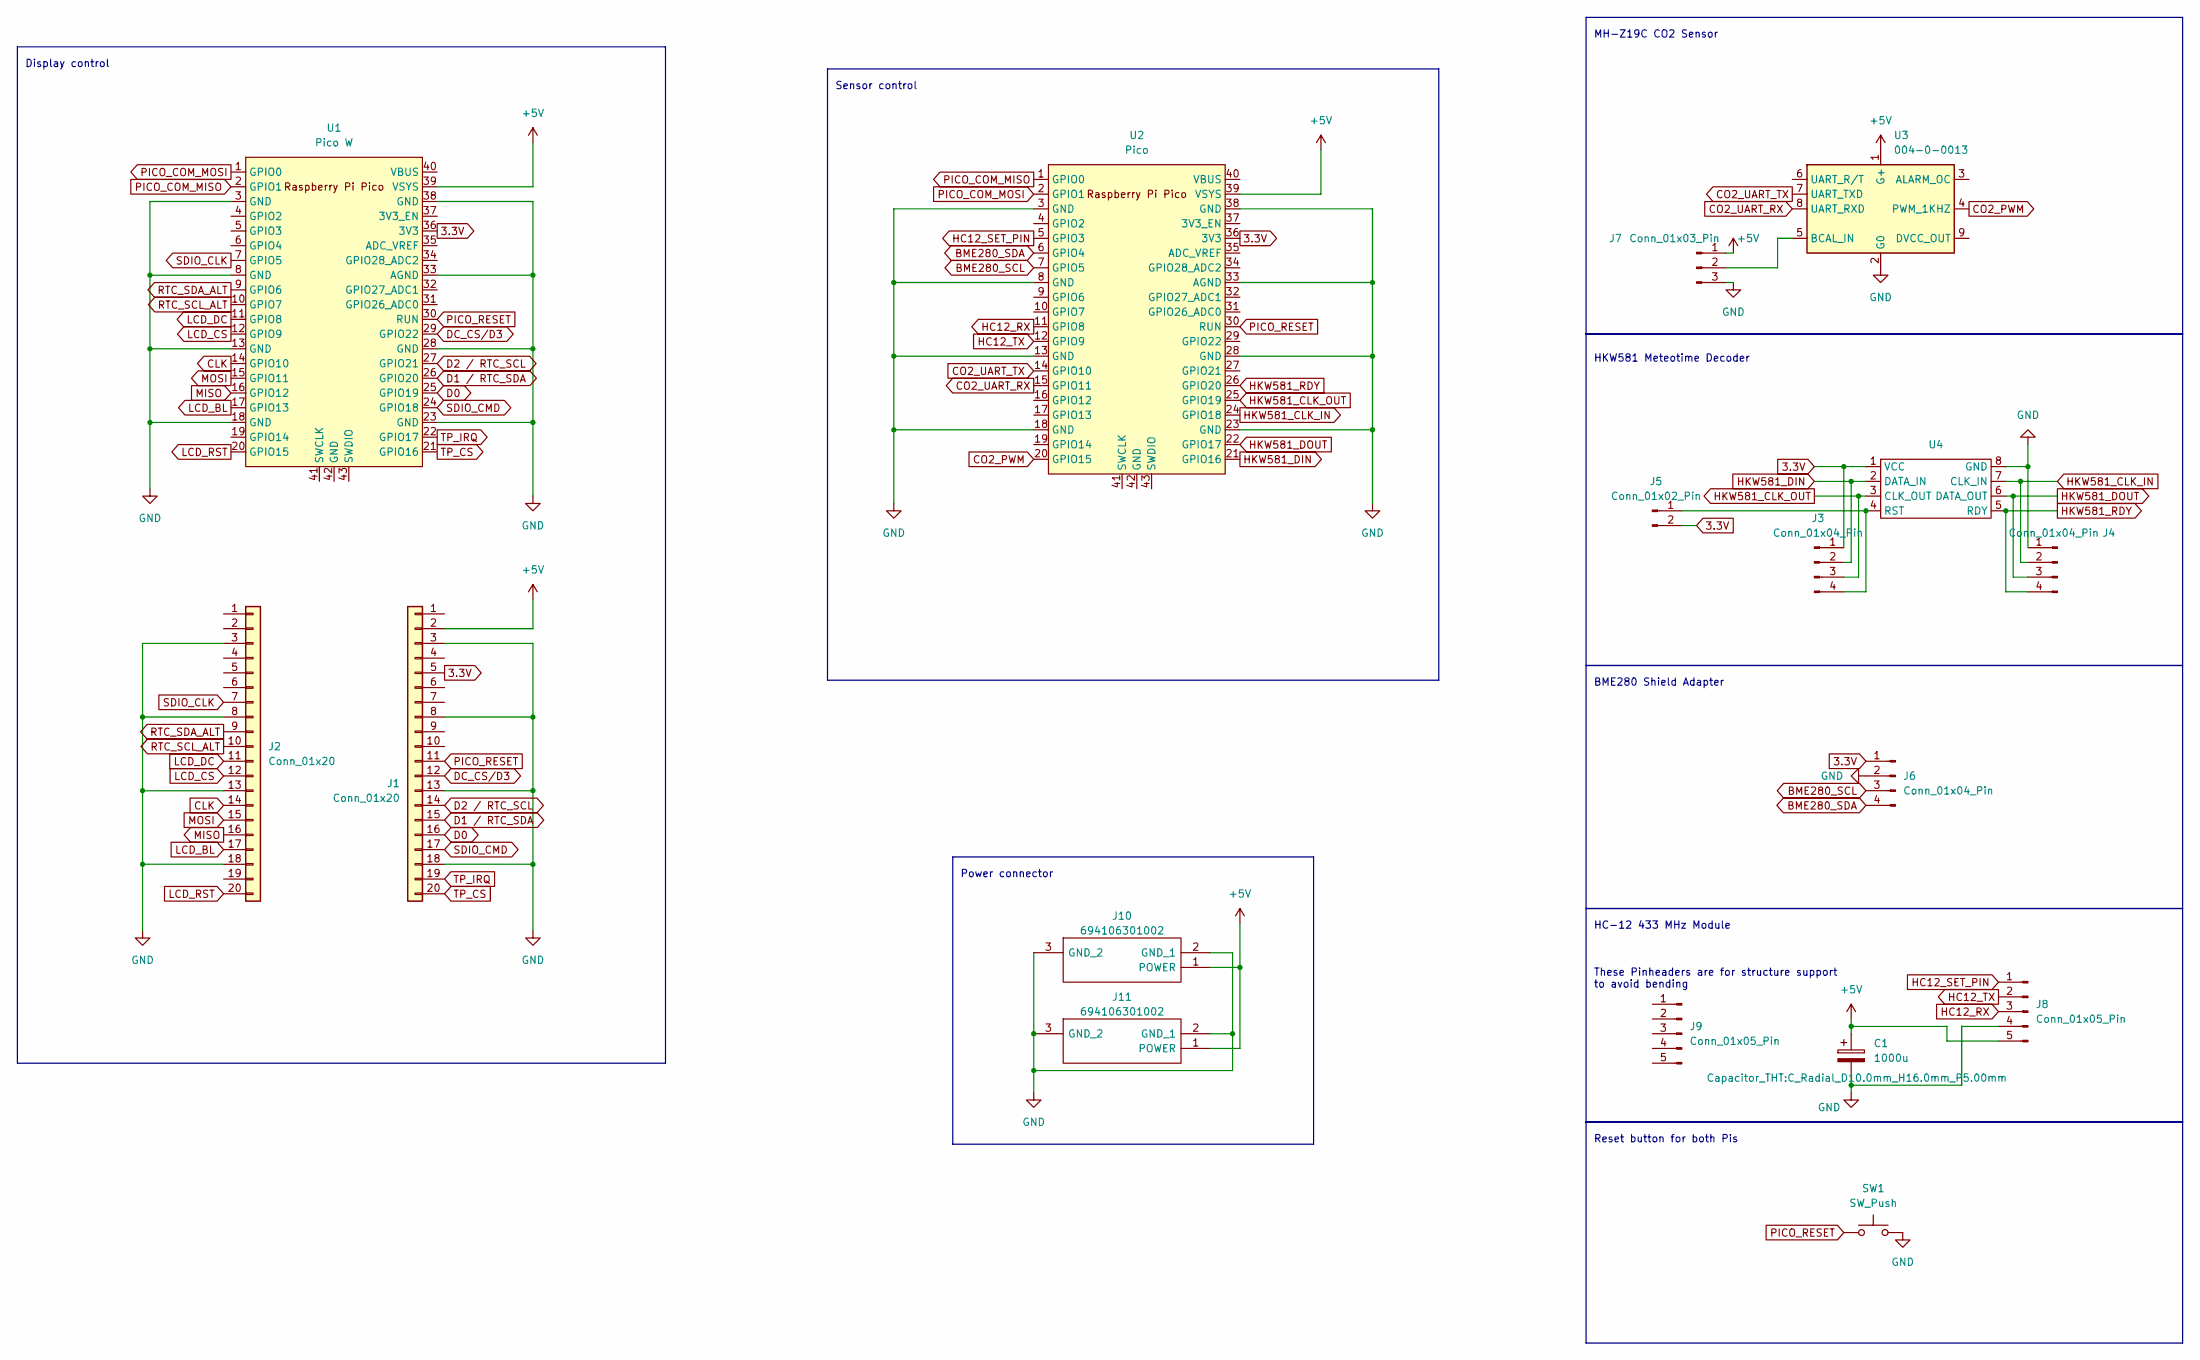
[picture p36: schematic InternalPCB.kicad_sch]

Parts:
C1: 1000u; C_Radial_D10.0mm_H16.0mm_P5.00mm
J1, J2: Conn_01x20; PinHeader_1x20_P2.54mm_Vertical
J3, J4, J6: Conn_01x04_Pin; PinHeader_1x04_P2.54mm_Vertical
J5: Conn_01x02_Pin; PinHeader_1x02_P2.54mm_Vertical
J7: Conn_01x03_Pin; PinHeader_1x03_P2.54mm_Vertical
J8, J9: Conn_01x05_Pin; PinHeader_1x05_P2.54mm_Vertical
J10, J11: 694106301002; 694106301002_1; Manufacturer_Part_Number 694106301002; Mouser Part Number 710-694106301002
SW1: SW_Push; SW_PUSH_6mm
U1: Pico W; RPi_Pico_SMD_TH
U2: Pico; RPi_Pico_SMD_TH
U3: 004-0-0013; Senseair_S8_Down
U4: MSOP-8_3x3mm_P0.65mm

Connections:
3.3V: J1.5, J3.1, J5.2, J6.1, U1.36 (3V3), U2.36 (3V3), U4.1 (VCC)
+5V: C1.1, J1.2, J7.1, J8.5, J10.1 (POWER), J11.1 (POWER), U1.39 (VSYS), U2.39 (VSYS), U3.1 (G+)
BME280_SCL: J6.3, U2.7 (GPIO5)
BME280_SDA: J6.4, U2.6 (GPIO4)
CLK: J2.14, U1.14 (GPIO10)
CO2_PWM: U2.20 (GPIO15), U3.4 (PWM_1KHZ)
CO2_UART_RX: U2.15 (GPIO11), U3.8 (UART_RXD)
CO2_UART_TX: U2.14 (GPIO10), U3.7 (UART_TXD)
D0: J1.16, U1.25 (GPIO19)
D1 / RTC_SDA: J1.15, U1.26 (GPIO20)
D2 / RTC_SCL: J1.14, U1.27 (GPIO21)
DC_CS/D3: J1.12, U1.29 (GPIO22)
GND: C1.2, J1.3, J1.8, J1.13, J1.18, J2.3, J2.8, J2.13, J2.18, J4.1, J6.2, J7.3, J8.4, J10.2 (GND_1), J10.3 (GND_2), J11.2 (GND_1), J11.3 (GND_2), SW1.2, U1.3 (GND), U1.8 (GND), U1.13 (GND), U1.18 (GND), U1.23 (GND), U1.28 (GND), U1.33 (AGND), U1.38 (GND), U2.3 (GND), U2.8 (GND), U2.13 (GND), U2.18 (GND), U2.23 (GND), U2.28 (GND), U2.33 (AGND), U2.38 (GND), U3.2 (G0), U4.8 (GND)
HC12_RX: J8.3, U2.11 (GPIO8)
HC12_SET_PIN: J8.1, U2.5 (GPIO3)
HC12_TX: J8.2, U2.12 (GPIO9)
HKW581_CLK_IN: J4.2, U2.24 (GPIO18), U4.7 (CLK_IN)
HKW581_CLK_OUT: J3.3, U2.25 (GPIO19), U4.3 (CLK_OUT)
HKW581_DIN: J3.2, U2.21 (GPIO16), U4.2 (DATA_IN)
HKW581_DOUT: J4.3, U2.22 (GPIO17), U4.6 (DATA_OUT)
HKW581_RDY: J4.4, U2.26 (GPIO20), U4.5 (RDY)
LCD_BL: J2.17, U1.17 (GPIO13)
LCD_CS: J2.12, U1.12 (GPIO9)
LCD_DC: J2.11, U1.11 (GPIO8)
LCD_RST: J2.20, U1.20 (GPIO15)
MISO: J2.16, U1.16 (GPIO12)
MOSI: J2.15, U1.15 (GPIO11)
unnamed: J3.4, J5.1, U4.4 (RST)
unnamed: J7.2, U3.5 (BCAL_IN)
PICO_COM_MISO: U1.2 (GPIO1), U2.1 (GPIO0)
PICO_COM_MOSI: U1.1 (GPIO0), U2.2 (GPIO1)
PICO_RESET: J1.11, SW1.1, U1.30 (RUN), U2.30 (RUN)
RTC_SCL_ALT: J2.10, U1.10 (GPIO7)
RTC_SDA_ALT: J2.9, U1.9 (GPIO6)
SDIO_CLK: J2.7, U1.7 (GPIO5)
SDIO_CMD: J1.17, U1.24 (GPIO18)
TP_CS: J1.20, U1.21 (GPIO16)
TP_IRQ: J1.19, U1.22 (GPIO17)

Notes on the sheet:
HKW581 Meteotime Decoder
Display control
BME280 Shield Adapter
HC-12 433 MHz Module
Power connector
Sensor control
Reset button for both Pis
These Pinheaders are for structure support to avoid bending
MH-Z19C CO2 Sensor

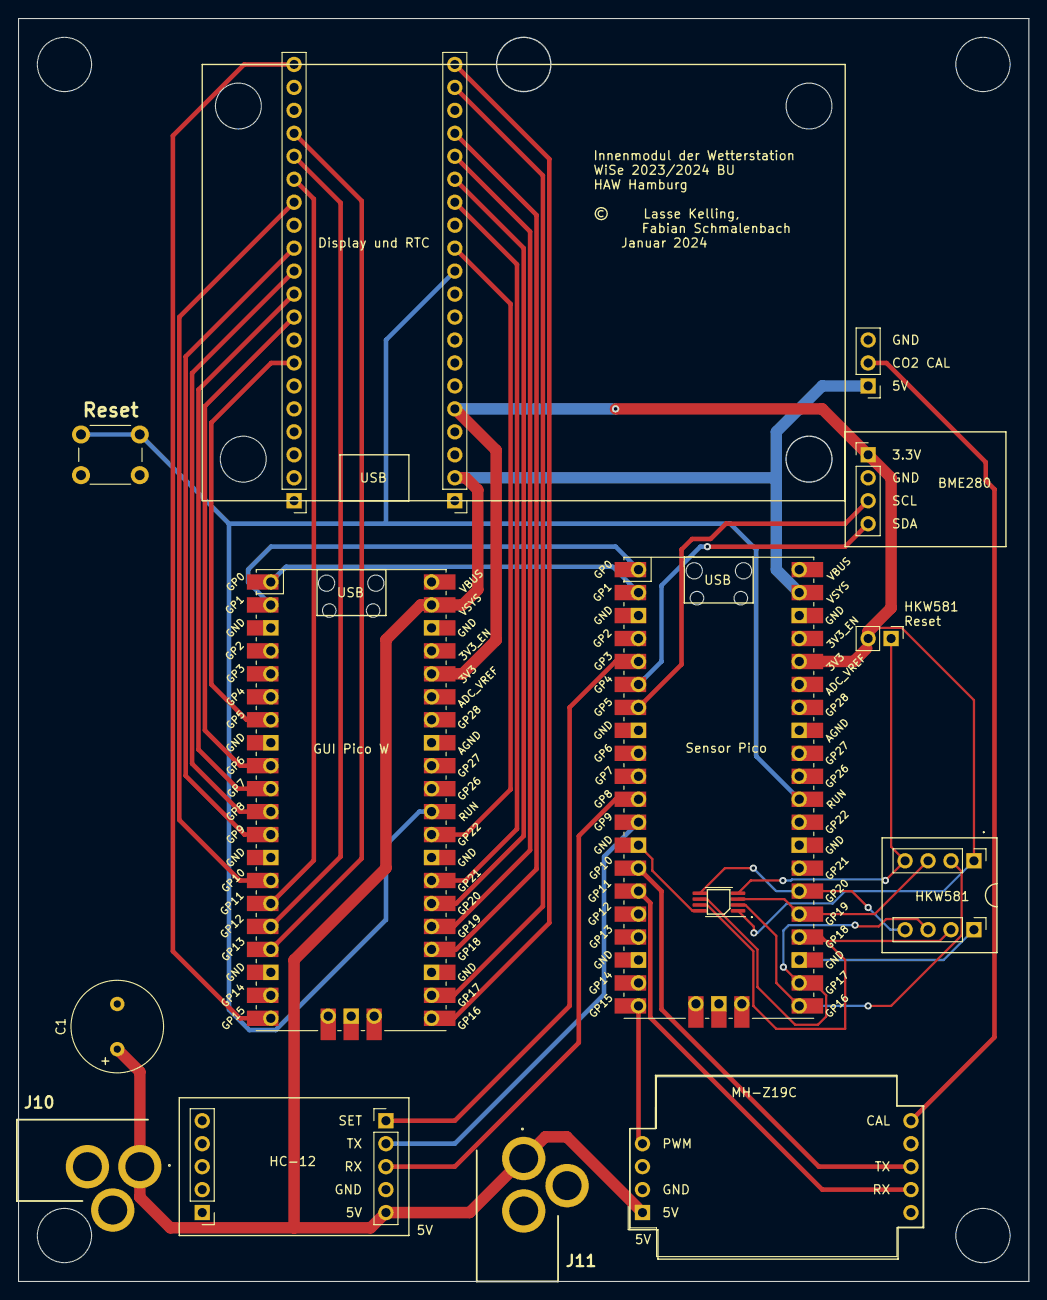
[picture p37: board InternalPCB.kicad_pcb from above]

Board: 2 copper layers, 111.8 x 139.7 mm, 17 parts (0 on the bottom side), 38 nets.

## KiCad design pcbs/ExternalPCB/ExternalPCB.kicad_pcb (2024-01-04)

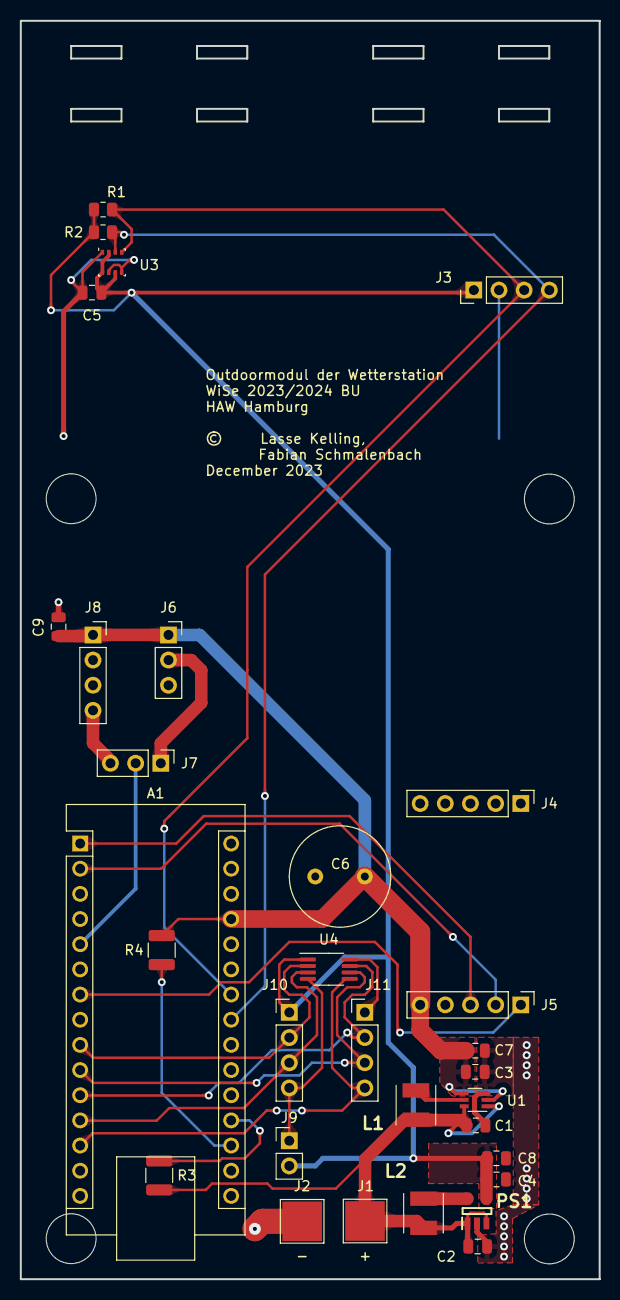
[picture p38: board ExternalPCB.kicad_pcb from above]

Board: 2 copper layers, 58.4 x 127.0 mm, 31 parts (0 on the bottom side), 22 nets.

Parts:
A1: Arduino_Nano_Every; Arduino_Nano
C1, C2: 22u; C_0805_2012Metric
C3, C4: 10u; C_0805_2012Metric
C5, C7, C8, C9: 100n; C_0805_2012Metric
C6: 1000u; C_Radial_D10.0mm_H16.0mm_P5.00mm
J1: Bat +; TestPoint_Pad_4.0x4.0mm
J2: Bat -; TestPoint_Pad_4.0x4.0mm
J3, J10, J11: Conn_01x04_Pin; PinHeader_1x04_P2.54mm_Vertical
J4, J5: Conn_01x05_Pin; PinHeader_1x05_P2.54mm_Vertical
J6: Conn_01x03_Pin; PinSocket_1x03_P2.54mm_Vertical
J7: Conn_01x03_Pin; PinHeader_1x03_P2.54mm_Vertical
J8: Conn_01x04_Pin; PinSocket_1x04_P2.54mm_Vertical
J9: Conn_01x02_Pin; PinHeader_1x02_P2.54mm_Vertical
L1, L2: LQH44PN4R7MJ0L; LQH44PN100MJ0L
PS1: TPS61097A-33DBVR; SOT95P280X145-5N
R1, R2: 4.7k; R_0805_2012Metric
R3, R4: 0; R_1210_3225Metric
U1: TPS61222DCK; Texas_R-PDSO-G6
U3: BME280; Bosch_LGA-8_2.5x2.5mm_P0.65mm_ClockwisePinNumbering
U4: MSOP-8_3x3mm_P0.65mm

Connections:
+3.3V: C4.1, C5.1, C8.1, J3.1, J9.2, J10.1, PS1.4 (VOUT), R1.1, R2.1, U3.2 (CSB), U3.6 (VDDIO), U3.8 (VDD), U4.1 (VCC)
+5V: A1.27 (+5V), C3.1, C6.1, C7.1, C9.1, J5.5, J6.1, J8.1, R4.2, U1.2 (FB), U1.4 (VOUT)
+BATT: C1.1, C2.1, J1.1, L1.1, L2.1, PS1.1 (VIN), PS1.3 (EN), R3.2, U1.1 (VIN), U1.6 (EN)
-BATT: A1.4 (GND), A1.29 (GND), C1.2, C2.2, C3.2, C4.2, C5.2, C6.2, C7.2, C8.2, C9.2, J2.1, J3.2, J5.4, J6.3, J8.2, J8.3, J11.1, PS1.2 (GND), U1.3 (GND), U3.1 (GND), U3.5 (SDO), U3.7 (GND), U4.8 (GND)
BATTERY_VOLTAGE: A1.19 (A0), R3.1
DCF_DATA: A1.5 (D2), J7.2
HC12_RX: A1.1 (TX1), J5.3
HC12_SET_PIN: A1.7 (D4), J5.1
HC12_TX: A1.2 (RX1), J5.2
HKW581_CLK_IN: A1.11 (D8), J11.2, U4.7 (CLK_IN)
HKW581_CLK_OUT: A1.12 (D9), J10.3, U4.3 (CLK_OUT)
HKW581_DATA_IN: A1.9 (D6), J10.2, U4.2 (DATA_IN)
HKW581_DATA_OUT: A1.10 (D7), J11.3, U4.6 (DATA_OUT)
HKW581_RDY: A1.13 (D10), J11.4, U4.5 (RDY)
I2C_SCL: A1.24 (SCL/A5), J3.3, R1.2, U3.4 (SCK)
I2C_SDA: A1.23 (SDA/A4), J3.4, R2.2, U3.3 (SDI)
unnamed: J6.2, J7.1
unnamed: J7.3, J8.4
unnamed: J9.1, J10.4, U4.4 (RST)
unnamed: L2.2, PS1.5 (L)
unnamed: L1.2, U1.5 (L)
REF_VOLTAGE: A1.18 (AREF), R4.1

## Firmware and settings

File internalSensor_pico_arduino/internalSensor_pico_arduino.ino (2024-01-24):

/*
 *  Created by faschmali
 *  Libs required: Adafruit BME280, Adafruit unified Sensors, CRC by Rob Tilaart
 */

#include <stdio.h>
#include <cstring>
#include <Wire.h>
#include <Adafruit_Sensor.h>
#include <Adafruit_BME280.h>
#include <CRC.h>
#include <CRC8.h>
#include "CO2.h"
#include "DataTypes.h"

// Pindefs running on core0
#define UART0_TX        0
#define UART0_RX        1

#define HC12_TX         8
#define HC12_RX         9
#define HC12_SET_PIN    3

#define CO2_PWM_PIN     15

#define BME_SEND_FREQUENCY_MILLIS   30000
#define CO2_SEND_FREQUENCY_MILLIS   15000

#define READ_TIMEOUT    100 // Timeout value after which the uC stops polling for Serial data from HC12

Adafruit_BME280 bme;    // BME280, read by core0
CO2 co2(CO2_PWM_PIN, MHZ19C, CO2::RANGE_5K);
CO2SendBuf co2Buffer = {'C','O','2','.'};
BMESendBuf iBmeBuffer = {'I','B','M','E'};

BMESendBuf eBmeBuffer;
MeteoDecodedSendBuf meteoReceiveBuffer;
TimeSendBuf timeBuffer;

bool bmeAvailable = true;

volatile bool co2Ready = false;
volatile int co2Concentration = 0;

unsigned long lastBmeSend = 0;
unsigned long lastCo2Send = 0;

CRC8 crc;

void setup()
{
    char hcAnswerArray[9] = {0};
    // Start usb debug output
    Serial.begin(115200);
    // Start COM with other pico
    Serial1.setRX(UART0_RX);
    Serial1.setTX(UART0_TX);
    Serial1.begin(115200);
    // Start COM with HC12
    Serial2.setRX(HC12_RX);
    Serial2.setTX(HC12_TX);
    Serial2.begin(9600);

    // Init BME280
    if (!bme.begin(0x76))
    {
        bmeAvailable = false;
        Serial.println("No sensor found.");
    }
    else
    {
        Serial.println("Found bme.");
    }

    pinMode(HC12_SET_PIN, OUTPUT);

    // Set Baudrate to 9600
    delay(100);
    Serial2.print("AT+B9600");
    if (Serial2.available())
    {
        Serial2.readBytes(hcAnswerArray, 8);
    }
    hcAnswerArray[8] = '\0';
    Serial.println(hcAnswerArray);

    // Set Channel to 1
    delay(100);
    Serial2.print("AT+C001");
    if (Serial2.available())
    {
        Serial2.readBytes(hcAnswerArray, 8);
    }
    hcAnswerArray[8] = '\0';
    Serial.println(hcAnswerArray);

    // Set transmission mode to 3
    delay(100);
    Serial2.print("AT+FU3");
    if (Serial2.available())
    {
        Serial2.readBytes(hcAnswerArray, 8);
    }
    hcAnswerArray[5] = '\0';
    Serial.println(hcAnswerArray);

    // Set Power to 14dBm
    delay(100);
    Serial2.print("AT+P6");
    if (Serial2.available())
    {
        Serial2.readBytes(hcAnswerArray, 8);
    }
    hcAnswerArray[5] = '\0';
    Serial.println(hcAnswerArray);
    delay(100);

    // Set data transmission to 8 bits + odd parity + 1 stop bit
    Serial2.print("AT+U8N1");
    if (Serial2.available())
    {
        Serial2.readBytes(hcAnswerArray, 8);
    }
    hcAnswerArray[5] = '\0';
    Serial.println(hcAnswerArray);

    // Disable Setting Mode in HC-12
    pinMode(HC12_SET_PIN, INPUT);
}

void setup1()
{
}

void loop()
{
    if (Serial2.available())
    {
        bool packetValid = true;
        char receiveBuffer[100] = {'\0'};
        char header[5] = {'\0'};
        int readIndex = 0;
        int readingSize = 0;

        // Isolate header of packet
        for(int i = 0; i < 4; i++)
        {
            receiveBuffer[readIndex++] = (char)Serial2.read();
            header[i] = receiveBuffer[readIndex - 1];
            delay(5);
        }
        String headerString(header);

        // Set datalength to be read
        if (headerString.equals("EBME"))
        {
            readingSize = sizeof(eBmeBuffer) - 4;
        }
        else if (headerString.equals("TIME"))
        {
            readingSize = sizeof(timeBuffer) - 4;
        }
        else if (headerString.equals("MTEO"))
        {
            readingSize = sizeof(meteoReceiveBuffer) - 4;
        }
        else
        {
            Serial.println("Received invalid message");
            // Clear buffer and print data if there were invalid ones
            do
            {
                Serial.print((char)Serial2.read());
                delay(1);
            } while (Serial2.available());
        }

        bool readTimeout = false;
        // Read rest of datapacket
        for(int i = 0; i < readingSize; i++)
        {
            // Read byte
            if (Serial2.available())
            {
                receiveBuffer[readIndex++] = (char)Serial2.read();
                delay(2);
            }
            else
            {
                // Wait until data are ready or Timeout triggered
                int readTime = millis();
                while(!Serial2.available())
                {
                    if ((millis() - readTime) > READ_TIMEOUT)
                    {
                        readTimeout = true;
                        break;
                    }
                    delay(10);
                }
            }

            // Stop reading if timeout appeared
            if (readTimeout)
            {
                break;
            }
        }
        crc.restart();

        if (headerString.equals("EBME"))
        {
            // Copy data
            memcpy(eBmeBuffer.buf, receiveBuffer, sizeof(eBmeBuffer));  
            // Check if checksums match        
            crc.add((const uint8_t*)eBmeBuffer.buf, sizeof(eBmeBuffer));
            if (crc.calc() != 0x00)
            {
                Serial.println("Checksum invalid on EBME Packet. Initiate retransmission");
                packetValid = false;
            }
            else
            {
                Serial.println("Received valid EBME Packet.");
                Serial.print("Temperature: ");
                Serial.println(eBmeBuffer.data.temp);
                Serial.print("Humidity: ");
                Serial.println(eBmeBuffer.data.humidity);
                Serial.print("Pressure: ");
                Serial.println(eBmeBuffer.data.pressure);
                Serial1.write((const uint8_t*)eBmeBuffer.buf, sizeof(eBmeBuffer) - 1);
            }
        }
        else if (headerString.equals("TIME"))
        {
            // Copy data
            memcpy(timeBuffer.buf, receiveBuffer, sizeof(timeBuffer));
            // Check if checksums match
            crc.add((const uint8_t*)timeBuffer.buf, sizeof(timeBuffer));
            if (crc.calc() != 0x00)
            {
                Serial.println("Checksum invalid on Time Packet. Initiate retransmission");
                packetValid = false;
            }
            else
            {
                Serial.println("Received valid Time packet.");
                Serial.print("Hour: ");
                Serial.println(timeBuffer.data.hour);
                Serial.print("Minute: ");
                Serial.println(timeBuffer.data.minute);
                Serial.print("Second: ");
                Serial.println(timeBuffer.data.second);
                Serial.print("Year: ");
                Serial.println(timeBuffer.data.year);
                Serial.print("Month: ");
                Serial.println(timeBuffer.data.month);
                Serial.print("Day: ");
                Serial.println(timeBuffer.data.day);
                Serial.print("Weekday: ");
                Serial.println(timeBuffer.data.weekDay);
                Serial1.write((const uint8_t*)timeBuffer.buf, sizeof(timeBuffer) - 1);
            }
        }
        else if (headerString.equals("MTEO"))
        {
            // Copy data
            memcpy(meteoReceiveBuffer.buf, receiveBuffer, sizeof(meteoReceiveBuffer));
            // Check if checksums match
            crc.add((const uint8_t*)meteoReceiveBuffer.buf, sizeof(meteoReceiveBuffer));
            if (crc.calc() != 0x00)
            {
                Serial.println("Checksum invalid on Meteopacket. Initiate retransmission");
                packetValid = false;
            }
            else
            {
                Serial.print("Received meteodata: ");
                Serial.println(meteoReceiveBuffer.data.meteoData, BIN);
                Serial1.write((const uint8_t*)meteoReceiveBuffer.buf, sizeof(meteoReceiveBuffer) - 1);
            }
        }
        else
        {
            packetValid = false;
        }

        // Send errormessage to outdoor module to initate retransmission
        if (!packetValid)
        {
            Serial2.print("ERRORERRORERROR");
        }
    }
    // Send CO2 data if sensor is ready
    if (((millis() - lastCo2Send) > CO2_SEND_FREQUENCY_MILLIS) && co2Ready)
    {
        co2Buffer.data.concentration = co2Concentration;
        Serial1.write((const uint8_t*)co2Buffer.buf, sizeof(co2Buffer));
        lastCo2Send = millis();
        Serial.print("Sent Co2 data. Concentration is: ");
        Serial.println(co2Buffer.data.concentration);
    }
    // Send BME data if sensor is available
    if (((millis() - lastBmeSend) > BME_SEND_FREQUENCY_MILLIS) && bmeAvailable)
    {
        iBmeBuffer.data.temp = bme.readTemperature();
        iBmeBuffer.data.humidity = bme.readHumidity();
        iBmeBuffer.data.pressure = bme.readPressure() / 100.0;
        Serial1.write((const uint8_t*)iBmeBuffer.buf, sizeof(iBmeBuffer));
        lastBmeSend = millis();
        Serial.println("Sent internal BME data.");
        Serial.print("Temperature: ");
        Serial.println(iBmeBuffer.data.temp);
        Serial.print("Humidity: ");
        Serial.println(iBmeBuffer.data.humidity);
        Serial.print("Pressure: ");
        Serial.println(iBmeBuffer.data.pressure);
    }
}

void loop1()
{
    // Wait until sensor is heated up
    if (!co2Ready)
    {
        co2Ready = co2.isReady();
        if (co2Ready)
        {
            Serial.println("CO2 is ready!");
        }
    }
    else
    {
        // Read CO2 concentration using PWM
        co2Concentration = co2.readCO2PWM();
        //Serial.print("Got new CO2 value: ");
        //Serial.println(co2Concentration);
    }
}

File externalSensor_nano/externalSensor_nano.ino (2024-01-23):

/*
 *  Created by faschmali
 */

#include <TimeLib.h>
#include <Wire.h>
#include <Adafruit_Sensor.h>
#include <Adafruit_BME280.h>
#include <CRC.h>
#include <CRC8.h>
#include "DCF77.h"
#include "DataTypes.h"
#include "Meteo.h"

#define DCF_DATA_PIN 2      // D2
#define DCF_INTERRUPT_PIN 2 // D2
#define SET_PIN 4          // D4

// Send bme data every 30 seconds to reduce collision probability with time or meteo packets
#define SENSOR_SEND_FREQUENCY_MILLIS 30000

#define NUMBER_OF_RETRANSMISSIONS   5       // Resend a packet max. 5 times
// A retransmission command has to be sent max. 3 seconds after a packet has been sent. 
#define PACKET_RETRANSMISSION_TIME  3000

Adafruit_BME280 bme;
DCF77 DCF = DCF77(DCF_DATA_PIN, DCF_INTERRUPT_PIN, false);

TimeSendBuf timeBuffer = {'T', 'I', 'M', 'E'};
BMESendBuf sensorBuffer = {'E', 'B', 'M', 'E'};

MeteoDecodedSendBuf meteoBuffer;
Meteo meteo;

bool bmeAvailable = false;

unsigned long lastSensorSend = 0;
unsigned long lastTimeSend = 0;

bool timePacketValid = true;
bool meteoPacketValid = true;
bool bmePacketValid = true;

bool timePacketPending = false;
bool meteoPacketPending = false;
bool bmePacketPending = false;

int timeResendCounter = 0;
int meteoResendCounter = 0;
int bmeResendCounter = 0;

int timeRetransTime = 0;
int meteoRetransTime = 0;
int bmeRetransTime = 0;

CRC8 crc;

void setup()
{
    Serial.begin(9600);

    // Start I2C communication
    bmeAvailable = true;
    if (!bme.begin(0x76))
    {
        bmeAvailable = false;
        //Serial.println("No sensor found");
    }
    else
    {
        //Serial.println("Found BME280");
    }

    // Initialize Pins for Meteodecoder
    pinMode(METEO_DATA_IN, OUTPUT);
    pinMode(METEO_DATA_OUT, INPUT);
    pinMode(METEO_CLK_IN, OUTPUT);
    pinMode(METEO_CLK_OUT, INPUT);
    pinMode(METEO_RDY, INPUT);
    digitalWrite(METEO_DATA_IN, LOW);
    digitalWrite(METEO_CLK_IN, LOW);

    // Enable Setting Mode in HC-12
    pinMode(SET_PIN, OUTPUT);
    digitalWrite(SET_PIN, LOW);

    // Set Baudrate to 9600
    delay(100);
    Serial.print("AT+B9600");
    delay(100);
    while(Serial.available())
    {
        Serial.read();
        delay(10);
    }

    // Set Channel to 1
    delay(100);
    Serial.print("AT+C001");
    delay(100);
    while(Serial.available())
    {
        Serial.read();
        delay(10);
    }

    // Set transmission mode to 3
    delay(100);
    Serial.print("AT+FU3");
    delay(100);
    while(Serial.available())
    {
        Serial.read();
        delay(10);
    }

    // Set Power to 14dBm
    delay(100);
    Serial.print("AT+P6");
    delay(100);
    while(Serial.available())
    {
        Serial.read();
        delay(10);
    }

    // Set data transmission to 8 bits + no parity + 1 stop bit
    Serial.print("AT+U8N1");
    delay(100);
    while(Serial.available())
    {
        Serial.read();
        delay(10);
    }
    //Serial.println("");

    // Disable Setting Mode in HC-12
    pinMode(SET_PIN, INPUT);

    // Reset timestamps for timer
    lastSensorSend = millis();
    lastTimeSend = millis();
    // Start DCF Time detection
    DCF.Start();
}

void loop()
{
    // Try to get updated DCF time
    time_t DCFtime = DCF.getTime();
    if (DCFtime != 0)
    {
        timeBuffer.data.hour = hour(DCFtime);
        timeBuffer.data.minute = minute(DCFtime);
        timeBuffer.data.second = 0;
        timeBuffer.data.year = year(DCFtime);
        timeBuffer.data.month = month(DCFtime);
        timeBuffer.data.day = day(DCFtime);
        if (weekday(DCFtime) == 1)
        {
            timeBuffer.data.weekDay = 7;
        }
        else
        {
            timeBuffer.data.weekDay = weekday(DCFtime) - 1;
        }
        // Calculate Checksum and store it in the sending struct
        crc.restart();
        crc.add((const uint8_t*)timeBuffer.buf, sizeof(timeBuffer) - 1);
        timeBuffer.data.checksum = crc.calc();
        // Send data
        Serial.write((const uint8_t *)timeBuffer.buf, sizeof(timeBuffer));
        timeResendCounter = 0;
        timePacketPending = true;
        timePacketValid = true;
        timeRetransTime = millis();
        lastSensorSend = millis() - 15000;
    }
    // Resend time data if packet has been sent and an error message was received
    if (!timePacketValid)
    {
        Serial.write((const uint8_t *)timeBuffer.buf, sizeof(timeBuffer));
        timePacketValid = true;
        timeResendCounter++;
    }

    // Send meteodata if available
    if (DCF.isMeteoReady())
    {
        meteo.getNewData(DCF.getMeteoBuffer());
    }
    if (meteo.isNewMeteo() && !digitalRead(METEO_RDY) && !timePacketPending && !bmePacketPending)
    {
        meteo.decode();
        if (meteo.isMeteoValid())
        {
            meteoBuffer = meteo.getConvertedBuffer();
            crc.restart();
            crc.add((const uint8_t*)meteoBuffer.buf, sizeof(meteoBuffer) - 1);
            meteoBuffer.data.checksum = crc.calc();
            Serial.write((const uint8_t *)meteoBuffer.buf, sizeof(meteoBuffer));
            meteoResendCounter = 0;
            meteoPacketPending = true;
            meteoPacketValid = true;
            meteoRetransTime = millis();
        }
    }
    // Resend meteopacket if checksum was incorrect at receiver
    if (!meteoPacketValid)
    {
        Serial.write((const uint8_t *)meteoBuffer.buf, sizeof(meteoBuffer));
        meteoPacketValid = true;
        meteoResendCounter++;
    }

    // Send BME Data if sensor is available
    if (((millis() - lastSensorSend) > SENSOR_SEND_FREQUENCY_MILLIS) && bmeAvailable)
    {
        // Send sensor data
        sensorBuffer.data.temp = bme.readTemperature();
        sensorBuffer.data.humidity = bme.readHumidity();
        sensorBuffer.data.pressure = bme.readPressure() / 100.0;
        crc.restart();
        crc.add((const uint8_t*)sensorBuffer.buf, sizeof(sensorBuffer) - 1);
        sensorBuffer.data.checksum = crc.calc();
        Serial.write((const uint8_t *)sensorBuffer.buf, sizeof(sensorBuffer));
        //Serial.println("Sent BME Data");
        bmeResendCounter = 0;
        bmePacketPending = true;
        bmePacketValid = true;
        bmeRetransTime = millis();
        lastSensorSend = millis();
    }
    // Resend bme data if they were invalid
    if (!bmePacketValid)
    {
        Serial.write((const uint8_t *)sensorBuffer.buf, sizeof(sensorBuffer));
        bmePacketValid = true;
        bmeResendCounter++;
    }
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

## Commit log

2023-10-24 so konfiguriert man eine I2C-Schnittstelle per TivaC, theoretisch
2023-10-25 die in-Properties können jetzt aus rust angesprochen werden
2023-10-27 Werte aktualisieren sich jetzt in der GUI
2023-11-04 kleine Anpassungen, um BME280 und CCS811 Sensordaten abzufragen
2023-11-04 TI µC wird nicht verwendet, Projekt entfällt
2023-11-05 Ungetesteter Code für ein Touchscreen an einem Raspberry Pico
2023-11-19 Added arduino libs
    [project.cfg]
2023-11-19 Fixed minor but ugly formatting mistake
    [dcf77-arduinotest.ino]
2023-11-20 Initialpush Slint-pico
2023-11-25 Bisschen in der Ausarbeitung tüddeln
2023-11-26 rp-pico BoardSupport-Package von v0.5 auf v0.8
2023-11-29 Jetzt mit Touch und DMA
2023-11-29 Co2 testprogram. Not working
    [co2-uart-arduinotest.ino]
2023-11-29 UART Beispielimplementierung (TX)
2023-11-29 UART Beispielimplementierung (TX & RX)
2023-12-01 Implemented external sensor device based on esp
2023-12-02 Copied dfc77 library to arduinoproject to modify it
2023-12-02 Restructured arduino programs
2023-12-02 Removed irrelevant libs
    [project.cfg]
2023-12-02 Added datatype for co2 sensor
2023-12-02 Fixed bug and changed transmission mode
    [externalSensor_esp.ino]
2023-12-02 Testprogram with all sensors
2023-12-03 Die DMA + Touch Variante kann jetzt ebenfalls UART und I2C
2023-12-04 Interner BME und CO2 Sensor funktionieren jetzt
2023-12-06 Kleiner Hotfix am Morgen vertreibt Kummer und Sorgen
2023-12-10 Added meteo decoder and changed to arduino nano
2023-12-11 alles außer CO2 wird jetzt angezeigt
2023-12-11 Changed power settings
2023-12-12 Created Pico on Arduino IDE
2023-12-14 Bei LandscapeSwapped wird Touch mit invertiert
    Die Bildschirm-Orientierung kann somit wieder auf LandscapeSwapped gesetzt werden.
2023-12-15 Die Wochentage auf der Wetterseite werden jetzt gesetzt
2023-12-17 UNTESTED! Added internal Sensorprogram for pi pico
2023-12-18 Switched from SoftwareSerial to native UART
2023-12-23 Switched back to SoftwareSerial
2023-12-23 Send error message when no BME Found
    [externalSensor_esp.ino]
2023-12-23 Removed sending bme error message
    [externalSensor_esp.ino]
2023-12-25 Fixed packing issue and added packet check and retransmission
    [Meteo.cpp, externalSensor_esp.ino, internalSensor_pico_arduino.ino]
2023-12-25 Enabled DCF Debugging and fixed pressure scaling
    [Utils.cpp, externalSensor_esp.ino]
2023-12-26 Fixed bugs at meteotransmission
    [DCF77.cpp, internalSensor_pico_arduino.ino]
2023-12-26 Incremented 433 Mhz Power
2023-12-28 Internal PCB schematic
    [InternalPCB.kicad_pcb, InternalPCB.kicad_sch]
2023-12-29 Higher chance of meteodata + added filter
2023-12-29 Added weekday and fixed wrong second
    [externalSensor_nano.ino, internalSensor_pico_arduino.ino]
2023-12-29 Kleiner DCF77 Encoder für den RPico
2023-12-29 PCB for external module
    [ExternalPCB.kicad_pcb, ExternalPCB.kicad_sch]
2023-12-30 Added teardrops
    [ExternalPCB.kicad_pcb]
2023-12-30 DNP BME280 IC
    [ExternalPCB.kicad_sch]
2024-01-03 Innenmodul erstes funktionales PCB
    [InternalPCB.kicad_pcb]
2024-01-03 DCF77-Pico weiter
2024-01-03 3,3V für RTC ausgeführt
    [InternalPCB.kicad_pcb, InternalPCB.kicad_sch]
2024-01-04 PCB Innenmodul verbessert
    - Löcher für Displaymontage
    - 2. Stromanschluss für Wandmontage
    - M3 Löcher für Gehäuse und Wandmontage
    - Beschriftung angepasst
    [InternalPCB.kicad_pcb, InternalPCB.kicad_sch]
2024-01-04 Elko footprint getauscht
    [InternalPCB.kicad_pcb]
2024-01-04 Bisschen DRC dies das
    [InternalPCB.kicad_pcb, InternalPCB.kicad_sch]
2024-01-04 JLCPCB hatte ein paar Teile nicht...
    [ExternalPCB.kicad_pcb, ExternalPCB.kicad_sch]
2024-01-04 Gerber files
    [ExternalPCB-B_Cu.gbl, ExternalPCB-B_Mask.gbs, ExternalPCB-B_Paste.gbp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]
2024-01-23 RTC wird jetzt über DCF77 Pakete gesetzt
2024-01-23 MeteoSim kann Meteotime Pakete und dazugehörige Zeitstempel imitieren
2024-01-23 Der Meteotime-Decoder speichert jetzt alle Teile der 4 Tage Vorhersage
2024-01-23 Optimized DCF Filter
2024-01-23 kleiner Bugfix am Meteotime Code
    [pico_backend.rs]

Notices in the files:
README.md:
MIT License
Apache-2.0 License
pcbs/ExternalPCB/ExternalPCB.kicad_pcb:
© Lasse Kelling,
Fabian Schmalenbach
